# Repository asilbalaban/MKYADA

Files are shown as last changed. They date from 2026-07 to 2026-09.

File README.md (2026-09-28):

<p align="center">
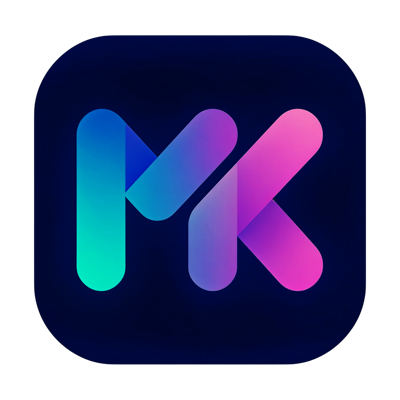
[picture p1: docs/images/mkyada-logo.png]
MKYADA logo
  
</p>

# MKYADA

**M**acro **K**eypad **Y**ou **A**lways **D**ream **A**bout — an open-source, DIY **macro keypad** (6 keys in the reference build, up to 20 supported) built on the Waveshare **RP2040-Zero**, with a cross-platform desktop configurator. It records your mouse and keyboard, then replays them as **real hardware HID input** — so your macros work even in games that ignore software automation.

**Two models, one firmware and one app:** the **Core 6** is the clean screenless keypad (RGB LED + a layer key); the **Vision 6** adds a 128×64 OLED and an EC11 rotary wheel so you can read macro names, switch layers and tune settings right on the device. See [docs/models.md](docs/models.md).

<p align="center">
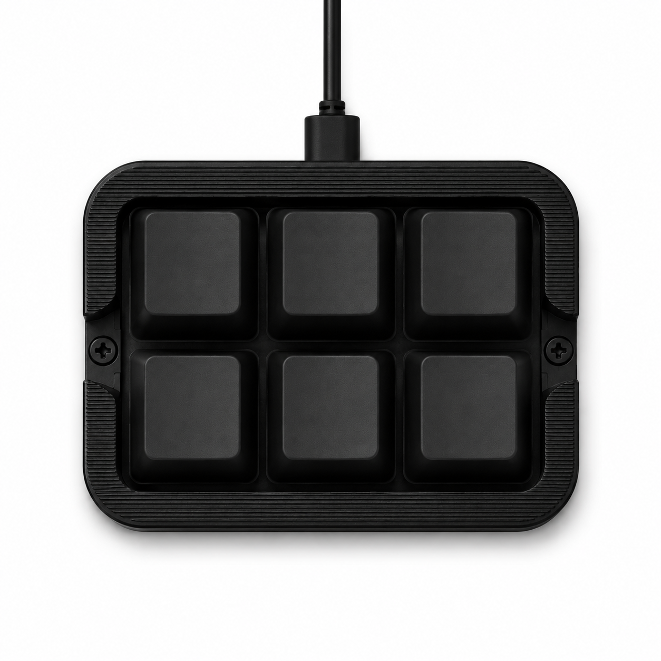
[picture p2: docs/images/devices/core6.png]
MKYADA Core 6
  
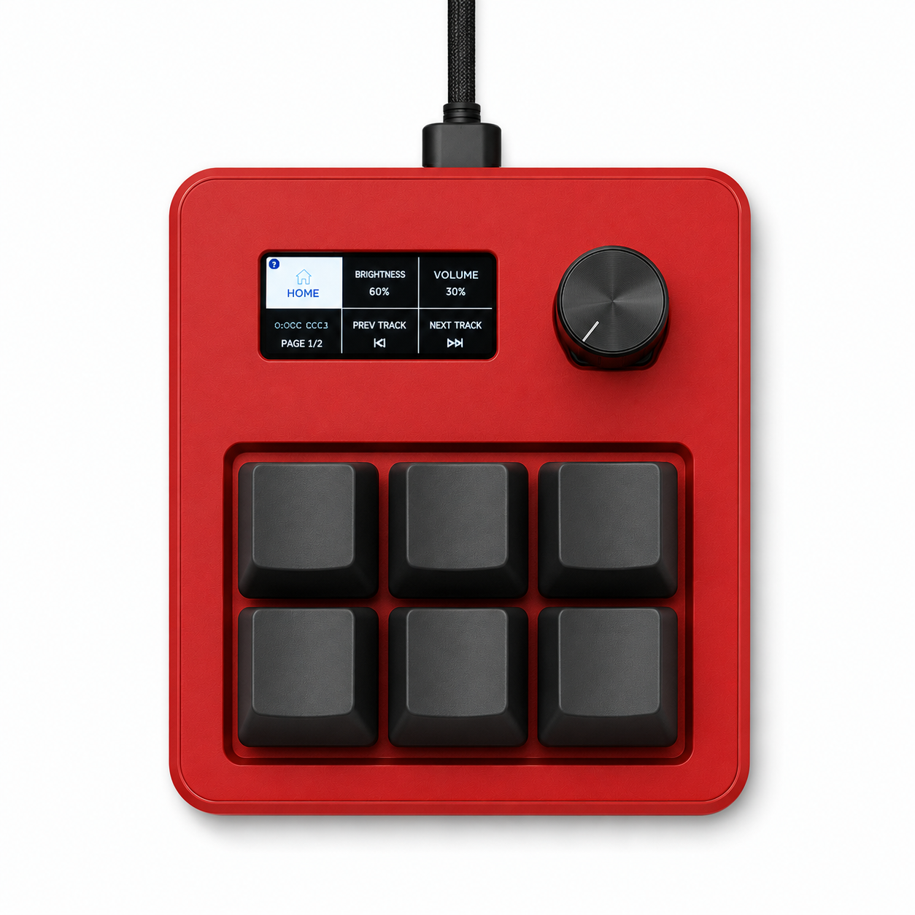
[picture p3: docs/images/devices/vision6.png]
MKYADA Vision 6 with OLED and encoder
  
</p>

```
+----------------+   serial (JSON-lines)    +---------------+    USB HID    +-----------+
|   MKYADA App   | <----------------------> |  RP2040-Zero  | ------------> |  Your PC  |
| (Tauri, W/M/L) | CIRCUITPY drive (JSON)   |   (firmware)  | kbd + mouse   |   / game  |
+----------------+ ---------------------->  +---------------+               +-----------+
```

**One repo for everything.** Build the hardware, flash the firmware, create macros, load them onto your keypad, fine-tune your recordings, and keep both the app and the firmware up to date — it all lives here.

## What do you want to do?

| I want to… | Where |
|---|---|
| **Build the keypad** (solder switches, print the case) | [hardware/wiring.md](hardware/wiring.md) · [hardware/case/](hardware/case/) |
| **Flash the firmware** on a fresh board | [docs/firmware-install.md](docs/firmware-install.md) |
| **Update the firmware** later | one click in the app (*Devices → Update firmware*) — it ships inside the app |
| **Test the keys, fix the wiring, troubleshoot** | app → *Devices*: the *Setup*, *Test keys*, *Fix wiring* and *Troubleshoot* tabs |
| **Run a key from the app, or stop a runaway loop** (also over remote desktop) | app → *Control*: click **Run** on a key, **Stop** in the bar on top, or the global stop hotkey — [remote control](#remote-control) |
| **Put an action on a key** (key, combo, text, media, launch app/file/URL, run a command, play a sound, call a webhook, or a multi-step sequence) | app → *Keys*: click the key, press the shortcut or pick an action, save |
| **Give one key three jobs** (tap / double-press / hold) | app → *Keys*: click the key, then the *Press*, *Double press* and *Long press* tabs |
| **Record a full mouse + keyboard macro** | app → *Recorder*: F8 to record, assign to a key |
| **Fine-tune a recording** | app → *Recorder*: edit every event, multi-select rows, draw the path 1:1 on your screen, pin the app above your game |
| **Different actions per application** | app → *Profiles* (e.g. Save As in Photoshop, inventory macro in your game) |
| **Configure without installing anything** | drop `macros/key1.json` onto the keypad's USB drive — [format](docs/macro-format.md) |
| **Update the app** | *Settings → About → Check for updates* (it also checks on launch) |
| **Share or grab ready-made macros** | [community-macros/](community-macros/) — PRs welcome |

## Why MKYADA?

Unlike most DIY macro pads that just remap keys, MKYADA plays back **full recorded macros — mouse movements, clicks, scrolls and keystrokes — as real hardware HID input** from the device itself. Software macro tools inject input at the OS level and often don't work inside games; MKYADA's input is indistinguishable from a physical keyboard and mouse because, electrically, that's what it is.

## Features

**On the keypad (no app needed):**
- **Standalone playback** — macros live as JSON files on the board's own USB drive. Drop `macros/key1.json` on, press the key. Works on any PC, no software installed.
- **Everything is JSON** — even a plain Ctrl+A binding is a tiny macro file. Copy it to another board and it behaves identically.
- **Tap · double-press · hold** — one key, three independently assignable actions. The firmware resolves the gesture itself, so it still works with no app running. No double-press assigned? Zero added latency on the tap.
- **Layers** — dedicate one key as a layer switch (toggle or hold): 4 keys become 3×3 = 9 macros (`key1.json`, `key1-b.json`, `key1-c.json`). A live layer badge in the app always shows which one is active. An assignable **"Go to layer X"** action jumps straight to a layer (works on the Core 6 too); the Vision 6 switches layers with the wheel, no key spent.
- **Loop mode** — `repeat: 0` plays a macro until you press its key again (grinding, fishing, inventory runs…). Same key also **panic-stops** any running macro.
- **Status LED** — the onboard RGB LED shows the active layer, playback (fast blink; slow blink while looping), host mode and errors — and can mirror app-side state like "mic muted".
- **Absolute mouse positioning** — clicks land on screen coordinates, not relative nudges, via a custom HID descriptor proven in-game.
- **Self-healing connection** — dead/reset serial ports and read-only drives are detected and recovered from automatically; nicknames are stored on the device itself so they follow it between computers.
- **MIDI out** — the keypad is a **USB MIDI device as well as a keyboard**, so a key can send a note, control change or program change straight into a DAW with nothing running on the computer. Notes are *momentary* by default (the note lasts exactly as long as the key is held — what Ableton's Looper and drum-rack pads need). A Mackie Control picker gives Logic and Pro Tools transport with no mapping at all. Nothing else at this price does both jobs: mini MIDI controllers can't send shortcuts, and stream decks can't send MIDI. Off by default — turn it on in *Settings → Keypad*.
- **Finished-product mode** — an optional setting (app → *Settings → Keypad*) hides the keypad's USB drive entirely: no flash drive, no raw JSON in sight. The app keeps full access over the serial connection. Hold key 1 while plugging in to bring the drive back.

**On the Vision 6 (screen model):**
- **On-device menu system** — a 128×64 OLED shows your six live macro names, a layer picker, a per-macro speed editor (0.1×–10.0×) and a settings menu, all driven by the **EC11 rotary wheel** with BACK/CONFIRM. No app required to read or tune your keypad.
- **Encoder + nav buttons as macro slots** — the wheel (→ / ←), its push, and BACK/CONFIRM each carry their own assignable action, per layer and per context. Great for volume, scroll/zoom or scene switching.
- **The Dial** — a key can open a **six-slot encoder toolset** on the screen: the six keys pick a slot, the wheel drives it. Slots send shortcut pairs, scroll, a relative mouse drag (for controls with no shortcut, like DaVinci's color wheels) or **MIDI CC**. Ready-made sets ship for Resolve, Premiere, Final Cut, Photoshop, Ableton, Logic, Reaper, FL Studio, a MIDI mixer and a sheet-music page turner. Fully device-native — it works with the app closed.
- **Browse and reassign on the device** — select a key and press the wheel: media and MIDI keys open a browser. Turn to walk the options (all 128 notes for MIDI), **tap to hear the highlighted one**, hold to reassign the key to it. The keypad writes its own macro, so it sticks with no app involved.
- **On-screen bands** — optional strips name the active **layer** and the desktop app's active **per-app profile**; the auto-return timeout is adjustable on the device or in the app. See [docs/vision6.md](docs/vision6.md).

**In the desktop app (Windows / macOS, Linux planned):**
- **Point-and-click key setup** — click a key, press the shortcut you want (single keys, combos, text snippets, media keys), save. *Run on keypad* tries it right away; the live key test (*Devices → Test keys*) shows every physical press.
- **Beyond keystrokes** — put a key to launching an app, file or URL, running a terminal command, playing a sound (tap to play; hold to stop, fade out, or restart it), scrolling/zooming (wheel + modifiers), controlling your microphone (mute/unmute/toggle/**push-to-talk**), driving **OBS Studio** over obs-websocket (scene, record, stream, mic, virtual cam), or calling a webhook — a fully custom HTTP request (method, headers, body) for smart lights, Discord/Telegram messages, Home Assistant and anything else with an HTTP API. Chain several of these into one multi-step sequence with delays in between. Full list: [docs/actions.md](docs/actions.md).
- **Macro recorder & editor** — record globally with F8, then edit every event: coordinates, delays, durations; straighten or simplify mouse paths; draw the path 1:1 on your real screen to verify click positions; multi-select rows with shift/cmd-click; full undo/redo.
- **Per-app profiles** — with the app running, key 1 can be *Save As* in Photoshop and an inventory macro in your game. No matching profile? The keypad falls back to its own on-board config within 5 seconds.
- **Remote control** — the *Control* page runs any key on the keypad from the app, exactly like pressing it, and a playback bar on every page stops whatever is playing. A global stop hotkey and the tray's *Stop playback* work with the window hidden. Built for driving the keypad's computer over Chrome Remote Desktop, where you can't reach the physical key. See [Remote control](#remote-control).
- **Runs in the background** — closing the window sends MKYADA to the system tray instead of quitting, so key actions and profiles keep working; an optional "start at login" setting launches it automatically.
- **Live system status** — a settings strip shows CPU, RAM and mic-mute state at a glance, with an optional rule to turn the keypad's LED red while the mic is muted.
- **In-app firmware updates**, wrong-solder-order key remapping, device nicknames, multi-device support, and a GitHub release check on launch.

## The app

| Run keys from the app (Control) | Assign keys (Vision 6) |
|---|---|
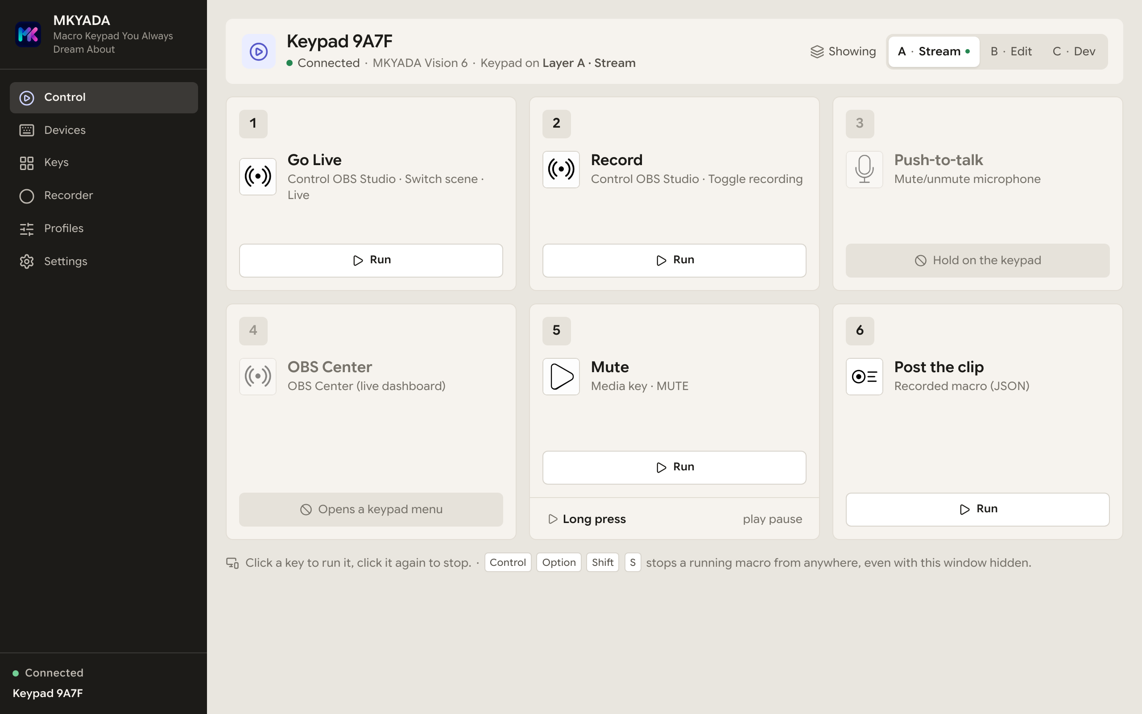
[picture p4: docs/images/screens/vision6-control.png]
Control page — every key as a tile with Run, the page the app opens on
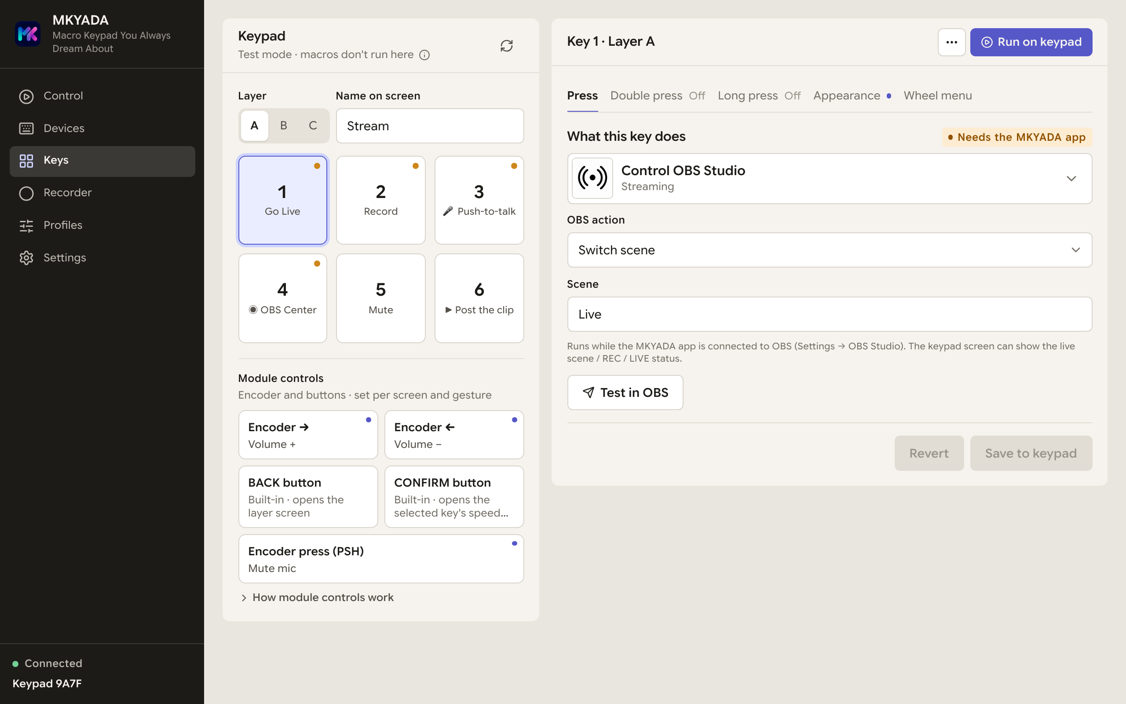
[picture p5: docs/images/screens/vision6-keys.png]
Keys page — click a key, then Press, Double press, Long press and Appearance tabs
|  |  |
| **Stop a loop from anywhere** | **Per-app profiles** |
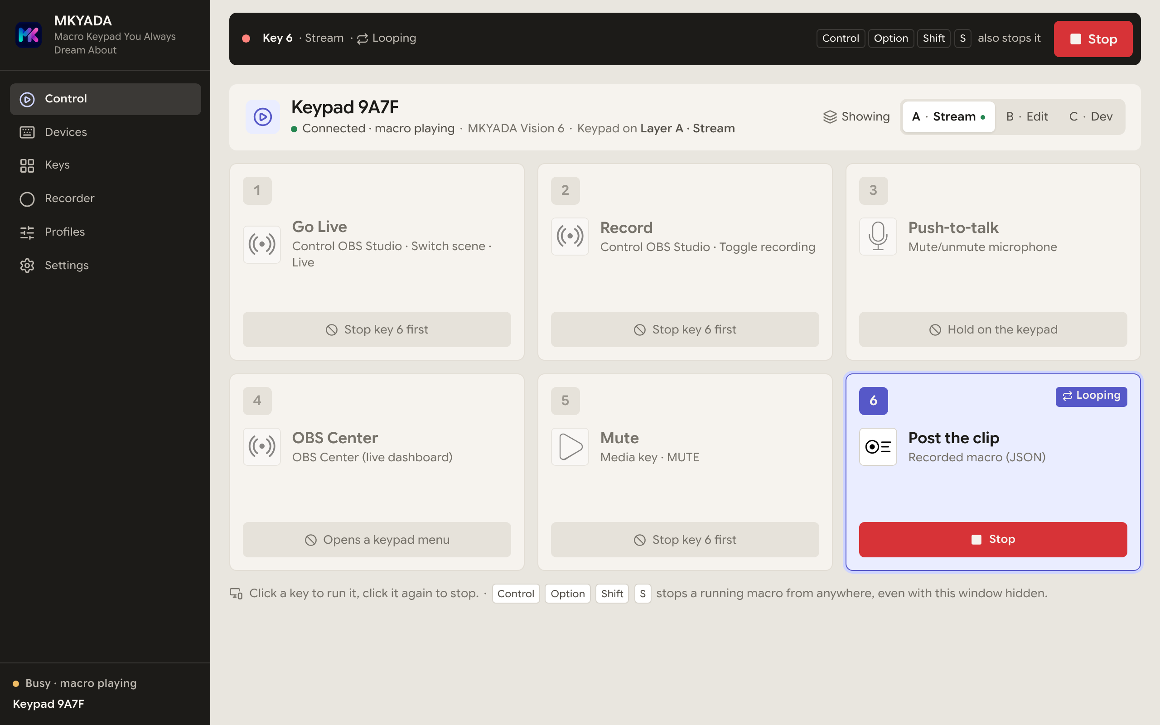
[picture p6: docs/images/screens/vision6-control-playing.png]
Control page while key 6 loops — the playback bar on top with Stop and the stop hotkey
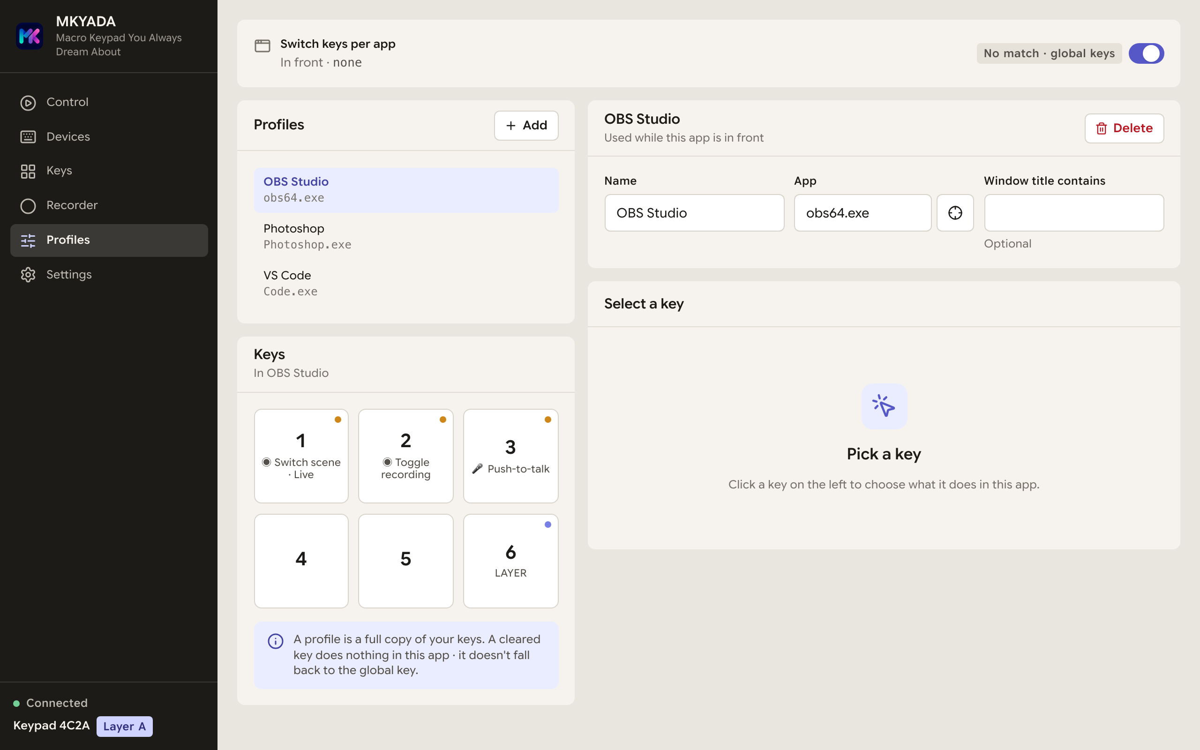
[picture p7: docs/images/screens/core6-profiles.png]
Profiles — the app in front picks the keys; each profile has its own key grid
|  |  |
| **Record & edit macros** | **Devices — setup, key test, wiring, troubleshooting** |
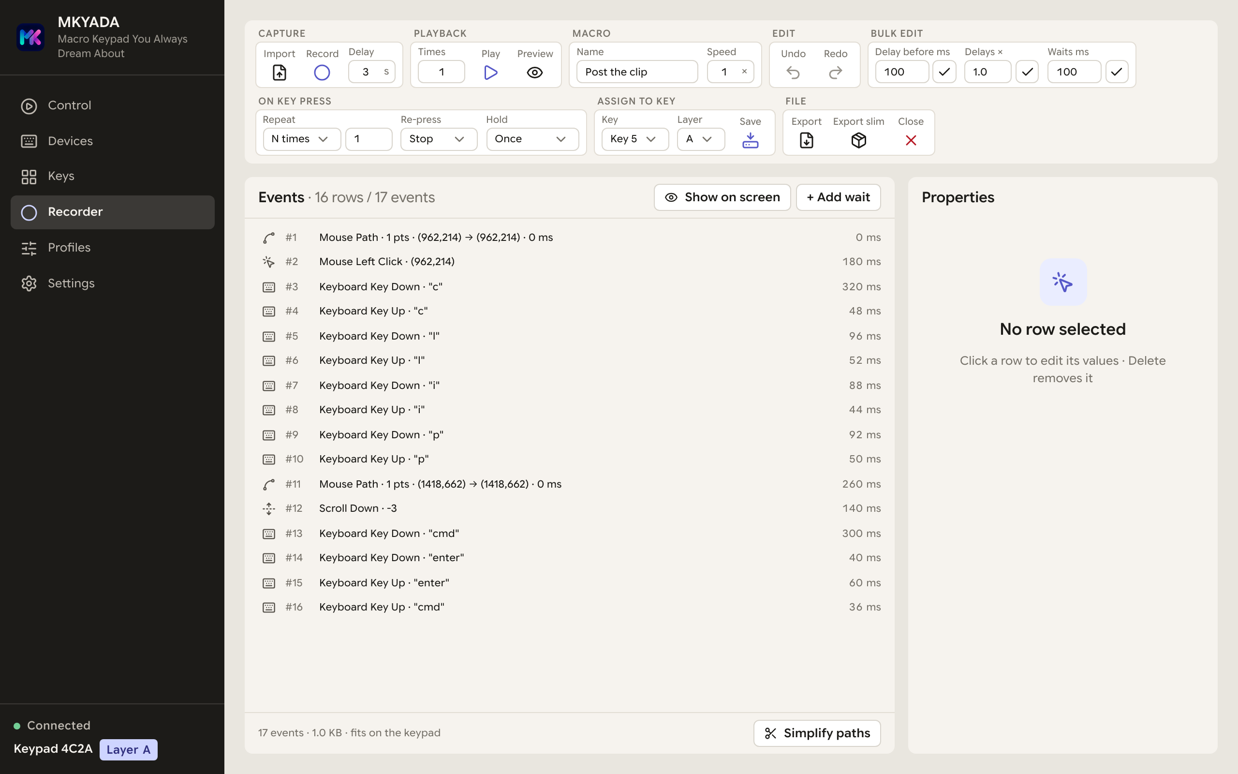
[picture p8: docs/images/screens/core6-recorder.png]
Recorder — every event is an editable row, playback rules per key
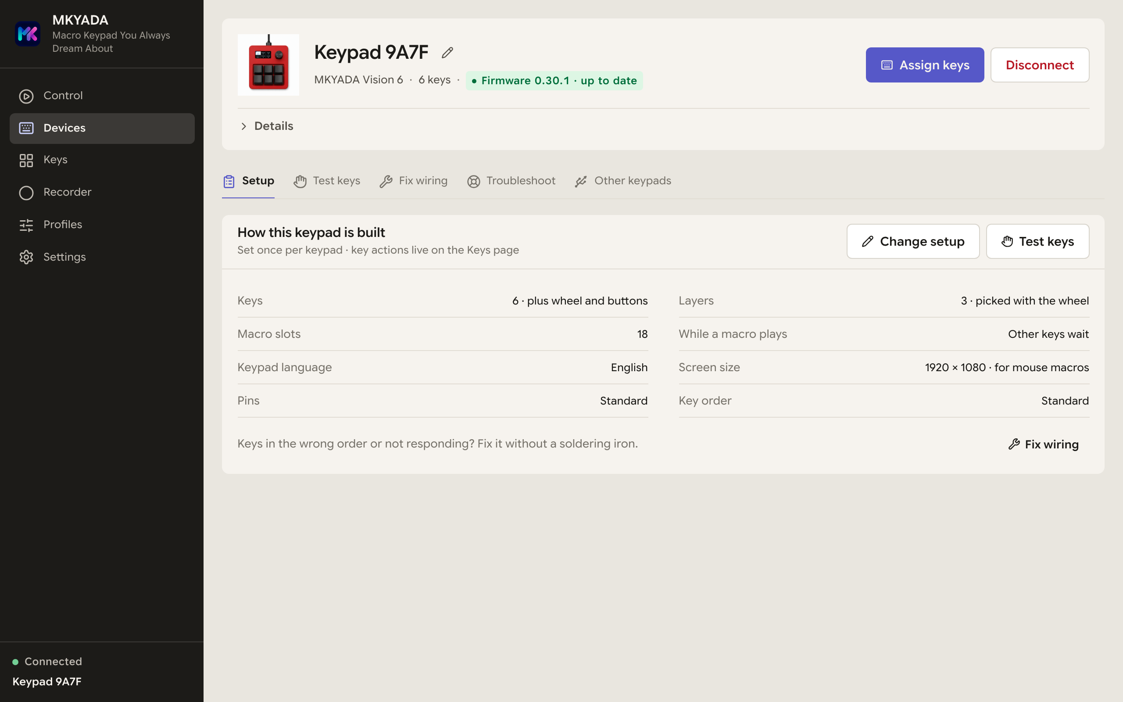
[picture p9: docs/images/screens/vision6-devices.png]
Devices page — keypad hero card with Setup, Test keys, Fix wiring, Troubleshoot and Other keypads tabs
|  |  |
| **Test every key** | **Settings — grouped into tabs** |
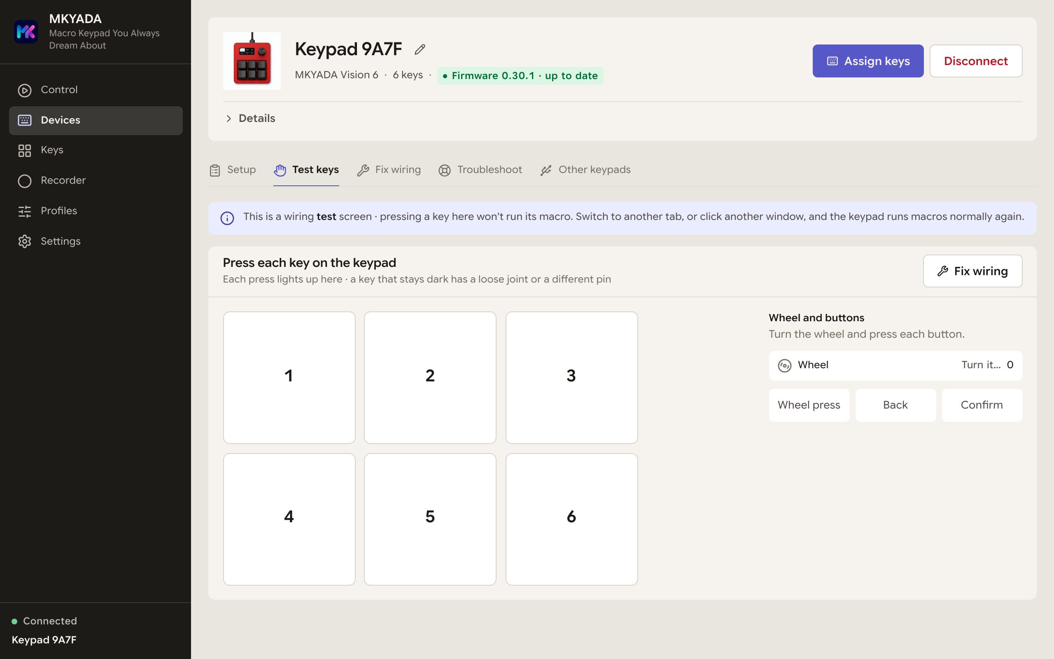
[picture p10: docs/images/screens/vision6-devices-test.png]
Devices → Test keys — each press lights up its tile
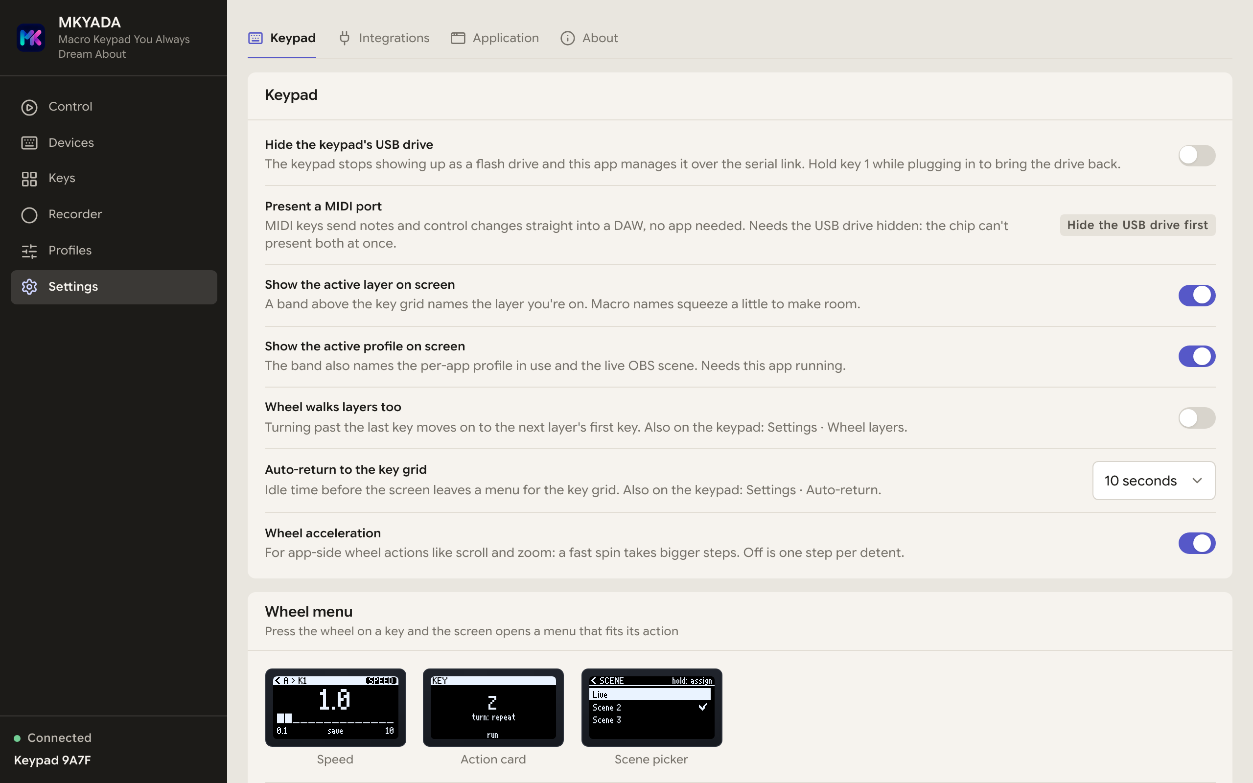
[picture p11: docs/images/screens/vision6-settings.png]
Settings — Keypad, Integrations, Application and About in tabs
|  |  |

## Remote control

A lot of MKYADA keypads sit on a computer their owner reaches over **Chrome
Remote Desktop** (or any remote desktop): a game or render box running a macro
on loop. From there you can't press the physical key, so a loop you started
would run forever. The app covers that:

- **Control page** — the first page, and the one the app opens on. Every key is
  a large tile; **Run** presses that key on the keypad remotely, exactly like a
  physical press (same macro, same loop and hold rules, still real hardware
  HID). The playing tile turns into **Stop**. Keys with a double or long press
  get their own rows, and a layer switcher shows the other layers.
- **Playback bar** — while anything plays, a bar on every page shows the key,
  its layer and whether it loops, with a **Stop** button. After a stop it offers
  **Run again**.
- **Global stop hotkey** — **Ctrl+Alt+Shift+S** by default, working with the
  window hidden or in the tray. Change it in *Settings → Application → Remote
  control*.
- **Tray** — the tray menu has **Stop playback**.
- **Paused during remote desktop** — while someone is connected over Chrome
  Remote Desktop, no macro plays (a running one stops, keys and *Run* are
  held), so the computer stays usable. When the session ends, the macro the
  connection stopped starts again. During the session, **Run** picks the key to play once it ends instead (or **Stop** to play nothing). Turn it off in *Settings → Application →
  Remote control*.

Remote run and stop need a keypad on the current firmware (serial protocol
v17); on older firmware the Control page asks for an update. The
[serial protocol](docs/serial-protocol.md) documents `press`, `stop` and the
`play_start` / `play_done` events.

The Vision 6's own OLED screens. These are not mockups: `scripts/render-oled.py`
runs the firmware's drawing code over the font the device flashes, so every lit
pixel here is a pixel the SH1106 lights. The whole menu also runs in a browser —
open [`docs/simulator.html`](docs/simulator.html) to drive the keys, wheel and
buttons without a board, browse the 270-icon family, and inspect the font. That
page draws with the app's own modules (`app/src/lib/oled-*.ts`, bundled in by
`scripts/build-demo.mjs`), and those are held to the firmware's pixels by
`tests/golden/*.txt` — so the browser, the desktop app and the keypad cannot
show three different menus.

<p align="center">
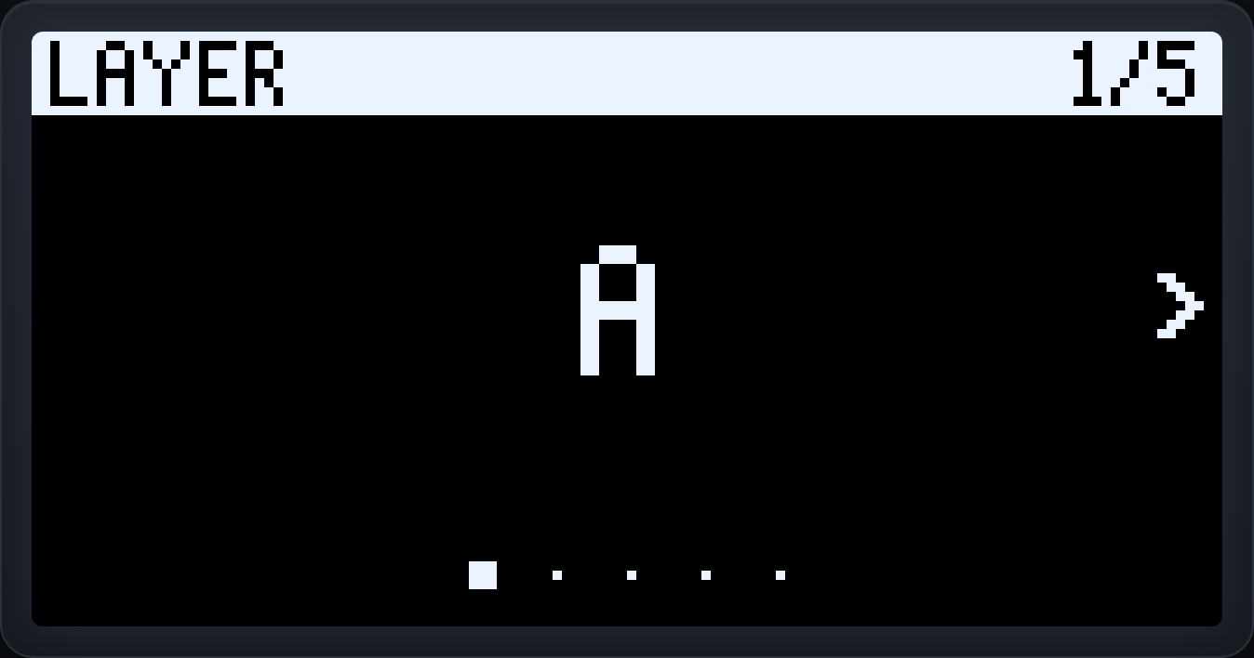
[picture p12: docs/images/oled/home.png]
Vision 6 Home
  
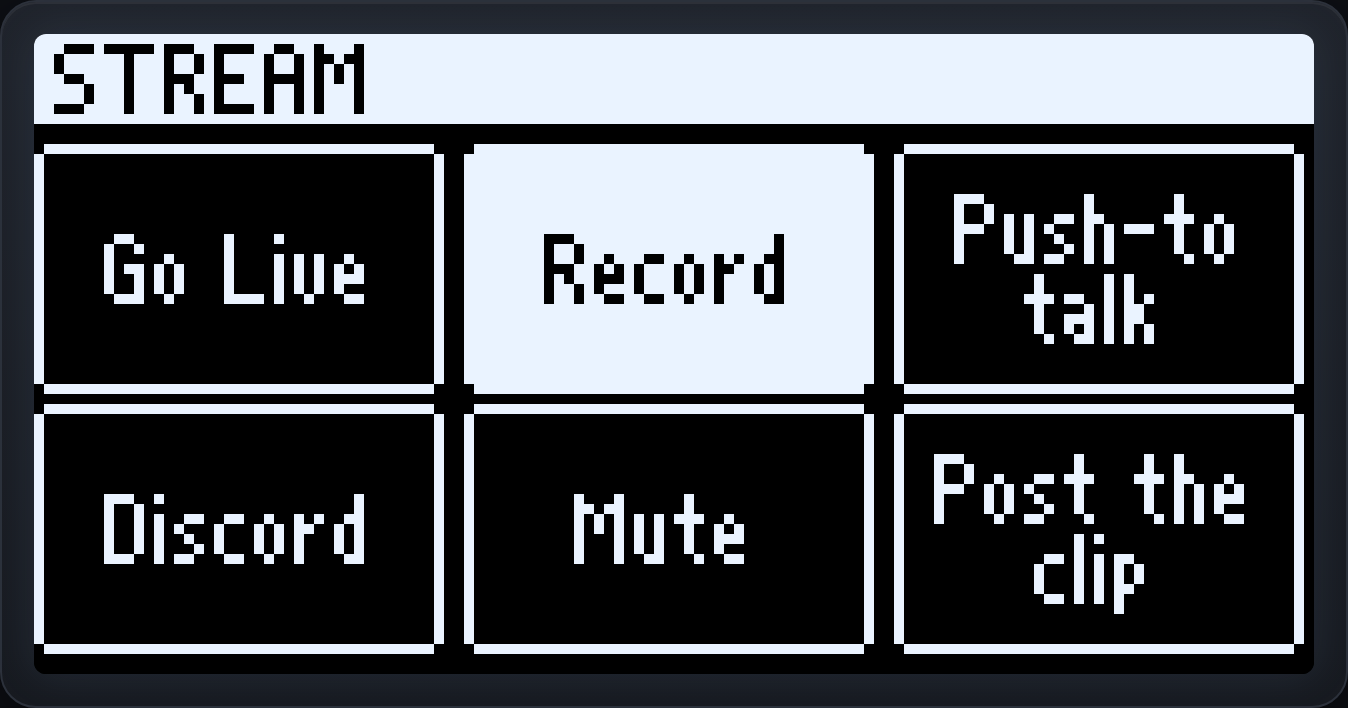
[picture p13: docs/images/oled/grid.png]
Vision 6 Grid
  
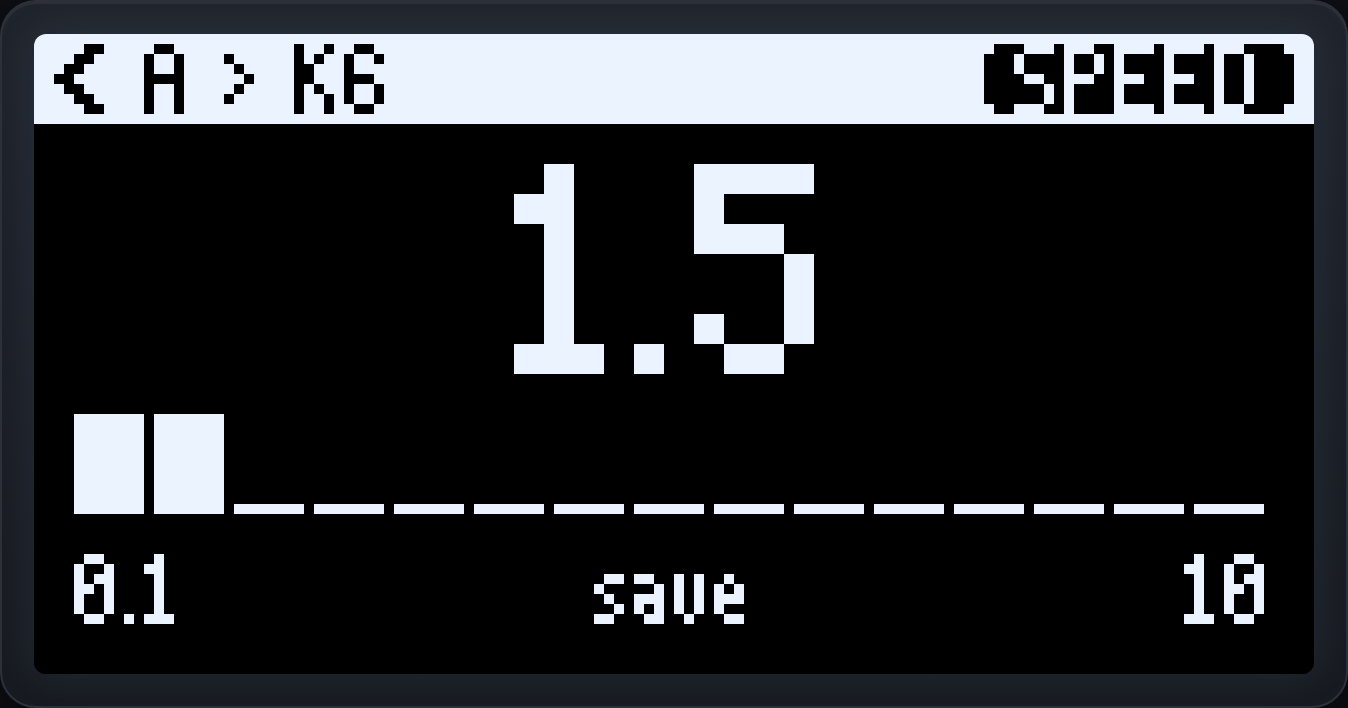
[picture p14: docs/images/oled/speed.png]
Vision 6 Speed editor
  
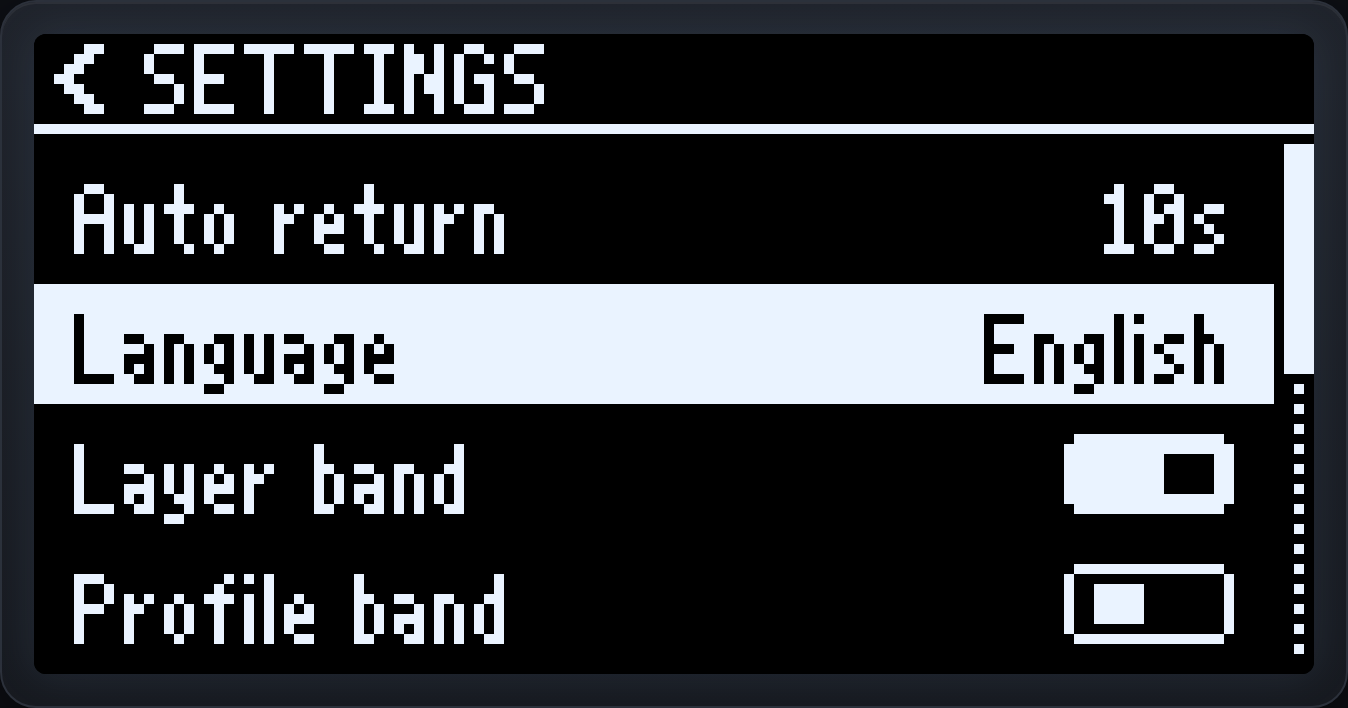
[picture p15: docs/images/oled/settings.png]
Vision 6 Settings
  
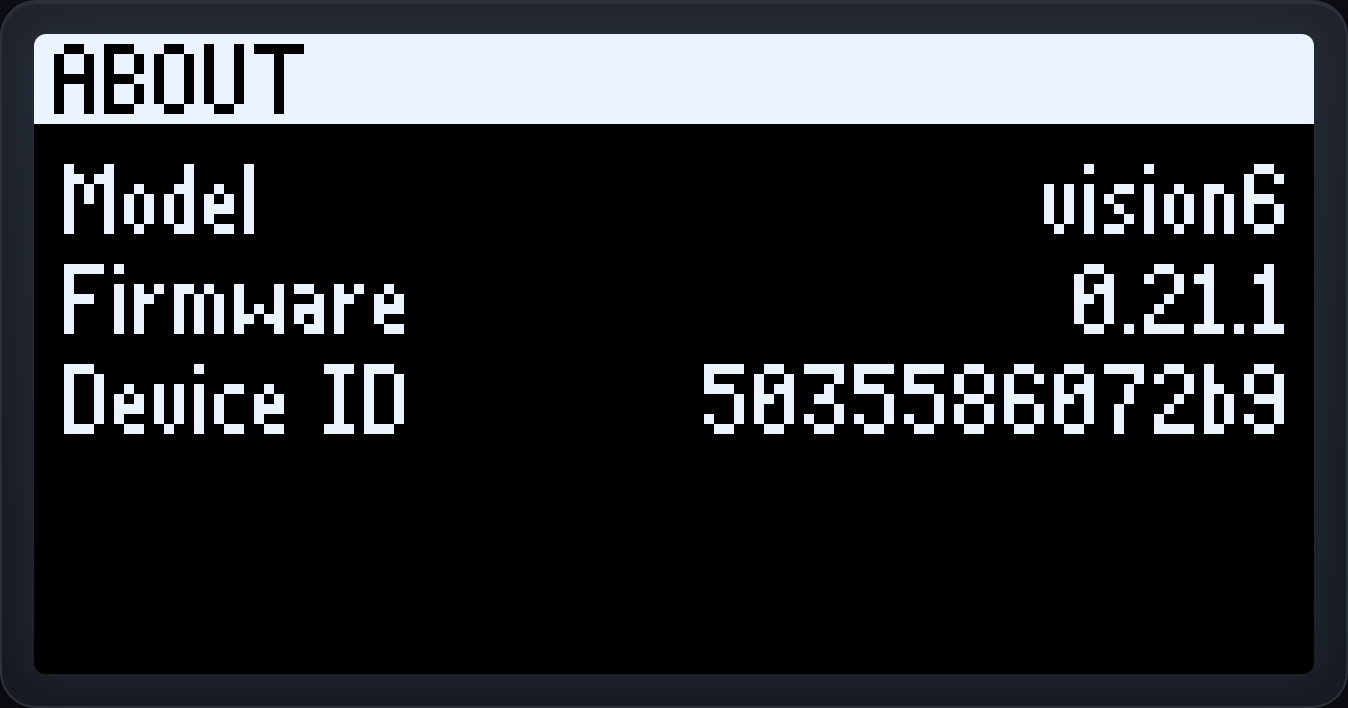
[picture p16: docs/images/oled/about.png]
Vision 6 About
  
</p>
<p align="center">
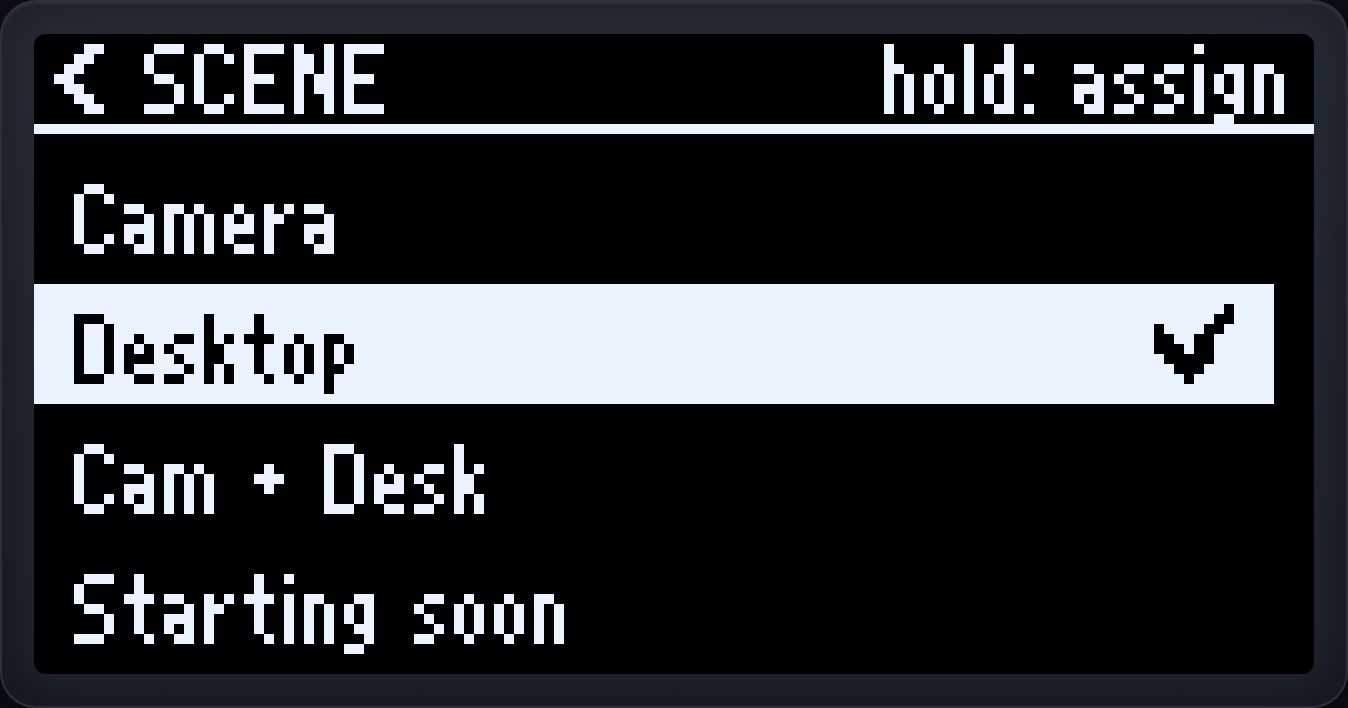
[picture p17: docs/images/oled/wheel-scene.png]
Vision 6 OBS scene picker
  
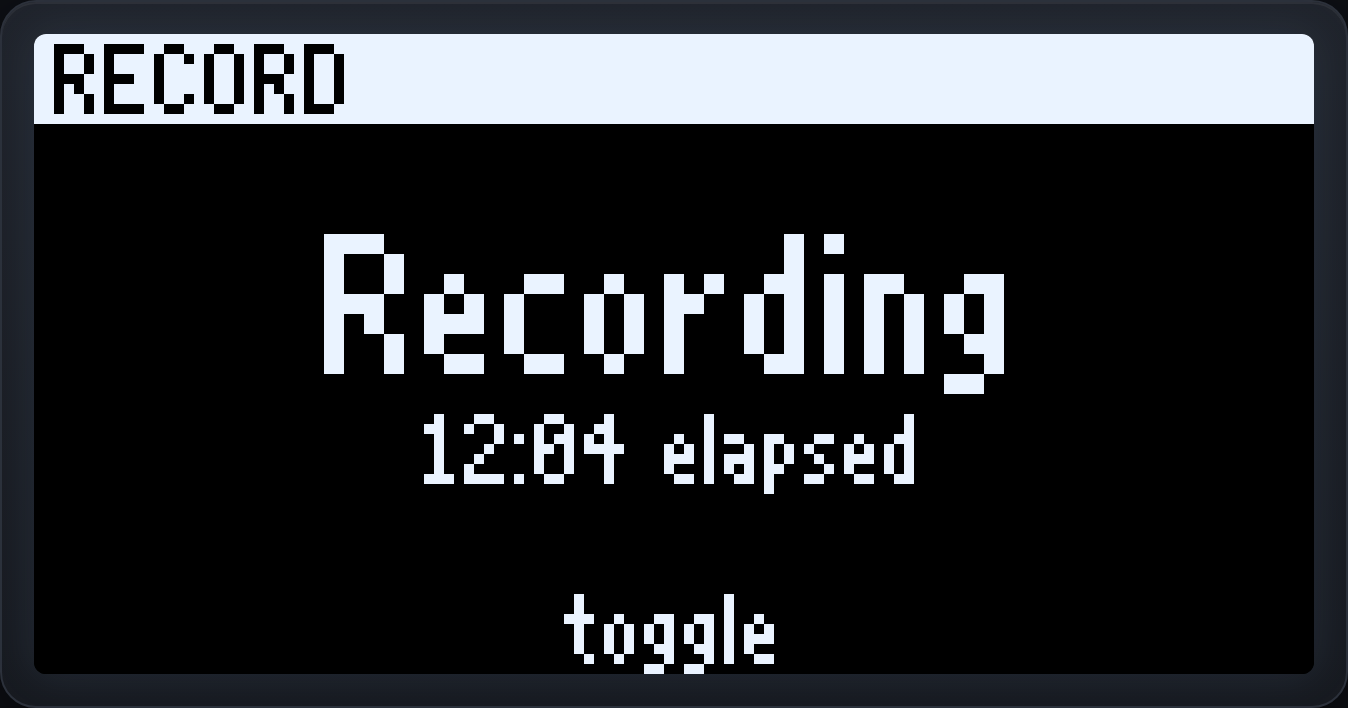
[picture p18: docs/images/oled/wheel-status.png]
Vision 6 record status card
  
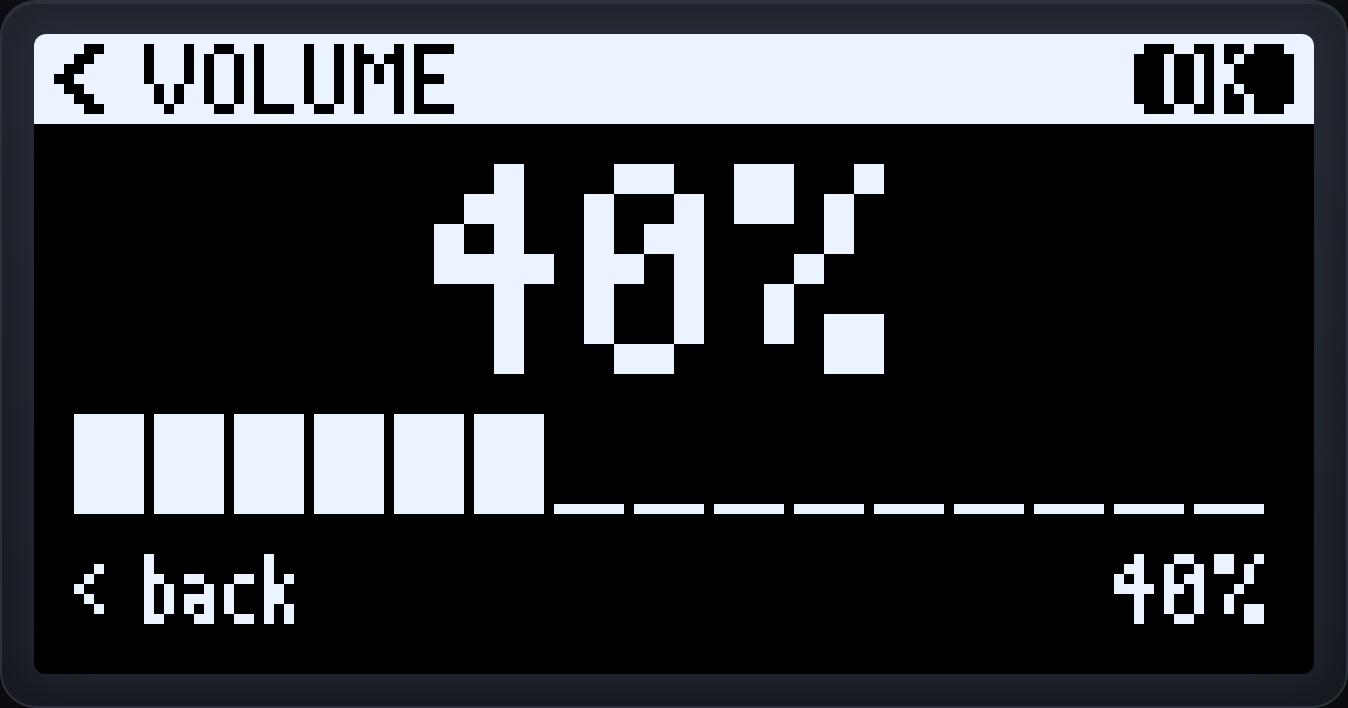
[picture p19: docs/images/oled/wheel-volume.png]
Vision 6 volume slider
  
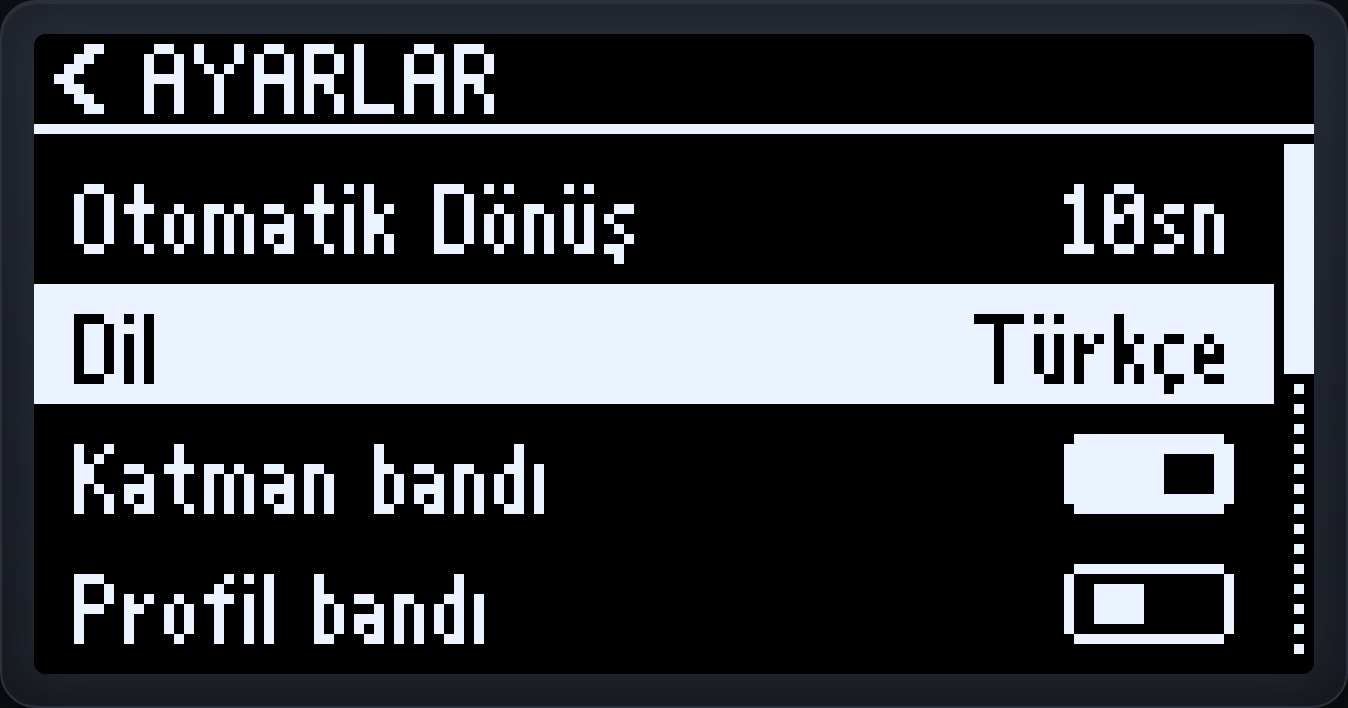
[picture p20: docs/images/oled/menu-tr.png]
Vision 6 menu in Turkish
  
</p>

## Hardware

| Component | Details |
|---|---|
| Microcontroller | [Waveshare RP2040-Zero](https://www.waveshare.com/wiki/RP2040-Zero) — dual-core Cortex-M0+ @ 133 MHz, 264 KB RAM, 2 MB flash, USB-C |
| Firmware | [CircuitPython](https://circuitpython.org/board/waveshare_rp2040_zero/) 10.x + MKYADA firmware ([firmware/](firmware/)) |
| Switches | 1–20 × Cherry MX-compatible (6 = reference build), one leg each to **GP0, GP1, GP2…** in key order, other legs daisy-chained to a common **GND** — no diodes, no resistors |
| Status LED | onboard WS2812 (GP16), nothing to wire |
| Screen (Vision 6) | SH1106 **128×64 OLED** (I²C, 3V3) + **EC11 rotary encoder** with push + BACK/CONFIRM buttons — wiring in [docs/vision6.md](docs/vision6.md) |
| Case | 3D-printed **Stream Cheap** remix — STLs + print notes in [hardware/case/](hardware/case/) |

<p align="center">
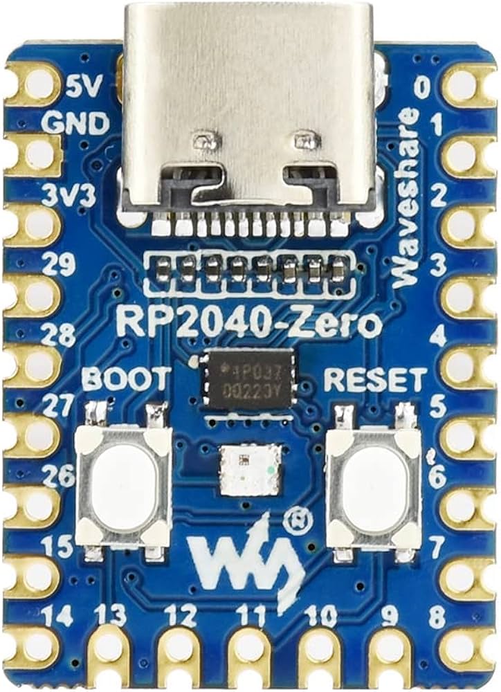
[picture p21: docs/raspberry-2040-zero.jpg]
Waveshare RP2040-Zero — key pins GP0-GP8 down the right edge, GND on the upper left
  
</p>

Full soldering walkthrough with the board pinout: **[hardware/wiring.md](hardware/wiring.md)**. Any key count from 1 to 20 works — the setup wizard adapts. Soldered the keys in the wrong order? The app remaps them in software.

## How it works

- **Standalone mode** (default): the keypad reads `config.json` + `macros/keyN.json` from its own `CIRCUITPY` drive and plays macros through its USB HID interfaces. The desktop app is a *configurator*, not a runtime.
- **Host mode**: while the desktop app is running and a per-app profile matches, key presses stream to the app over serial (JSON-lines) and the app decides what to play — **still through the keypad's hardware HID**. If the app disappears, a 5-second watchdog returns the keypad to standalone.
- **Bulk data never crosses the serial port** — the app writes macro/config files to the USB drive (the same path as configuring by hand), then tells the firmware to reload.

Details: [docs/macro-format.md](docs/macro-format.md) · [docs/serial-protocol.md](docs/serial-protocol.md)

## Quick start

1. **Install the app** from the [latest release](https://github.com/asilbalaban/MKYADA/releases/latest) (Windows `setup.exe`, macOS universal `.dmg`).
2. **Set up the board — one click.** Plug a blank RP2040-Zero in with **BOOT** held and open **Devices → Other keypads → Set up a new board**: the app flashes CircuitPython, installs the MKYADA firmware and writes a starter config for your model (Core 6 or Vision 6) — no manual UF2 copying, no tools. *(Already flashed, or prefer to do it by hand? The [manual steps](docs/firmware-install.md) still work — copy the `mkyada-firmware-*.zip` contents onto the `CIRCUITPY` drive.)*
3. **Assign keys** on the **Keys** page — **or** skip the app entirely and copy macro JSON files onto the drive by hand.
4. **Press a key**, or click **Run** on the **Control** page.

> **macOS:** the app is not notarized, so the first launch is blocked with
> *"Apple could not verify MKYADA…"*. Clear the quarantine flag once and open
> it normally:
>
> ```sh
> xattr -cr /Applications/MKYADA.app
> ```
>
> (Alternative: System Settings → Privacy & Security → **Open Anyway**.
> Details in [docs/macos-install.md](docs/macos-install.md).)
>
> Granted **Input Monitoring**/**Accessibility** but the app still shows
> **DENIED**? Each unsigned build gets a new code signature, so macOS ties
> the permission to the old one. Reset it and grant again:
> [docs/macos-install.md#permission-shows-on-but-the-app-still-says-denied](docs/macos-install.md#permission-shows-on-but-the-app-still-says-denied)

## Repository layout

| Path | What it is |
|---|---|
| [app/](app/) | Desktop configurator — Tauri v2, React + TypeScript frontend, Rust backend |
| [firmware/](firmware/) | CircuitPython firmware for the RP2040-Zero |
| [hardware/](hardware/) | [Soldering guide](hardware/wiring.md) + [3D-printable case](hardware/case/) |
| [docs/](docs/) | [Models](docs/models.md) · [Key actions](docs/actions.md) · [Use cases](docs/use-cases.md) · [Vision 6](docs/vision6.md) · [Macro format](docs/macro-format.md) · [Serial protocol](docs/serial-protocol.md) · [Firmware install](docs/firmware-install.md) · [macOS install](docs/macos-install.md) |
| [community-macros/](community-macros/) | Macro gallery — contributions welcome via PR |
| [tests/](tests/) | Firmware simulation tests + editor model tests (run in CI) |

## Building from source

```sh
# App (needs Node 20+ and Rust)
cd app && npm install && npm run tauri dev

# Tests
python3 tests/firmware_sim_test.py
npx tsx tests/model_test.ts
```

## Status

**v0.21.x** — two hardware models (**Core 6** screenless, **Vision 6** OLED + encoder) on one firmware and one app, verified on real hardware. A themed app with onboarding, press-to-capture key assignment, a full macro recorder/editor with on-screen path overlay and undo/redo, per-app profiles that run **natively on the device** (a full config copy), and a broad key-action set: keystroke/combo/text/media, mouse scroll & zoom, launch/command/sound, microphone (incl. push-to-talk), **OBS Studio** control, webhooks, multi-step sequences, and "go to layer X". Tap/double-press/hold key logic with playback policies (stop/restart, hold-to-repeat, loop). Vision 6 adds an on-device menu (layer picker, per-macro speed editor, settings), on-screen layer/profile bands, and encoder/nav-button macro slots. A provisioning wizard flashes blank RP2040-Zero boards; firmware updates are one-click and unbrickable (rescue console, locked update mode). System tray + autostart, full keyboard-layout awareness (Turkish and any other layout), in-app firmware updates and release checks. CI publishes a Windows installer + macOS universal DMG per release; Linux packages are next.

> **Note:** automating input in online games may violate their Terms of Service. You are responsible for how you use this device.

---

## Credits

The 3D-printed case is a **Stream Cheap** remix — huge thanks to the makers:

- [Stream Cheap (Mini Macro Keyboard)](https://www.printables.com/model/157035-stream-cheap-mini-macro-keyboard) by **dmadison** — the original design.
- [Stream Cheap 3x2 RP2040 Zero](https://www.printables.com/model/989881-stream-cheap-3x2-rp2040-zero) by **schichtbude** — the RP2040-Zero fork whose body we print.
- [Stream Cheap (3x2, 4x2, 5x2) Remixed with reset button](https://www.thingiverse.com/thing:4497991) by **hartk1213** (CC BY 4.0) — source of the 3×2 face plate. Tip: scale the plate's thickness up ~20% in your slicer; it's a little thin as published.

STLs and print notes live in [hardware/case/](hardware/case/).

## Türkçe

**MKYADA** (Macro Keypad You Always Dream About), Waveshare RP2040-Zero üzerine kurulu, açık kaynak, kendin-yap bir makro klavyedir (referans tasarım 6 tuş, 20 tuşa kadar desteklenir) ve çok platformlu bir masaüstü yapılandırma uygulamasıyla gelir.

**İki model, tek bellenim ve tek uygulama:** **Core 6** sade, ekransız klavye (RGB LED + katman tuşu); **Vision 6** ise 128×64 OLED ve EC11 döner tekerlek ekler; böylece makro adlarını okuyup katman değiştirir ve ayarları doğrudan cihaz üzerinde yaparsınız. Ayrıntı: [docs/models.md](docs/models.md).

**Macro oluşturmak, keypad'inize yüklemek, kaydettiğiniz makroyu düzenlemek, sürüm güncellemek — her şey için ihtiyacınız olan tek repo burası:** donanımı kur ([hardware/](hardware/)), firmware'i yükle/güncelle (uygulamadan tek tık), tuşlara aksiyon ata (*Keys*), makro kaydet ve ince ayar yap (*Recorder*), uygulamaya özel profiller kur (*Profiles*), hazır makroları paylaş ([community-macros/](community-macros/)).

Çoğu DIY makro pad sadece tuş atar; MKYADA ise kaydedilmiş **mouse hareketleri + tıklamalar + tuş vuruşlarını gerçek donanım HID girdisi olarak** kartın kendisinden oynatır. Yazılımsal makro araçları girdiyi işletim sistemi seviyesinde enjekte ettiği için oyunlarda çoğu zaman çalışmaz; MKYADA'nın girdisi elektriksel olarak gerçek bir klavye/mouse olduğundan ayırt edilemez.

**Donanım:** Waveshare RP2040-Zero (USB-C) + 1–20 mekanik switch (referans tasarım 6 tuş). Her switch'in bir bacağı sırasıyla **GP0…GP5**'e, diğer bacağı **ortak GND** zincirine lehimlenir — diyot/direnç yok. Kart üzerindeki RGB LED durum ışığıdır. Lehim rehberi (fotoğraflı, Türkçe özetli): [hardware/wiring.md](hardware/wiring.md) · 3D baskı kutu: [hardware/case/](hardware/case/).

- **Uygulamasız çalışır** — `key1.json` dosyasını kartın USB sürücüsüne at, tuşa bas.
- **Her şey JSON** — basit bir Ctrl+A ataması bile küçük bir makro dosyasıdır; başka karta kopyalayınca aynı davranır.
- **Tek dokunuş · çift · basılı tut** — aynı tuşa üç ayrı, bağımsız atanabilir aksiyon; bellenim jesti kendisi çözer, uygulama açık olmasa bile çalışır.
- **Layer desteği** — bir tuşu layer anahtarı yap: 4 tuş → 3×3 = 9 makro. Uygulamadaki canlı rozet o an hangi layer'da olduğunuzu gösterir.
- **Döngü modu** — `repeat: 0` ile makro, tuşa tekrar basılana kadar çalar; aynı tuş çalan makroyu anında durdurur (panik durdurma).
- **Uygulamaya özel profiller** — masaüstü uygulaması açıkken tuş 1 Photoshop'ta *Save As*, oyunda envanter makrosu olabilir.
- **Tuş vuruşunun ötesinde** — bir tuşu uygulama/dosya/URL açmaya, terminal komutu çalıştırmaya, ses çalmaya (basılı tutunca durdur/kıs/baştan başlat), kaydırma & yakınlaştırmaya, mikrofon kontrolüne (sustur/aç/değiştir/**bas-konuş**), **OBS Studio** kontrolüne (sahne, kayıt, yayın, mikrofon) ya da webhook'a atayın; birkaçını aralarında bekleme ile zincirleyerek tek bir çok adımlı aksiyon yapın. Tüm liste: [docs/actions.md](docs/actions.md).
- **Vision 6 ekranı** — 128×64 OLED'de canlı makro adları, katman seçici, makro başına hız ayarı ve ayarlar menüsü; hepsi döner tekerlekle. Encoder ve BACK/CONFIRM tuşları da kendi makrolarını taşır. Ayrıntı: [docs/vision6.md](docs/vision6.md).
- **Kaydet & düzenle** — klavye + mouse kaydı, event bazında düzenleme, çoklu satır seçimi, geri al/ileri al, mouse yolunu gerçek ekranda 1:1 çizme, hız / tekrar ayarı.
- **Uzaktan kontrol** — *Control* sayfası herhangi bir tuşu uygulamadan, fiziksel basışla birebir aynı şekilde çalıştırır; her sayfadaki oynatma çubuğu, genel durdurma kısayolu (varsayılan **Ctrl+Alt+Shift+S**) ve tepsideki *Stop playback* çalan makroyu durdurur. Chrome Remote Desktop bağlantısı açık olduğu sürece makro oynatılmaz; bağlantı kesilince durdurulan makro yeniden başlar. Chrome Remote Desktop ile bağlanıp fiziksel tuşa uzanamayanlar için.
- **Arka planda çalışır** — pencereyi kapatmak uygulamayı kapatmaz, sistem tepsisine gönderir; tuş aksiyonları ve profiller çalışmaya devam eder. İsteğe bağlı "açılışta başlat" seçeneği de var.
- **Kendin yap** — 6 switch'i RP2040-Zero'ya lehimle, kutuyu 3D yazıcıda bas, firmware'i yükle.

Kurulum: RP2040-Zero'ya CircuitPython yükleyin, firmware release zip içeriğini `CIRCUITPY` sürücüsüne kopyalayın ([docs/firmware-install.md](docs/firmware-install.md)), uygulamayı [son sürümden](https://github.com/asilbalaban/MKYADA/releases/latest) kurun veya JSON dosyalarını elle sürücüye atın.

> **Not:** Çevrimiçi oyunlarda girdi otomasyonu oyunun kullanım koşullarını ihlal edebilir. Cihazı nasıl kullandığınızın sorumluluğu size aittir.

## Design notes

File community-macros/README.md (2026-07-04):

# Community macros

Share your MKYADA macros! Open a pull request adding a `.json` file
(format: [docs/macro-format.md](../docs/macro-format.md)) with a short
description in this table.

Import a macro via the app (**Recorder → Import JSON…** or assign it directly
on the **Keys** page), or copy it straight to the board's `macros/` folder as
`key<N>.json`.

| File | What it does | Author |
|---|---|---|
| [inventory-plus-template.json](inventory-plus-template.json) | Template: click an inventory slot, press +, repeat until stopped | @asilbalaban |

> Coordinates in recorded macros are resolution-dependent — check the macro's
> `screen` field matches your display, or re-record with your own layout.

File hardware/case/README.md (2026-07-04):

# 3D-printed case

The MKYADA case is a remix of the wonderful **Stream Cheap** design — we did
not draw these models, we stand on the shoulders of the makers credited below.

## Files in this folder

| File | What it is | Source |
|---|---|---|
| `Stream Cheap RP2040.stl` | Case body (3×2), USB-C cutout for the RP2040-Zero | [Stream Cheap 3x2 RP2040 Zero](https://www.printables.com/model/989881-stream-cheap-3x2-rp2040-zero) by **schichtbude** |
| `FacePlate_3x2.stl` | 3×2 face plate (cover) | [Stream Cheap (3x2, 4x2, 5x2) Remixed](https://www.thingiverse.com/thing:4497991) by **hartk1213** (CC BY 4.0) |

## Credits

1. **[Stream Cheap (Mini Macro Keyboard)](https://www.printables.com/model/157035-stream-cheap-mini-macro-keyboard)** by **dmadison** —
   the original design this whole family of cases comes from.
2. **[Stream Cheap 3x2 RP2040 Zero](https://www.printables.com/model/989881-stream-cheap-3x2-rp2040-zero)** by **schichtbude** —
   the fork we actually print: the body is adapted to the RP2040-Zero board
   MKYADA uses.
3. **[Stream Cheap (3x2, 4x2, 5x2) Remixed with reset button](https://www.thingiverse.com/thing:4497991)** by **hartk1213** (CC BY 4.0) —
   we use the **3×2 face plate** from this remix.

License terms for the Printables models are on their linked pages; the STLs
are redistributed here with attribution to make building a MKYADA one-stop.

## Print notes (from our build)

- **The face plate is a bit thin as published — scale its Z (thickness) up by
  20% in your slicer** before generating G-code. We printed it as-is first and
  recommend the thicker version.
- Body prints fine with stock settings (0.2 mm layers, no supports needed for
  the 3×2 body when printed open-side up).
- Switches: Cherry MX-compatible, friction-fit into the face plate.
- Wiring goes through the body to the RP2040-Zero — see
  [../wiring.md](../wiring.md).

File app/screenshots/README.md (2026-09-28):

# Screenshot harness

Automated, hardware-free screenshots of every app screen for the docs pages and
the landing site — for **both** models (Core 6 and Vision 6), plus the Vision 6's
on-device OLED screens rendered by the firmware itself.

## Run

```bash
cd app
npx playwright install chromium   # one-time
npm run screenshots
```

Output:

- `docs/images/screens/<model>-<page>.png` for `core6` and `vision6`:
  - `-control` (the page the app opens on) and `-control-playing` (booted with
    `?playing=6`, so key 6 loops and the PlaybackBar is up);
  - `-devices` plus one shot per Devices tab: `-devices-test`,
    `-devices-wiring`, `-devices-troubleshoot`, `-devices-others`;
  - `-keys` (key 1 open in the tabbed editor), `-recorder` (a recorded macro
    in the editor), `-profiles` (a profile selected, so its key grid shows);
  - `-settings` plus `-settings-integrations`, `-settings-app`,
    `-settings-about`;
  - `-wizard` (the provisioning wizard on Devices → Other keypads).

  A tabbed page's first tab keeps the plain `<model>-<page>` name the docs link
  to; the rest are `<model>-<page>-<tab id>`.
- `docs/images/oled/<screen>.png` — the device screens.

The harness starts its own Vite on port 1420, the app's dev port. If a dev
server is already running there, pick another port:

```bash
SCREENSHOT_PORT=1430 npm run screenshots
```

## How it works

The app is a Tauri desktop app: the frontend calls a Rust backend over
`invoke()` and can't render without it. Instead of driving a real device, the
harness boots the **Vite dev server** against a mock:

- [`mock-tauri.ts`](mock-tauri.ts) installs `window.__TAURI_INTERNALS__` via the
  official `@tauri-apps/api/mocks` and answers every `invoke()` with fixture
  data — a single keypad that auto-connects on launch.
- [`fixtures.ts`](fixtures.ts) builds a fully-populated Core 6 / Vision 6 config
  and compiles its key macros through the **same** compiler the app uses
  (`compileAssignment` / `serializeForDevice`), so the mocked drive serves
  exactly what a real device would.
- [`entry.html`](entry.html) loads the mock **before** `/src/main.tsx`, so the
  app's top-level `getCurrentWindow()` finds the internals it needs.
- [`capture.mjs`](capture.mjs) starts Vite, drives each screen with Playwright,
  and writes the PNGs. The Recorder shot arrives through the Keys page's "Edit
  in Recorder" button, so the editor is photographed with a macro in it rather
  than showing its empty state.

The OLED pictures do not go through the app at all.
[`scripts/render-oled.py`](../../scripts/render-oled.py) runs
`firmware/mkyada/oled.py` against the shipped `mkyada.fnt` through the software
displayio in `tests/`, writes the bitmaps to `oled-frames.js`, and
[`oled.html`](oled.html) only enlarges them behind a bezel. They were a
hand-drawn Courier mockup until v0.27.0, which stopped being honest the day the
firmware got its own font. CI re-runs the renderer and fails on a diff.

## Never shipped

This folder is dev-only scaffolding. `tsconfig` only includes `src`, and the
production build's HTML entry is `app/index.html`, so `mock-tauri` never reaches
`dist`. A CI guard (`.github/workflows/ci.yml`) fails the build if it ever does.

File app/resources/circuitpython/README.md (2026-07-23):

# Bundled CircuitPython UF2

Official CircuitPython build for the Waveshare RP2040-Zero, flashed onto
blank boards by the app's provisioning flow (`provision_flash_uf2`).

- Version: 10.2.1
- Source: https://downloads.circuitpython.org/bin/waveshare_rp2040_zero/en_US/adafruit-circuitpython-waveshare_rp2040_zero-en_US-10.2.1.uf2

The app picks up whatever single `*.uf2` file is in this directory — to
upgrade, replace the file (keep the versioned filename) and update this note.

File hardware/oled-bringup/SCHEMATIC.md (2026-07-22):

# MKYADA ekranlı model — bağlantı şeması

SH1106 OLED + EC11 encoder + 6 makro tuş, Waveshare RP2040-Zero üzerinde.
Tüm eşleşmeler [device/demo_h.py](device/demo_h.py) ile birebirdir.

> ⚠️ OLED modülü **SADECE 3.3V**. `3V3` pinini kullan, `5V`'a bağlama.
> Butonların/tuşların diğer bacağı **ortak GND**'ye gider — dahili pull-up var,
> harici direnç/diyot yok.

## Kartı tanı (USB-C üstte, komponent yüzü sana dönük)

```
              ┌───[ USB-C ]───┐
        5V ──│●              ●│── GP0   ← OLED SDA
       GND ──│●              ●│── GP1   ← OLED SCL      ★ ortak toprak
       3V3 ──│●              ●│── GP2   ← Encoder A (TRA)
      GP29 ──│●              ●│── GP3   ← Encoder B (TRB)
   Makro 1  │●   RP2040-    ●│── GP4   ← Encoder PSH
      GP28 ──│●     Zero     ●│── GP5   ← BACK
   Makro 2  │●              ●│── GP6   ← CONFIRM
      GP27 ──│●              ●│── GP7
   Makro 3  │●● ● ● ● ● ● ●●│
              GP14 … GP9   GP8
      (GP16 = onboard RGB LED)
```

## Bağlantı diyagramı

```
  SH1106 OLED (I2C 0x3C @ 400kHz)          RP2040-Zero
  ┌─────────────┐
  │ VCC ────────┼──────────────────────────► 3V3   (⚠ 3.3V)
  │ GND ────────┼──────────────────────────► GND ──┐
  │ SDA ────────┼──────────────────────────► GP0   │
  │ SCL ────────┼──────────────────────────► GP1   │
  └─────────────┘                                   │
                                                    │
  EC11 encoder                                      │  ortak GND
  ┌─────────────┐                                   │
  │ TRA ────────┼──────────────────────────► GP2    │
  │ TRB ────────┼──────────────────────────► GP3    │
  │ PSH ───[sw]─┼───────────────────────────┼───────┤
  │             └───────────────────────────► GP4    │
  │ BACK ──[sw]─┼───────────────────────────┼───────┤
  │             └───────────────────────────► GP5    │
  │ CONF ──[sw]─┼───────────────────────────┼───────┤
  │             └───────────────────────────► GP6    │
  └─────────────┘                                   │
                                                    │
  Makro tuşları (grid gözesi = pin sırası)          │
  ┌─────────────┐                                   │
  │ Tuş 1 ─[sw]─┼───────────────────────────┼───────┤
  │             └───────────────────────────► GP29   │
  │ Tuş 2 ─[sw]─┼───────────────────────────┼───────┤
  │             └───────────────────────────► GP28   │
  │ Tuş 3 ─[sw]─┼───────────────────────────┼───────┤
  │             └───────────────────────────► GP27   │
  │ Tuş 4 ─[sw]─┼───────────────────────────┼───────┤
  │             └───────────────────────────► GP26   │
  │ Tuş 5 ─[sw]─┼───────────────────────────┼───────┤
  │             └───────────────────────────► GP15   │
  │ Tuş 6 ─[sw]─┼───────────────────────────┼───────┤
  │             └───────────────────────────► GP14   │
  └─────────────┘                                   │
                                                    │
  RGB LED: onboard WS2812 (board.NEOPIXEL / GP16) ──┘  kablo gerekmez
```

## Özet tablo

| RP2040-Zero | İşlev | Bağlanan | Kod |
|---|---|---|-----|
| GP0  | I2C SDA | OLED SDA | `sda=board.GP0` |
| GP1  | I2C SCL | OLED SCL | `scl=board.GP1` |
| GP2  | Encoder A | EC11 TRA | `IncrementalEncoder(GP2, GP3)` |
| GP3  | Encoder B | EC11 TRB | `IncrementalEncoder(GP2, GP3)` |
| GP4  | Encoder push | EC11 PSH → GND | `K_PSH = 0` |
| GP5  | BACK | Buton → GND | `K_BACK = 1` |
| GP6  | CONFIRM | Buton → GND | `K_CONFIRM = 2` |
| GP29 | Makro tuş 1 | Buton → GND | `MACRO_PINS[0]` |
| GP28 | Makro tuş 2 | Buton → GND | `MACRO_PINS[1]` |
| GP27 | Makro tuş 3 | Buton → GND | `MACRO_PINS[2]` |
| GP26 | Makro tuş 4 | Buton → GND | `MACRO_PINS[3]` |
| GP15 | Makro tuş 5 | Buton → GND | `MACRO_PINS[4]` |
| GP14 | Makro tuş 6 | Buton → GND | `MACRO_PINS[5]` |
| GP16 | RGB LED | Onboard WS2812 | `board.NEOPIXEL` |

`[sw]` = anahtar teması; basılınca GP pinini GND'ye kısa devre yapar.

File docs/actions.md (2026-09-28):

# Key actions

Every key — and on the Vision 6, every encoder/button slot — can carry one of
these actions. Assign them in the app under **Keys** (or per-app under
**Profiles**). Each key also has **tap / double-press / long-press** variants,
on the key editor's **Press**, **Double press** and **Long press** tabs, and
timing options (see [Key logic](#key-logic) below). **Run on keypad** in the
editor, or **Run** on the **Control** page, presses the key on the keypad from
the app to try it.

Two families:

- **Hardware (HID)** actions are played by the keypad itself as genuine USB
  keyboard/mouse input — they work **standalone**, with no app running, and are
  indistinguishable from your own typing (games and secure apps included).
- **Host** actions are performed by the desktop app while it's connected. The
  key still travels to the device as a carrier, but the effect (open an app,
  hit an HTTP API, switch an OBS scene) happens on your computer.

## Hardware (HID) actions — work standalone

| Action | What it does |
|---|---|
| **Keystroke** | A single key (with typematic repeat while held, like a real keyboard). |
| **Shortcut (combo)** | A chord such as `Ctrl+Shift+S` or `Cmd+Space`. |
| **Text snippet** | Types a block of text — signatures, boilerplate, prompts. |
| **Media key** | Consumer-control usages: Play/Pause, Mute, Volume, Brightness, etc. |
| **Volume level** | Pressing the key mutes/unmutes (standalone). On a Vision 6, the wheel opens an absolute volume slider — the exact percentage needs the app running (see [Wheel menu](#wheel-menu-vision-6)). |
| **Mouse scroll** | Wheel up/down or horizontal pan, optionally with modifiers held (e.g. `Ctrl+wheel` to zoom, `Alt+wheel` in Illustrator). |
| **MIDI message** | A note, control change or program change straight into a DAW — the keypad is a USB MIDI device as well as a keyboard. Notes hold while the key is held (what Ableton's Looper and drum pads need); a Mackie Control picker gives Logic and Pro Tools transport with no mapping. Needs **MIDI** switched on in Settings (off by default, restart required, and unavailable while the USB drive is visible). |
| **Recorded macro** | A recording from the [Recorder](macro-format.md): mouse paths, clicks and keystrokes replayed 1:1 as real HID. |
| **Dial** *(Vision 6)* | Opens a six-slot encoder toolset on the screen: the six keys pick a slot, the wheel drives it. Slots send shortcut pairs, scroll, a relative mouse drag (for controls with no shortcut, like DaVinci's colour wheels) or MIDI CC. Ready-made sets for Resolve, Premiere, Final Cut, Photoshop, Ableton, Logic, Reaper, FL Studio, a MIDI mixer and a sheet-music page turner. See [vision6.md](vision6.md). |
| **Device menu** *(Vision 6)* | Drive the OLED's own menu from a key — scroll ←/→, CONFIRM, BACK, open Home/Grid/Settings. |

## Host actions — need the app connected

| Action | What it does |
|---|---|
| **Launch** | Open an app, a file, or a URL. Up to 5 targets per key — the Vision 6 wheel lists them. |
| **Run command** | Run a shell command line. Up to 5 commands per key (each with a wheel label). |
| **Play sound** | Play an audio file; holding the key can stop, fade or restart it. Up to 5 sounds per key — a soundboard on one key. |
| **Microphone** | Toggle / mute / unmute the system mic, or **push-to-talk** (unmute while held). |
| **Microphone level** | Pressing the key opens a mic input-gain slider on the Vision 6 (needs the app; no standalone mic-gain control). |
| **Webhook** | Any HTTP request, curl-style — smart lights, Home Assistant, Discord/Telegram, your own API. Alternative requests ride on the same key via the wheel. |
| **OBS Studio** | Control OBS over obs-websocket: switch scene, start/stop record & stream, toggle mic / virtual cam / replay buffer, trigger a hotkey. |
| **OBS Center** | Vision 6 only: pressing the key opens a **live OBS dashboard** on the keypad screen — REC/LIVE chip, record/stream timer, active scene, mic level meter (with mute state) and a CPU / dropped-frames / FPS health row, every widget toggleable per key. The wheel drives the **framed control row**: on MIC it's a fader (press = mute toggle), on SCENE it browses (press = switch); **holding CONFIRM jumps between the rows**. No mic configured = OBS's default mic. The **six keys become OBS quick actions** with their labels along the bottom of the screen; BACK closes it. On a Core 6 (no screen) the key does nothing. |
| **Sequence** | Stream Deck-style multi-action: run several of the above in order, with delays between steps. |

## Layer & off actions — both models

| Action | What it does |
|---|---|
| **Go to layer X** | Jump straight to a specific layer (A–H). Works on the Core 6 too. |
| **Next / previous layer** | Step through layers. |
| **Do nothing** | Turn the input off — even overrides a Vision 6 control's built-in menu action. |

## Wheel menu (Vision 6)

On the Vision 6, turning the wheel selects a key and **pressing it opens a menu
that fits the key's action** — not always the speed editor. The menu uses one
consistent gesture grammar:

- **Turn** — browse the options (or, on a slider, adjust the value live).
- **Short press** — use the highlighted option now (fire the key / switch the
  scene / do the mic action) — once.
- **Long press (hold)** — reassign the key to the highlighted option. For local
  kinds (media…) the device rewrites the key itself, so it works standalone.
  Menus that support this show a **`hold: assign`** hint on the bottom bar, so
  the gesture is discoverable rather than hidden.
- **Back** — leave the menu.

Pressing a key *physically* still just runs its action — except **slider kinds**
(volume, mic level), where a press opens the slider directly (a bare "mute" is a
poor default for a volume key).

| Action | Turn | Short press | Long press |
|---|---|---|---|
| Recorded macro / Text / Sequence | Adjust playback/typing speed (step delays scale too) | Save the speed | — |
| Keystroke / Shortcut | Fire the key repeatedly | Fire once | — |
| Media key | Browse every media key | Use the highlighted one | Reassign the key to it |
| **Volume level** | Set the % (slider) | Confirm & close | — *(press the key = open this)* |
| **Microphone level** | Set the input gain (slider) | Confirm & close | — *(press the key = open this)* |
| Mouse scroll | Scroll in the assigned direction | One step | — |
| OBS · switch scene | Browse scenes (live one marked) | **Switch OBS live** | **Reassign** the key to that scene |
| OBS · record/stream/cam/replay | — | Toggle it live (status shown) | — |
| **OBS Center** | Adjust the framed row: mic volume or scene browse | Framed row's action: mute toggle / switch to the browsed scene | **Move the frame** to the next control row (mic ↔ scene) |
| Microphone (mute) | Browse toggle / mute / unmute | Do it now | Reassign the key to that mode |
| Webhook / Command / Launch / Sound · one entry | — | Run it (result shown; a line points at the app for adding more) | — |
| Webhook / Command / Launch / Sound · several entries | Browse the key's entries (default marked) | Use the highlighted one now | Make it the key's **default** |
| **MIDI** | Browse all 128 notes (or controller / program numbers), assigned one marked | **Hear** the highlighted note — a real on/off pair, nothing hangs | **Reassign** the key to it, keeping its channel, velocity and note mode |
| Device menu (layer / nav) | Browse next/prev layer, jump to a layer, Home/Grid/Settings | Run the highlighted one | Reassign the key to it |

A standalone volume key (app closed) still adjusts relatively over HID, but the
card says the exact **%** needs the app — the keypad cannot read the system
volume on its own.

Host actions (OBS, mic, webhook…) show an **"app required"** reminder when the
MKYADA app isn't connected. The app also shows a live mini-OLED preview of this
menu on the key editor's **Wheel menu** tab and a full reference under **Settings → Keypad → Wheel menu**, and
pushes the live system volume so a volume key shows its **%** right on the grid.

## Key logic

Each key resolves three gestures, all on the firmware (works standalone):

- **Tap** — the main action.
- **Double-press** — an alternative action within ~250 ms.
- **Long-press (hold)** — an alternative action after ~400 ms.

Plus per-action options: **repeat** (loop while held or a fixed number of
times), **on re-press** (a second press stops or restarts a running macro), and
**hold-to-repeat** for single keys. See [macro-format.md](macro-format.md) for
the exact JSON these compile to.

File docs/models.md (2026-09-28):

# Two models: Core 6 and Vision 6

MKYADA ships in two hardware variants that run the **same firmware** and the
**same desktop app**. `config.json "model"` selects the variant; a blank board
auto-detects at first boot (a Vision 6 finds its OLED, everything else is a
Core 6).

| | Core 6 **Core 6** | Vision 6 **Vision 6** |
|---|---|---|
| Display | On-board RGB LED (status) | **SH1106 128×64 OLED** + RGB LED |
| Input | 6 macro keys | 6 macro keys + **EC11 rotary encoder** (push) + **BACK/CONFIRM** buttons |
| Layer switching | A dedicated **layer key** cycles layers | Turn the wheel on the **Home** screen — no key spent |
| On-device feedback | LED colour / blink | Live macro names, layer & profile bands, speed editor, settings menu |
| Board | Waveshare RP2040-Zero | Waveshare RP2040-Zero |
| Standalone | Yes — macros play over USB HID with no app | Yes — plus you can *see* and tune everything on the screen |

Everything else is identical: recorded macros, per-app profiles, the full set of
[key actions](actions.md), finished-product mode, one-click firmware updates.

## What differs in the app

The desktop app adapts to whichever model is connected:

- **Keys** — the Vision 6 adds a **Module controls** grid (encoder →/←, BACK,
  CONFIRM, wheel-push) that you assign just like keys, plus a per-layer
  on-screen name and a **Wheel menu** tab in the key editor. The Core 6 shows
  the six keys and its layer key.
- **Profiles** — the same Module controls grid appears under a profile on the
  Vision 6; the Core 6 has no wheel or nav buttons, so it never shows it.
- **Devices** — on the Vision 6, *Test keys* also checks the wheel and nav
  buttons and *Fix wiring* covers them; on the Core 6 the *Setup* tab picks a
  layer key.
- **Control** — both models get the same page for running keys from the app;
  the Vision 6 lists its layers by name.
- **Settings → Keypad** — the Vision 6 exposes screen options (layer band,
  profile band, auto-return timeout, wheel acceleration); the Core 6
  shows only the drive-hide (finished-product) toggle.

| Core 6 · Keys | Vision 6 · Keys |
|---|---|
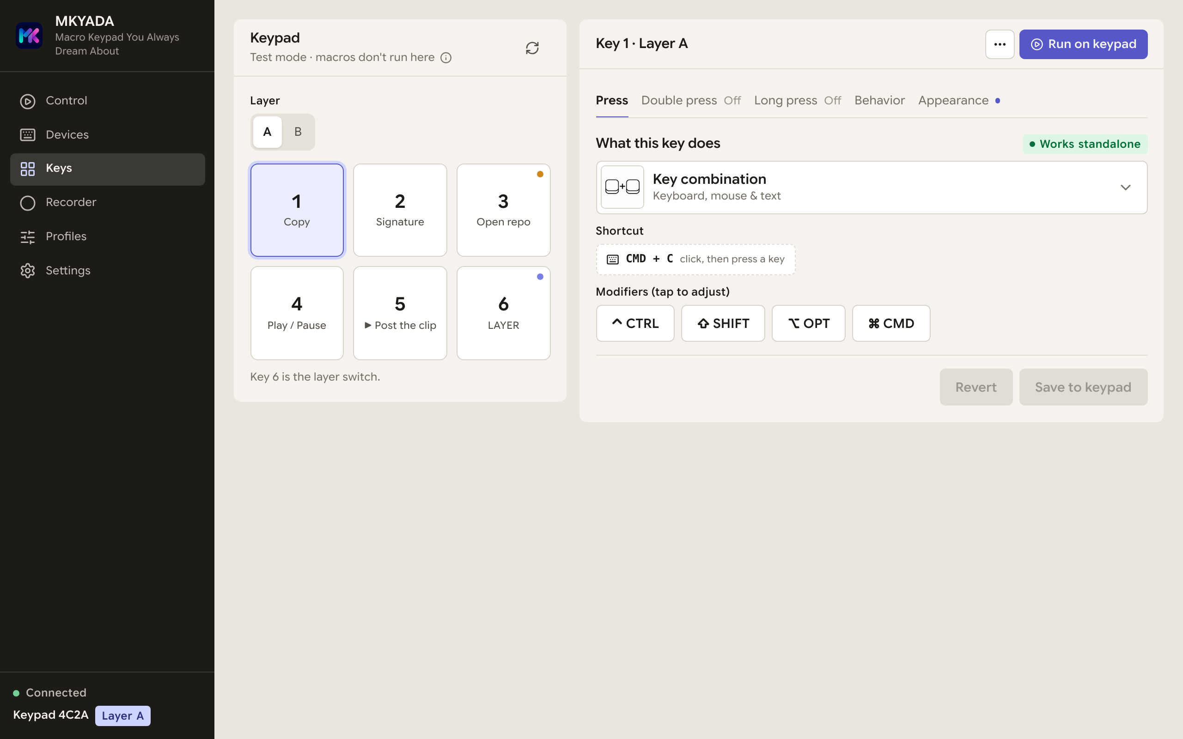
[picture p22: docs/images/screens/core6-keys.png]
Core 6 Keys
|  | Vision 6 Keys |

The assignable **"Go to layer X"** action and layer next/prev work on **both**
models — a Core 6 key can jump straight to a layer too.

See [vision6.md](vision6.md) for the Vision 6 wiring, on-device screens and
recovery details.

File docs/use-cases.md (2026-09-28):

# Use cases

Real setups that show what MKYADA does — mix and match the [key
actions](actions.md), [layers](models.md), and [per-app profiles](../README.md).
Both models can do all of these; the notes call out where the **Vision 6**
screen and encoder make it nicer.

## 1. Streaming

Go live without alt-tabbing. Keys switch OBS scenes, toggle recording, and fire
a "we're live" webhook to your Discord; a **push-to-talk** key unmutes only
while held. On the Vision 6, the **encoder** rides volume and the OLED shows the
current scene / REC / LIVE at a glance.

Vision 6 · streaming layer

> Actions: OBS Studio · Microphone (push-to-talk) · Webhook · Media
> · Vision 6 encoder for volume.

## 2. Photo & video editing

Bind the shortcuts your hands never remember — undo/redo, save, export, brush
sizes — and record a repetitive retouch as a macro that plays back 1:1. The
Vision 6 **wheel** scrubs the timeline or zooms (mouse-scroll with a modifier),
with **wheel acceleration** so a fast flick jumps further.

> Actions: Shortcut · Recorded macro · Mouse scroll (+modifier) · Sequence.

## 3. Development

One key runs your build, another runs the tests, a third opens the PR. Text
snippets drop in boilerplate; **launch** opens the repo or localhost. With
**per-app profiles**, the same six keys mean different things in VS Code, the
terminal, and the browser — automatically, following the foreground app.

Per-app profiles

> Actions: Run command · Launch · Text snippet · Per-app profiles.

## 4. Gaming

Software macro tools inject fake events that anti-cheat and secure apps ignore.
MKYADA **is** a keyboard and mouse — every keystroke, click and mouse path is
genuine USB hardware input. Put a combo or a recorded rotation on a key and it
plays exactly like your own hands. Use [layers](models.md) to fit a whole
loadout onto six keys.

Running a looped macro on a box you reach over Chrome Remote Desktop? The app's
**Control** page starts any key remotely, and the playback bar, the global stop
hotkey (**Ctrl+Alt+Shift+S** by default) or the tray's **Stop playback** ends
the loop without touching the keypad. See
[Remote control](../README.md#remote-control).

Control page while a key loops

> Actions: Shortcut · Recorded macro · Layers · Go-to-layer.

## 5. Meetings & working from home

A mute/unmute key you can find without looking, a "join" launch for your meeting
link, a webhook that flips a **do-not-disturb** light on the wall, and a key
that opens the camera app. The Vision 6 shows which layer/profile is live so you
never guess.

> Actions: Microphone · Launch · Webhook · Layers.

## 6. Everyday productivity layers

Six keys become dozens. Layer A is your desktop essentials, layer B is
smart-home and shell, layer C is app launchers. On the **Core 6** a dedicated
layer key cycles them; the assignable **"Go to layer X"** action jumps straight
to one. On the **Vision 6** you turn the wheel and read the layer name on screen.

Core 6 · Keys

> Actions: Layers · Go-to-layer · Launch · Shortcut · Play sound.

## 7. Music production

The keypad is a **USB MIDI device as well as a keyboard**, so one box does both
jobs — the cheap MIDI controllers can't send shortcuts, and the stream decks
can't send MIDI. Put transport on keys and mixer knobs on the wheel: notes for
clip and scene launch in Ableton, a **program change** to jump between amp-sim
presets, control changes on the **Dial** for cutoff, send level or pan.

Two details that make it feel like real gear. Notes are **momentary** by
default — the note lasts exactly as long as your finger, which is what
Ableton's Looper and drum-rack pads want. And the Dial's CC slots send
**relative** values by default, so a knob never jumps when the DAW's value and
the encoder's disagree.

Ableton, Reaper and FL Studio MIDI-learn anything: wiggle the control, click the
parameter. Logic and Pro Tools have no such thing, so the MIDI editor has a
**Mackie Control** picker — choose "Mackie Control" as a control surface in the
DAW and transport works with no mapping at all.

Switch **MIDI** on in Settings first; it's off by default, needs a restart, and
is unavailable while the USB drive is visible.

> Actions: MIDI message · Dial (MIDI CC slots) · Shortcut · Layers.

## 8. Reading music on stage

A page turner that costs nothing extra. **forScore** and **MobileSheets** both
ship with the arrow keys bound to next/previous page, so the *Sheet music page
turner* Dial preset works the moment you plug in — USB-C straight into an iPad,
no pairing, no batteries, and no app on the tablet. The wheel turns pages, the
wheel press is next page, and a second slot scrolls within an oversized score.

Nothing about this needs MIDI or the desktop app: it is plain USB keyboard
input, so it works on any tablet or laptop that accepts a keyboard.

> Actions: Dial (page-turner preset) · Shortcut.

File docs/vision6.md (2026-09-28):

# MKYADA Vision 6 (OLED + encoder model)

The Vision 6 is the screen model: an SH1106 128×64 OLED, an EC11 rotary
encoder with push, BACK/CONFIRM buttons, six macro keys and the on-board
RGB LED, all on a Waveshare RP2040-Zero. It runs the same firmware as the
Core 6 — `config.json "model": "vision6"` selects the variant (a blank,
config-less board auto-detects the display once at boot).

## Wiring

Bring-up-verified pinout (mirrors `hardware/oled-bringup/SCHEMATIC.md`):

| Function | Pin | Notes |
|---|---|---|
| OLED SDA | GP0 | I2C 0x3C @ 400 kHz — **3V3 only**, never 5 V |
| OLED SCL | GP1 | |
| Encoder A (TRA) | GP2 | EC11, common to GND |
| Encoder B (TRB) | GP3 | |
| Encoder push (PSH) | GP4 | active low, internal pull-up |
| BACK button | GP5 | active low |
| CONFIRM button | GP6 | active low |
| Macro key 1 | GP29 | also the **recovery key** (hold while plugging in to un-hide the USB drive) |
| Macro key 2 | GP28 | |
| Macro key 3 | GP27 | |
| Macro key 4 | GP26 | |
| Macro key 5 | GP15 | |
| Macro key 6 | GP14 | |
| RGB LED | GP16 | on-board WS2812 |

A key soldered to a different GPIO is fine — assign it in the app under
**Devices → Fix wiring → Choose pins** (writes `config.json "pins"`).

Runtime: CircuitPython **10.2.x** (the tier the display stack is validated
on). The firmware zip / app installer ships every needed library (`lib/`)
and the screen font (`fonts/mkyada.fnt`, 716 bytes).

Since firmware **0.20.0** the display draws into one resident framebuffer
using MKYADA's own bitmap font, instead of building `displayio` Labels over
BDF fonts per screen. Measured on the board, ten full repaints now allocate
48 bytes in total; the font and text libraries the bundle used to carry went
from 248 KB to 716 bytes, and Turkish letters are drawn rather than folded to
ASCII. Free heap on a running board went from a median 14 KB to 56 KB. See the FONT tab of [the demo page](simulator.html).

**0.21.0** made the repaints incremental: a menu detent or a turn of the speed
editor redraws only the rows that changed, so displayio's push shrinks with
them — 104 ms to 51 ms end to end for a detent, measured on the board. The
`font` field left `config.json` and `hello` in the same release (protocol v10),
and updating from 0.19.0 or earlier now deletes the BDF fonts and the two
Adafruit text libraries from the board, reclaiming about 248 KB of its 1 MB
flash.

## Screens & controls

**Try the menu in a browser: [simulator.html](simulator.html).** It is not a
mockup, and not a port either: the page runs the desktop app's own drawing
modules, bundled in by `scripts/build-demo.mjs`, so the browser, the app's
editor preview and the keypad cannot show three different menus. The whole menu
(wheel menus, host menus, key test, bands, update/error screens) runs and can be
changed without flashing a board. Two more tabs: **İKONLAR**, the 270-icon
family a macro can pick from, clickable straight onto a grid key so you see it
at 1:1; and **FONT**, which draws any text you type at device scale and shows
every glyph's pixel cost.

Real renders of the 128×64 OLED (layer A, nicknamed "Stream" — the nickname
shows in the grid's band; the layer picker always shows the plain letter) —
produced by
`scripts/render-oled.py`, which drives `firmware/mkyada/oled.py` and the shipped
`mkyada.fnt` through the software displayio in `tests/`, so these are the
device's pixels rather than a drawing of them.

| Home | Grid | Speed | Settings | About |
|---|---|---|---|---|
| Home | Grid | Speed | Settings | About |

| Scene picker | Record status | Volume | Turkish | Data transfer |
|---|---|---|---|---|
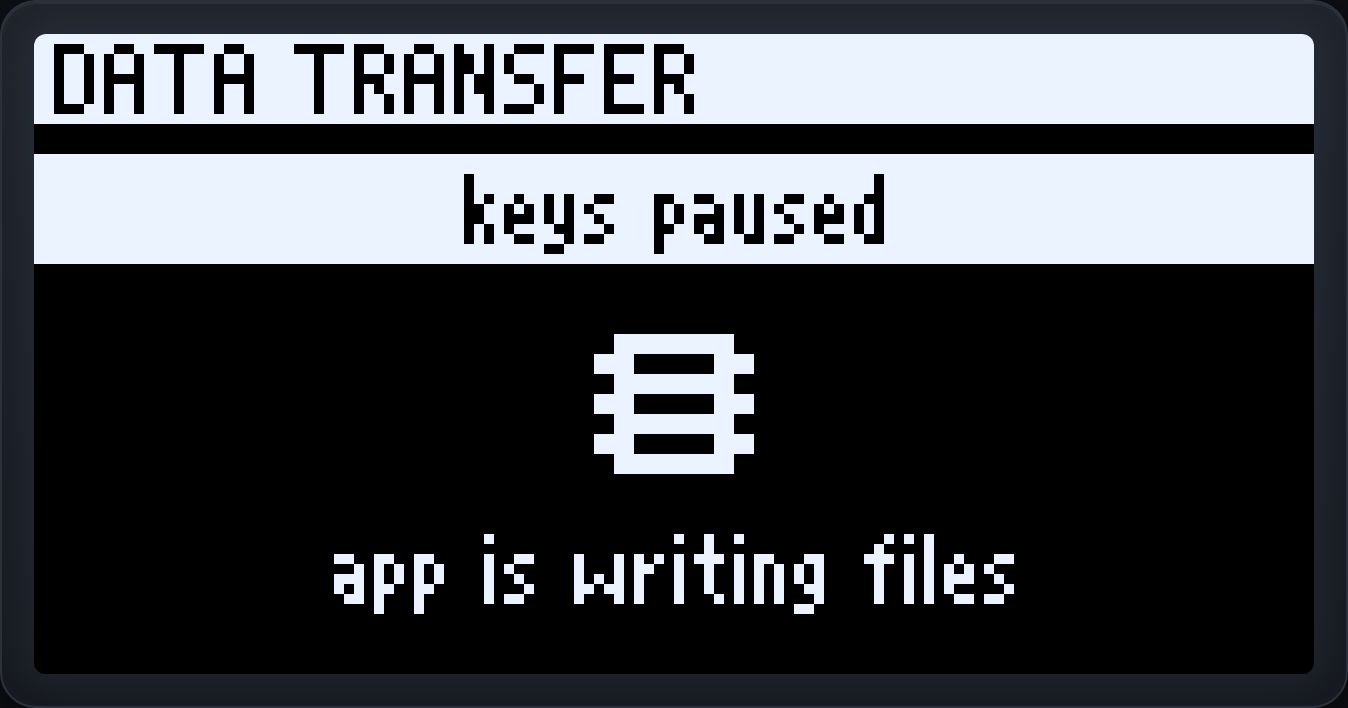
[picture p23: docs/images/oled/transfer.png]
Data transfer
| Scene picker | Record status | Volume | Turkish menu |  |

- **Boot** — branded "MKYADA loading" screen from the first frame; no
  CircuitPython console text.
- **Home** — turn the wheel to scroll layer letters (A…H, as many as
  `layer_count`; a single-layer setup shows just A) plus **SETTINGS**;
  press the wheel or CONFIRM to enter.
- **Grid** (the resting screen) — the active layer's six macro names, read
  from the macro files the app uploads. Turn to select a cell, CONFIRM/push
  to open that key's **speed editor**, BACK for home. Pressing a macro key
  plays it over USB HID and inverts its cell until playback ends.
  With **Layer band** / **Profile band** on (SETTINGS, or the app's
  Settings → Keypad), an inverted strip across the top names the active
  layer and/or the desktop app's active per-app profile — the macro names
  squeeze a little to make room. The profile half needs the app running;
  its label disappears the moment the app disconnects.
- **Speed editor** — 0.1×–10.0× with encoder acceleration; CONFIRM writes
  the value into the macro file itself (`settings.speed`), so the app and
  the device always agree. 2× plays in half the time, 10× in a tenth.
  If the USB drive is visible (recovery boot) the filesystem is host-owned
  and the editor explains instead of saving.
- **SETTINGS** — auto-return timeout (3–60 s), language, the Layer/Profile
  band toggles, wheel paging, key test, pixel test, restart.
  **Key test** shows all six keys at once with a press counter each, plus the
  wheel and the module buttons, so a silent key stands out instead of having to
  be found one press at a time; hold PSH to leave. **Pixel test** lights the
  whole panel so a dead column or a stuck row shows against a solid field —
  nothing on it is readable, so PSH, BACK and CONFIRM all leave.
  Timeout is stored on the board (NVM); language,
  the band toggles and wheel paging live in `config.json` (rewritten
  on-device, like the app does) so the app always shows the same values —
  all three switches are also in the app's Settings → Keypad. All survive power cycles
  and firmware updates.
  The font-size entry is gone as of 0.20.0: one font ships now, and its
  proportional spacing fits more into a grid cell than the old fixed 4×6
  did. The `font` field left `config.json` and `hello` in 0.21.0 (protocol
  v10); a `font` key in an old config file is ignored.
- **Data transfer** (fw 0.25.0) — while the app is reading or writing files
  (a save, a backup, reading the keys back), the keypad shows a locked screen
  and stops responding to its own keys, wheel and buttons. It is not a
  politeness: every repaint costs 100–300 ms in which the USB receive FIFO
  goes undrained, and the chunk that arrives then loses bytes out of its
  middle — a failed save. So the screen is painted exactly twice, once going
  in and once coming out, no matter how many files the operation touches.
  Presses during it are dropped rather than queued. It ends three seconds
  after the last file operation, which is also what recovers the keypad if
  the app dies mid-save.
- **Host mode** (a per-app profile is active) — key, encoder and button
  events stream to the app. Since fw 0.10.0 the screen shows the active
  profile's six key names as a grid (the app pushes them over serial), with
  the band on top if enabled — so you can see what the keys do, not just
  that an app owns them. Falls back to a plain "Connected to app" note on
  older apps.

## Browsing and reassigning on the device

Select a key in the grid and press the wheel (PSH or CONFIRM). What opens
depends on the key's action, and the grammar is the same everywhere:

> **turn** = walk the options · **tap** = do the highlighted one once ·
> **hold** = reassign this key to it · **BACK** = leave

Two kinds open a full browser. **Media keys** list the nine consumer usages.
**MIDI keys** list all 128 notes by the names DAWs print (60 = C3) — or
controller numbers for a CC key, program numbers for a program-change key.
A tap **auditions** the highlighted note, sending a real note-on/note-off pair
so nothing hangs, and a hold rewrites the key. The parts you are not editing —
channel, velocity, and whether the note is momentary — are read from the file
and put back unchanged.

The keypad writes the macro itself, so a reassign sticks with no app running.
It needs a writable filesystem, which means the USB drive has to be hidden
(the default); with the drive visible the browser says so instead of failing
silently.

A press on the physical key still just plays it. The browser is the wheel
gesture, not the key.

> The note list is 128 entries long, so it is labelled lazily — only the rows
> actually on screen are turned into strings. Building all 128 on every detent
> would allocate a kilobyte of garbage per turn on a heap where fragmentation,
> not free space, is the binding constraint.

## The Dial — a six-slot encoder toolset

A key whose action is **Dial** opens a module that takes over the screen: the
six keys become slot selectors and the wheel drives whichever slot is
selected, with the six labels drawn as tiles so you can see the whole set at
once. Everything it does is plain HID or MIDI performed by the keypad, so it
works with the app closed.

Each slot is one of:

| Slot | A detent sends |
|---|---|
| **Shortcut pair** | a full modifier combo one way, another the other (jog with arrows, zoom with ⌘+/⌘−) |
| **Scroll** | wheel ticks, vertical or horizontal, with optional modifiers held around them (⌥+wheel to zoom) |
| **Mouse drag** | a relative cursor nudge with the left button held — for controls that have no shortcut at all, like DaVinci's color wheels. Modifiers can ride the whole gesture, which is how Photoshop's brush-size scrub works |
| **Volume / media** | a consumer usage |
| **MIDI CC** | a control change — relative by default, so the knob never jumps when the DAW's value and the encoder's disagree |

Pressing the wheel runs the selected slot's own button action (space on a jog
slot, a click on a drag slot). Sensitivity is 1–10 per slot on top of the
wheel's own velocity acceleration, and direction can be inverted. BACK closes;
unlike the chooser menus the Dial has no idle timeout, because a colour
session parks on it for minutes at a time.

Ready-made sets fill the six slots for DaVinci Resolve, Premiere, Final Cut,
Photoshop, a generic timeline, Ableton, Logic, Reaper, FL Studio, a MIDI mixer
and a sheet-music page turner. They are starting points — every slot stays
editable in the app.

## Working on the menu

### One drawing, two places it has to look right

The Vision 6's screens exist twice on purpose and nowhere else:

| Where | What it is |
|---|---|
| `firmware/mkyada/oled.py` | the Python that runs on the board |
| `app/src/lib/oled-screens.ts` | the JavaScript the desktop app and the demo page both use |

That second one used to be three separate implementations — one in the app, one
inside `simulator.html`, one inside the font viewer. They drifted, which is the
failure that matters: a demo page that quietly stops matching the keypad is
worse than no demo page, because people trust it. They are now one module, and
the demo page carries a generated bundle of it rather than a copy.

The two survivors are held to each other rather than trusted:

- `tests/oled_render_test.py` renders every screen from the **firmware** into a
  real 128×64 buffer, checks the structural invariants, and writes
  `tests/golden/*.txt`.
- `app/src/lib/oled-draw.test.ts` renders the same inputs through the
  **JavaScript** and demands the same pixels — all 28 screens, both languages.

So a layout change that reaches one side and not the other fails CI. Regenerate
the goldens deliberately with `python3 tests/oled_render_test.py --bless`.

Everything else the screens need is generated from a single source too, each
with a `--check` mode CI runs:

| Source | Generator | Goes to |
|---|---|---|
| `fonts/src/mkyada.txt` | `build-font.mjs` | `firmware/fonts/mkyada.fnt`, `app/src/lib/oled-font.ts` |
| `icons/src/icons.txt` | `build-icons.mjs` | `firmware/mkyada/icons.py`, `app/src/lib/oled-icons.ts` |
| `firmware/mkyada/i18n.py` | `build-oled-i18n.mjs` | `app/src/lib/oled-i18n.ts` |
| `app/src/lib/oled-bundle.ts` | `build-demo.mjs` | the bundle inside `docs/simulator.html` |

The icon source is 270 icons in 21 categories, drawn as ASCII, one 8×8 block
each, packed one byte per row (bit 7 = leftmost pixel) — 2160 bytes, and that
packing *is* the flash layout, so the firmware reads the same bytes without
conversion. A macro picks one by **name** (`"icon": "rocket"` in its JSON),
never by index: names are permanent, so reordering or extending the set can
never repoint a user's macro at a different picture. An unknown name falls back
to the action family's default. One name is reserved: `"icon": "none"` means
**draw nothing**, which is a different thing from having no `icon` field at all
(that one means "the action family chooses") — without it there was no way to
ask for a bare, full-width name on a key whose kind has a default picture.

Since firmware 0.25.0 the field can also be the picture instead of a name:
`"icon": "px:183c7effc3c30000"` is those same eight rows written out in hex,
drawn by hand on the app's 8×8 grid (Keys → the key → **Appearance** → **Draw your own**).
`icons.get()` decodes it rather than looking it up, so a drawing needs no
second file and no index — it rides inside the macro it belongs to, travels
with a backup, and goes away with a delete. A malformed one reads as "no icon"
rather than blanking the tile. Icons live under `icons/`, not `fonts/` — they
are their own asset, not glyphs, and `build-font.mjs` compiles every `.txt` it
finds beside the font source.

### Working on the menu, in practice

`docs/simulator.html` is still where a menu change gets tried first — open the
file, no server, no build, and the whole UI runs: six macro keys, the wheel with
push, BACK and CONFIRM, plus a panel that simulates the desktop app (connect,
host mode, OBS record/stream, the read-only USB drive, a firmware update) so the
host-fed wheel menus and the band markers are reachable too.

What is hand-maintained in that file is now only the **state machine** — which
control leads to which screen, the port of `firmware/mkyada/ui.py` — and the
fake desktop app. The drawing underneath it is generated. After changing a
screen: edit `app/src/lib/oled-screens.ts` and `firmware/mkyada/oled.py`
together, run `node scripts/build-demo.mjs`, then
`python3 tests/oled_render_test.py --bless` and the app's `npx vitest run`.

## Custom wheel / button assignments

By default the wheel navigates the menu. In the app (Keys → Module
controls) any layer can instead assign macros to five virtual slots:

| Slot | File | Fires when |
|---|---|---|
| Encoder → | `macros/enc-cw[-<layer>].json` | one play per clockwise detent |
| Encoder ← | `macros/enc-ccw[-<layer>].json` | one play per counter-clockwise detent |
| BACK | `macros/btn-back[-<layer>].json` | BACK pressed on the resting grid |
| CONFIRM | `macros/btn-confirm[-<layer>].json` | CONFIRM pressed on the resting grid |
| Encoder press | `macros/btn-psh[-<layer>].json` | the wheel pushed on the resting grid (fw ≥ 0.9.0) |

Typical uses: volume up/down on the wheel, mouse scroll, zoom (Ctrl +/−),
OBS hotkeys, a soundboard clip on CONFIRM. Anything the app can assign to a
key can go on a slot; HID-compilable kinds (keystrokes, media, mouse) work
standalone, host-performed kinds (sound, launch, command, webhook) run while
the app is connected. A layer without its own slot file inherits the layer-A
one; deleting the files restores the default menu navigation.

### Per-context overrides (fw ≥ 0.9.0, issue #19)

The files above apply on the **resting grid**. Each menu context can be
overridden separately with a global (unlayered) file:

| Context | File | Where it applies |
|---|---|---|
| Layer screen | `macros/<slot>@home.json` | the layer picker |
| Settings menu | `macros/<slot>@menu.json` | settings and its sub-menus |

So "wheel scrolls the page even while the layer picker is open" is
`enc-cw@home.json` + `enc-ccw@home.json`; navigation then happens via
select mode or keys mapped to menu actions. An absent file keeps that
context's built-in behavior.

### Key logic on slots (fw ≥ 0.9.0)

The button slots (BACK / CONFIRM / encoder press) may carry the same
`variants` as keys: tap, **double press** and **long press** each doing
something different. Two extras specific to slots:

- The tap can stay **built-in** (`kind:"menu"`, `menu:"default"`) while
  only the gestures are customized — e.g. *wheel long-press = Back* with
  the push otherwise behaving stock.
- A `menu`-kind action assigned to a slot drives the **built-in**
  navigation, never other custom slots — so "hold = Back" always
  navigates, whatever else is remapped. (A menu action on a normal
  *key* emulates the control fully, custom assignments included — the
  broken-wheel scenario.)

### Escape hatch

On a customized grid the wheel push toggles a temporary **select mode**
with the default navigation everywhere (it survives into the layer picker
and settings until you land back on the grid or the idle timeout fires).
If the push itself is assigned, **holding it ~1.2 s** toggles select mode
instead — unless you deliberately gave the push its own hold action, in
which case the menus stay reachable via keys mapped to menu actions or
the app.

## Recovery

The CIRCUITPY drive is hidden by default (finished-product mode) — a fresh
firmware install, or any config without an explicit `"usb_drive": true`,
comes up with the drive hidden and the app managing all files over serial.
To force the drive back for one session (app unavailable, broken config…):
unplug, hold **macro key 1 (GP29)**, plug in.

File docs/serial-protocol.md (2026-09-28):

# MKYADA serial protocol (v17)

v17 is the **remote control** release: people who reach the keypad's computer
over a remote desktop (Chrome Remote Desktop) can't touch the keys, so a
looping macro would lock them out. All changes are additive.

- **`{"t":"press","key":N,"layer"?:…,"gesture"?:…}`** runs a numbered key the
  way a physical press does. `layer` is an index or a letter (default: the
  current layer; a profile redirects paths as usual), `gesture` is
  `tap` (default) | `double` | `hold` and picks the key-logic variant
  directly. Queued and executed from the main loop, never inside the message
  handler. Replies:
  - `{"t":"ok","re":"press","action":"play"}` then the usual
    `play_start`/`play_done` (plus `key_action` when the key has variants);
  - `action:"layer"` for the layer key (cycles to the next layer);
  - `action:"stop"` when it re-pressed the playing key (see below);
  - `err` codes: `bad_key`, `bad_layer`, `bad_gesture`, `not_assigned` (no
    macro file), `unsupported` (Vision 6 keys whose press opens an on-device
    menu — volume / mic level / OBS Center / Dial — nobody is at the keypad
    to use it), `busy` (file transfer, wiring wizard, or another macro is
    playing and `busy_other` is `ignore`), `updating`.
  - Test mode (Keys page, Devices → Test keys), host mode and a device-owned screen (OBS
    Center / Dial open) do **not** block a remote press — they suppress the
    keypad's own keys, but a remote press is an explicit request from the app.
  - **While-held semantics:** there is no physical key to hold, so a remote
    press is a tap: hold-to-repeat keys and held single keys / momentary MIDI
    notes play **once**. Loops (`repeat: 0`) run until `stop` or a re-press.
  - No `btn` edge is streamed for a remote press, so computer-side kinds
    (launch/command/sound/webhook) only run through `key_action` (variants).
- **A press during playback** is not dropped. Same macro file as the running
  one → a physical re-press (`on_repress`: stop, or restart = the press is
  queued again); another key → `busy_other` (`ignore` → `err busy`,
  `switch` → the playback stops and the press is queued). A physical press of
  the key a remote press started also counts as its re-press.
- **`stop` answers** `{"t":"ok","re":"stop","was_playing":true|false}`. It
  also cancels a playback whose tap/double/hold gesture was still resolving
  (the stop used to sit in the inbox until the macro had played). Idle, it
  drops a queued `press`/restart.
- **`play_start`** gains `key` (logical key or null), `layer` (letter),
  `loop` (bool) and `src`: `key` (physical press), `remote` (`press`),
  `host` (`play` command) or `slot` (Vision 6 wheel / nav / menu).
- **`play_done`** gains `reason`: `done` | `repress` (same key again) |
  `stop` (serial stop) | `other` (another key took over, or any key ended a
  keyless play) | `error`.
- **`hello.playing`** is `{"file","key","layer","loop"}` while a macro plays
  (`identify` is answered mid-playback), else `null`.

v16 (firmware 0.29.0) is the **USB MIDI** release. No new message types; one
config key, one `hello` field, one macro event type and one Dial slot type:

- **`midi` config key** — when true the board presents a USB MIDI port named
  after the product ("MKYADA Vision 6" / "MKYADA Keypad"). It is **boot-time,
  like `usb_drive`**: `set_cfg` refuses it, so the app writes config.json and
  sends `{"t":"reset"}` (a `reload` does not re-run boot.py). Default false —
  an idle port clutters every DAW's device list and costs a USB endpoint.
- **It yields to a visible CIRCUITPY drive.** The RP2040 has 7 endpoint pairs
  and the firmware already spends 5 (HID 1 + CDC console 2 + CDC data 2), 6
  with the drive. Rather than sit on the ceiling, boot.py skips MIDI whenever
  the drive is visible, and the whole enable is wrapped: if it fails anyway
  the board still comes up with its keyboard and its serial link, which is
  what the app needs to talk it back out of a bad config.
- **`hello.midi`** mirrors the switch, so the app can gate both the Settings
  toggle and the `midi` action kind on a board that actually has the port.
- **New macro event `{"type":"midi", "m":…, "ch":…, "d1":…, "d2":…}`** and the
  Dial slot type `"midi_cc"` — both in
  [macro-format.md](macro-format.md). All additive: old apps never send
  either, old firmware skips unknown event types and treats an unknown slot
  type as a dead slot.

v15 (firmware 0.28.0) is the **Dial** release (kind `enc_module`) — a
device-native encoder toolset. No new message types; two existing ones gain a
meaning, and the HID mouse grows a report:

- **`ctx` can announce a device-local view.** Opening a Dial sends the usual
  `{"t":"ctx","key":…,"layer":…,"kind":"enc_module","file":…}` — but as an
  **announcement, not a menu request**. The app must NOT answer with a `menu`
  (new firmware ignores the reply while the module is open; the announce
  exists so the app can suppress its own handling of the `btn` edges streamed
  while the six keys are the module's slot selectors — same double-execution
  rule as the OBS Center). Everything the module does is plain HID performed
  by the device itself; it works identically with no app attached.
- **A device-local view now emits `menu_ev ev:"close"`** when it closes
  (BACK, or a transfer taking the screen), so the app can drop its edge
  suppression.
- **HID: relative pointer report (id 5)** on the mouse interface — buttons +
  dX/dY (int8), used by the Dial's mouse-drag slots to nudge the cursor from
  wherever the user has it (the id-2 pointer is absolute and would teleport).
  Report id 2 (absolute pointer) and id 4 (wheel/pan) are unchanged.

The Dial's on-device payload (`enc_module.slots`) is documented in
[macro-format.md](macro-format.md).

v14 (firmware 0.27.0) is the **meta sidecar** release. One new on-device
file, `/macros/meta.json`, managed by `mkyada/meta.py` — no new commands,
everything rides the existing `fs_*` ops:

```json
{"format": "mkyada-meta", "version": 1,
 "entries": {"key3": {"s": 25, "c": 3735928559, "z": 812340}}}
```

- **Per-stem override fields** — `s` (speed, integer tenths: 25 = 2.5×),
  `i` (icon name or `px:` picture), `n` (name). They shadow the macro
  header's `settings.speed` / `icon` / `name`. A device-side speed edit now
  writes this small file and never rewrites the macro body — the old
  whole-file rewrite could out-run the 8 s hardware watchdog on a long
  recording and corrupt the FAT mid-write (the field incident that
  reformatted a board). The app applies the same overlay when it reads
  macros, and uses the sidecar itself for header-only edits on big files
  (a recorded macro's speed/icon/name), so a 300 KB body never re-uploads
  for a one-field change. Per-profile speed keys on the profile's stem
  (`p_<id>_key3`) — the copy-on-write of the whole macro file is gone.
- **CRC manifest** — `c` (CRC32/IEEE of the macro file's bytes) and `z`
  (size), maintained by the firmware on every `fs_write` eof (it already
  accumulates the CRC for transfer verification), every `fs_delete`, and
  every wheel-menu reassign. This is what lets the app skip re-reading
  unchanged files at connect (per-UID cache diff). A file written by the
  rescue console has a stale/absent entry and is simply re-read — the
  manifest is advisory, never trusted over a mismatch.
- **Clear-on-write** — a serial write of a macro body drops that stem's
  override fields: the writer baked current values into the header, so a
  stale override must never shadow them. This single rule is also the
  old-app compatibility story: an old app's whole-file speed edit lands in
  the header and works, because the override it doesn't know about is
  cleared by its own write.
- `macro_changed reason:"speed"` is unchanged on the wire, but on proto ≥ 14
  the app answers it by re-reading the small sidecar, not the macro body.
- **`set_cfg`** — the one new command: live patches for display-level config
  fields (layer names, band toggles, timeout, lang) with no reload — see the
  Host → Device table.

Old firmware never creates the sidecar (the app then uses full writes, as
before); old apps never read it (clear-on-write keeps them correct).

v13 (firmware 0.26.0) is the **OBS Center** release. Three additions, all on
the existing `mtype:"obs"` shape and all additive:

- **`obsview:"center"`** — a third OBS view: the live dashboard a key of kind
  `obs_center` opens. Optional new fields on the same `menu` message: `mute`
  (bool — inverts the MIC label), `cpu` / `fps` / `drop` (ints — the health
  row), `klabels` (list of ≤6 short strings — the quick-key row along the
  bottom), and `focus` (`"mic"`|`"scene"` — which control row the wheel
  drives, drawn as a frame around that row's label). **A field the app never
  sends is a widget the device never draws**, and the enabled ones reflow
  vertically — that is how the app's per-key widget toggles reach the glass
  without a schema. On the center view a **held** CONFIRM sends
  `menu_ev ev:"mode"` (a tap still sends `fire`); the app answers by cycling
  `focus` — the device never owns the cycle.
- **Sticky re-renders** — while an `mtype:"obs"` menu is open, a re-send
  merges only the fields present in the message into the open menu (old
  behavior rebuilt the whole state). The app can push a 40-byte delta
  (`{"t":"menu","mtype":"obs","mic":42}`) between full re-asserts; the
  device's copy keeps everything else. Full pushes every ~5 s heal any delta
  lost during a repaint.
- **Key swallowing** — while the center view is open the six keys do NOT play
  their local macros. Their edges still stream as `btn` (as always), and the
  app runs them as the dashboard's quick actions. BACK closes the view (the
  usual `menu_ev ev:"close"`), and a transfer starting mid-session sends the
  same `close` so the app tears the session down.

Old apps never send `obsview:"center"` so old-vs-new pairings keep the exact
v12 behavior.

v12 (firmware 0.25.0) adds two things, both additive:

- **Hand-drawn icons** — the macro `icon` field may be the picture instead of a
  name: `"icon":"px:183c7effc3c30000"` is 16 hex digits, one byte per row,
  bit 7 = leftmost pixel — the same packing `icons/src/icons.txt` compiles to.
  `icons.get()` decodes it rather than looking it up, so a drawing needs no
  second file, no index, and travels inside the macro it belongs to (a backup
  carries it; a delete takes it with them). A malformed one reads as "no icon"
  and falls back to the kind's default. Firmware < 0.25.0 simply doesn't
  recognise the name and draws that default, so the app only offers the
  drawing grid above it.
- **`wheel_layers` in `hello`** — the Vision 6 wheel-paging mode (config.json
  `"wheel_layers"`, already editable in the device's own SETTINGS menu) is now
  reported, so the app can render the switch for it. Absent = firmware that
  predates the field, which is how the app knows to say so.

v11 (firmware 0.23.0) is the **new menu** release. Two additions:

- **Macro `icon`** — a macro file may carry a top-level `"icon":"<name>"` naming
  one of the 270 icons in `icons/src/icons.txt`. The Vision 6 grid draws it
  above the key's name. Absent means "the action kind's default"
  (`KIND_ICON` in `firmware/mkyada/ui.py`), which is what every existing file
  gets. Icons are addressed **by name, never by index**, so extending or
  reordering the family cannot repoint an existing macro at a different
  picture; an unknown name falls back to the default rather than blanking the
  cell. Old firmware ignores the field entirely. Since v12 the field may also
  carry the eight rows inline (`px:` above) instead of a name, and the reserved
  name `"none"` means *draw nothing* — distinct from an absent field, which
  means "use the kind's default".
- **`mtype:"obs"`** — a fourth wheel-menu shape (see `menu` below): a live OBS
  status screen rather than a chooser.

Both are **additive**. An old app never sends either and a new device behaves
exactly as v10; a new app talking to old firmware gets the unknown `mtype`
drawn as a card and the unknown `icon` field skipped.

v10 (firmware 0.20.0) removed `font` from `hello` and from `config.json`: one
font ships with the firmware and the device no longer takes a choice.

v9 (firmware 0.18.0) adds the **context-aware wheel menu** on the Vision 6.
Pressing the wheel (CONFIRM) on a selected key no longer always opens the speed
editor — it opens a menu that fits the key's action. Local kinds (keystroke
turbo, media, scroll, the speed editor) run entirely on the device. Host kinds
(OBS, webhook, command, launch, sound, mic, system volume) ask the app for a
menu over new messages:
- `{"t":"hostinfo","menus":1}` (host→device) — the app advertises wheel-menu
  support. Sent on every `hello`. Without it (an old app), host-kind keys keep
  showing the "app required" toast; the flag clears on disconnect.
- `{"t":"ctx",...}` (device→host) — a host-kind key was pressed; the app should
  answer with a `menu`.
- `{"t":"menu",...}` (host→device) — render/update the on-screen menu (a
  scrollable `list`, a `slider`, or a status `card`). Re-send to live-update
  (REC timer, external volume). 
- `{"t":"menu_ev",...}` (device→host) — the user turned/pressed/closed the menu.
- `{"t":"menu_result",...}` (host→device) — close the menu, optionally toast and
  invalidate a rewritten macro's cached label.

All are **additive**: old firmware ignores the unknown `menu`/`hostinfo`/
`menu_result` types and never sends `ctx`/`menu_ev`; a new device paired with an
old app simply never sees `hostinfo` and keeps the local behavior.

v8 (firmware 0.15.0) added `{"t":"profile","id":"p_<id>"}` (host→device): the
app activates a per-app profile natively — macro paths redirect to the
profile's files so the on-device grid, wheel and speed editor run it without
host mode. `{"id":null}` clears it. Replies `ok`.

v7 (firmware 0.11.0) is the update-safety release:
- **Locked update mode** — `{"t":"update_begin","bytes":N}` suspends keys,
  menus and playback, shows a progress screen on the Vision 6, and accepts
  only transfer traffic (`fs_*`, `update_*`, `get_config`, `reset`,
  `bootloader`) until `{"t":"update_end"}` (ok + hard reset) or
  `{"t":"update_abort"}` (unlock, back to normal). Anything else is refused
  with `{"t":"err","code":"updating"}`. If the app goes silent for 30 s
  mid-update (or disconnects), the device unlocks itself.
- **CRC-verified transfers** — the final `fs_write` chunk may carry
  `"crc": <CRC32 of the whole file>`; the device verifies before the atomic
  rename and answers `{"t":"err","code":"crc"}` on mismatch (the `.part` is
  discarded — a corrupted transfer can never replace a good file). The eof
  `ok` and the final `fs_chunk` of `fs_read` always carry the device-computed
  `"crc"` so either side can verify.
- **`{"t":"bootloader"}`** — reboots into the UF2 bootloader
  (`microcontroller.RunMode.UF2`), so CircuitPython itself can be reflashed
  on a sealed unit without the physical BOOT button.
- **Rescue console** — if the main firmware fails to import or construct,
  `code.py` answers `identify` itself with
  `{"t":"hello","mode":"rescue","err":"<repr of the failure>",...}` and
  serves `fs_*` / `reset` / `bootloader` using builtins only, so the app can
  always rewrite the firmware and reboot the board. LED blinks red.
- Firmware-side hardening (no wire changes): auto-reload is disabled (file
  copies onto the visible drive no longer reboot the board per file — the
  app ends updates with an explicit `reset`), a hardware watchdog hard-resets
  a hung firmware (config `"watchdog": false` opts out for bench debugging),
  serial keeps draining during tap/double/hold gesture resolution, and
  `usb_cdc` writes carry a timeout so a stalled host can never wedge the
  keypad.

v6 (firmware 0.10.0) adds:
- `{"t":"scroll"}` — direct wheel ticks with optional modifiers. The app
  drives profile wheel slots through this instead of per-detent `play`
  round-trips, and applies its own acceleration (Settings → Keypad → Wheel
  acceleration), so a spin feels like a real mouse wheel.
- `label.keys` — the profile's six key names; the Vision 6 host-mode screen
  shows them as a grid instead of the bare "Connected to app" text.
- The mouse HID interface is split into two reports (pointer id 2: buttons +
  absolute X/Y; scroll id 4: wheel + pan). Scrolling no longer re-asserts
  the last absolute position, which used to teleport the cursor to screen
  center. Needs a power-cycle after a firmware update (boot.py re-runs).

v5 adds `hold: true` on `play`: for a plain single-key macro the device
presses the HID key and **keeps it down until `stop`** (or until the app goes
silent) — the host OS's typematic repeat then types like a held letter key.
This is how host mode gives profile single keys the real-keyboard hold that
standalone keys get natively (see macro-format.md `settings.hold_repeat`).

v4 (firmware 0.5.0) is a **capability signal only** — no new messages. A
device announcing `proto >= 4` in `hello` understands the v4 **stream macro
layout** (JSONL, see macro-format.md): the app then writes full-fidelity
recordings instead of thinned ones. Classic whole-file macros keep playing.

Firmware 0.7.0 adds **additive** messages/fields (still proto 4 — old hosts
ignore them, old firmware never receives them): `hello.model` + `hello.pins`,
the `macro_changed` / `enc` / `pin` announcements, the `pin_detect` command,
and the `btn.slot` variant for the Vision 6 module buttons. See
[Two models](#two-models-firmware-070) below.

Firmware 0.9.0 adds the additive `label` command (the app pushes its active
profile name for the Vision 6 grid band) plus the config fields
`show_layer` / `show_profile` and their mirrors in `hello` — the band over
the macro grid that names the active layer and/or the app's active profile
(issue #18). Old firmware ignores `label`; old hosts never see the fields.

v3 adds the `fs_*` file management commands (hidden-drive mode).
v2 (firmware 0.3.0) adds: `btn` streaming in standalone mode, the `key_action`
announcement for key-logic variants, and the `led` feedback override. v1 hosts
keep working — all v1 messages are unchanged.

Transport: **JSON-lines over the second USB CDC channel** (`usb_cdc.data`).
One JSON object per `\n`-terminated line, both directions. The `t` field is the
message type. Commands are tiny by design — **bulk data (configs, macros) never
travels over serial**; the host writes files to the CIRCUITPY drive, flushes,
then sends `reload` or `play`.

Device discovery: scan serial ports for USB product string **"MKYADA Keypad"**,
open the *data* interface, send `identify`, expect `hello`. Match the serial
port to its CIRCUITPY volume via the `UID:` line in `boot_out.txt` vs `hello.uid`.

## Layer announcements

Whenever the active layer changes (layer key pressed, `set_layer`, `reload`)
the device emits:

```json
{ "t": "layer", "layer": "b" }
```

The app uses it for the live layer indicator in the sidebar.

## Modes

```
STANDALONE ──(host_enter)──► HOST ──(host_leave | CDC disconnect | 5 s without any message)──► STANDALONE
```

- **Standalone:** keys play their macro files locally; serial commands still
  work. Since proto v2, key edges are **also streamed as `btn`** while an app
  is connected (the device still acts on them itself) — this powers
  computer-side key actions and the live keypad view without host mode.
- **Host:** keys do **not** act locally; every edge is streamed as `btn` and the
  device only acts on host commands. The app must send `ping` every ~2 s.

## Host → Device

| Message | Effect |
|---|---|
| `{"t":"identify"}` | Reply with `hello` |
| `{"t":"ping"}` | Reply `pong`; refreshes the host-mode watchdog |
| `{"t":"host_enter"}` / `{"t":"host_leave"}` | Switch mode; reply `ok` |
| `{"t":"play","file":"macros/key1.json","speed":1.5,"repeat":2}` | Play a file from the drive. `speed`/`repeat` optional (default: the macro's own `settings`; `repeat: 0` = loop). v5: optional `"hold": true` — a plain single-key macro is pressed and **held until `stop`** (real-keyboard hold; the sender must send `stop` on the key's up edge) |
| `{"t":"stop"}` | Abort current playback. v17: replies `{"t":"ok","re":"stop","was_playing":bool}` |
| `{"t":"press","key":3,"layer":"a","gesture":"tap"}` | v17. Remote key press — see the v17 notes at the top |
| `{"t":"keys","mods":["CTRL","SHIFT"],"key":"s"}` | Tap a combo directly (no file) |
| `{"t":"get_config"}` | Reply with `config` |
| `{"t":"set_cfg","patch":{"layer_names":["Oyun"],"show_layer":true}}` | v14. Patch display-level config fields LIVE — applied, persisted into config.json and repainted with **no reload** (issue: a layer rename used to cold-restart the board and re-read every macro). Whitelist: `layer_names`, `show_layer`, `show_profile`, `wheel_layers`, `timeout`, `lang`. Values are validated/normalized like `load_config` does. Replies `ok` + a fresh `config` announcement; unknown fields → `err bad_field`, bad values → `err bad_value`. Structural fields (key_count, layers, pins, model, usb_drive, enc_swap) stay on the config-write + `reload` path on purpose |
| `{"t":"reload"}` | Re-read `config.json` (send after writing files); resets layer to A; replies `ok` + fresh `hello` |
| `{"t":"set_layer","layer":"b"}` | Force the active layer |
| `{"t":"led","mode":"solid","rgb":[255,0,0]}` | v2. Override the status LED with a feedback color (`mode`: `solid` \| `blink` \| `off`). Playback blinks still win; the override auto-clears when the app disconnects, so the standalone LED grammar is untouched. |
| `{"t":"fs_list","path":"macros"}` | v3. Reply with `fs_list` (directory entries) |
| `{"t":"fs_read","path":"macros/key1.json"}` | v3. Stream the file back as `fs_chunk` messages; the host must answer each non-final chunk with `{"t":"fs_ack"}` (one chunk in flight) |
| `{"t":"fs_write","path":"macros/key1.json","seq":0,"data":"<base64>","eof":false}` | v3. Chunked upload (≤3 KB raw per chunk); every chunk is acknowledged with `ok`. Written to `<path>.part`, renamed into place on `eof` — a dropped transfer never corrupts the target. Needs a writable filesystem, i.e. `usb_drive: false` (otherwise `err readonly`) |
| `{"t":"fs_delete","path":"macros/key1.json"}` | v3. Delete a file; replies `ok` |
| `{"t":"label","text":"Photoshop","keys":["Zoom in","Zoom out","Undo","","",""]}` | fw 0.9.0, Vision 6. Name of the app's active profile (≤24 chars) for the grid band shown when config `show_profile` is on. Since v6 the optional `keys` (6 strings, ≤24 chars each) are the profile's key names — the host-mode screen draws them as a grid. Empty text / absent keys clear; the device also drops both on app disconnect. Replies `ok` |
| `{"t":"scroll","dy":4,"dx":0,"mods":["ctrl_l"]}` | v6. Direct wheel ticks: `dy` vertical, `dx` horizontal (sign = direction, ≤20 per burst), optional `mods` held around the burst (Ctrl+wheel = zoom). No file, no `play_start`/`play_done` — the profile-wheel fast path. Replies `ok`, or `err hid` if the USB stack rejects the report |
| `{"t":"pin_detect","on":true}` | fw 0.7.0. Key-wiring wizard: normal key handling is suspended, every non-reserved edge GPIO is watched and edges stream back as `pin` messages. Auto-disarms after 120 s, on app disconnect, or on `reload`. `{"on":false}` restores the keys |
| `{"t":"hostinfo","menus":1}` | v9, Vision 6. The app advertises wheel-menu support. Send once per `hello`. Enables the context-aware wheel menu for host-kind keys; without it they show the "app required" toast. No reply. Cleared on disconnect |
| `{"t":"sysvol","percent":40}` | v9, Vision 6. The live system output volume (0–100); the device can't read it, so the app pushes it (on change) while connected. Volume-kind grid cells show the `%`. No reply. Cleared on disconnect |
| `{"t":"menu","mtype":"list","key":3,"layer":"a","title":"SCENE","items":[["Intro","Intro",1],["Game","Game",0]],"sel":0,"action":"Pick"}` | v9, Vision 6. Render/update the open wheel menu. `mtype`: `card` (title + `big` hero line + optional `l1`/`l2` status + `hint` action), `slider` (`value`/`min`/`max`/`step`/`unit` + `action`), `list` (`items` = `[id,label,mark]`, `sel` cursor, `action`). Re-send to live-update; the device keeps the cursor and idle timer. Ignored unless a menu is open for `key` |
| `{"t":"menu","mtype":"obs","key":2,"obsview":"rec","rec":true,"live":false,"mic":60,"time":"00:12","scene":"Intro","hint":"stop"}` | v11, Vision 6. A live OBS status screen instead of a chooser. `obsview`: `rec` (recorder card — one large timer) or `main` (full status: state chip, timer, scene pill, mic segments). `rec`/`live` drive the state chip, `mic` is 0–100, `time` is the elapsed string, `scene` the active scene. Push it as often as you like — there is no cursor to lose, so a re-render is pure data. The **blinking record dot is the device's own**, on a 0.6 s clock, so it keeps its rhythm when a push is late. CONFIRM sends `menu_ev ev:"fire"`, a wheel step sends `ev:"value"` with `v: ±1` |
| `{"t":"menu","mtype":"obs","key":4,"layer":"a","obsview":"center","rec":true,"live":false,"time":"00:42:10","scene":"Gameplay","mic":64,"mute":false,"cpu":8,"fps":60,"drop":0,"focus":"mic","klabels":["MUTE","CAM","CLIP","","","REC"]}` | v13, Vision 6. The OBS Center dashboard (kind `obs_center`). Every field beyond `obsview` is optional: **an absent field is a widget the device never draws**, and the enabled ones reflow (the timer renders 2× unless everything is on at once). `mute` inverts the MIC label; `cpu`/`fps`/`drop` fill the health row; `klabels` (≤6 strings, ≤6 chars, drawn fitted to ~5) is the quick-key row; `focus` frames the control row the wheel drives (`mic`\|`scene`). **Re-sends merge**: only the fields present in the message change, so `{"t":"menu","mtype":"obs","mic":42}` is a legal 40-byte delta — push a full state every ~5 s to heal lost deltas. While this view is open the six keys don't play their macros (their `btn` edges are the app's quick actions), there is no idle timeout, a **held** CONFIRM sends `menu_ev ev:"mode"` (focus cycle), and BACK closes it |
| `{"t":"menu_result","ok":true,"toast":["SCENE","Saved"],"changed":"/macros/key3-a.json"}` | v9, Vision 6. Close the open menu. `toast` (optional `[title,line]`) shows briefly; `changed` (optional path) invalidates that macro's cached label so the grid updates without a `reload`. `ok:false` shows the toast as an error |

## Device → Host

| Message | When |
|---|---|
| `{"t":"hello","fw":"0.1.4","proto":1,"format":"mkyada","uid":"e66...","key_count":6,"layer_key":null,"layer_count":2,"layer_mode":"toggle","key_map":[1,2,3,4,5,6],"layer":"a","mode":"standalone"}` | Reply to `identify`, and after `reload`. Since fw 0.7.0 also `"model":"core6"\|"vision6"` (absent = core6) and `"pins":["GP0",...]` (the GPIO names actually driving keys 1..n) |
| `{"t":"macro_changed","file":"/macros/key3-b.json","reason":"speed"}` | fw 0.7.0, Vision 6. The user edited that macro's `settings.speed` on the device (persisted into the file). The app should re-read the file / refresh its cache |
| `{"t":"enc","d":1,"n":3}` | fw 0.7.0, Vision 6, host mode. Encoder detents (`d` = direction, `n` = count batched per poll) — lets the app run computer-side wheel actions |
| `{"t":"btn","slot":"back","down":true}` | fw 0.7.0, Vision 6, host mode. Module buttons (`psh` \| `back` \| `confirm`) — the slot variant of `btn`, distinct from key events |
| `{"t":"ctx","key":3,"layer":"a","kind":"obs","sub":"setScene","file":"/macros/key3-a.json"}` | v9, Vision 6. The wheel was pressed on a host-kind key (`kind` = `obs`/`obs_center` (v13)/`webhook`/`command`/`launch`/`sound`/`mic`/`volume`; `sub` = the action detail, e.g. the OBS action or media usage; `file` = the exact macro path, profile-aware). The app answers with a `menu`. Only sent after `hostinfo`. For `obs_center` a bare key press opens the menu too (like `volume`/`mic_level`). v15: `kind:"enc_module"` is an **announcement only** — the Dial is device-local, the app must not answer with a `menu` (it only mutes its own `btn` handling until `menu_ev ev:"close"`) |
| `{"t":"menu_ev","ev":"pick","id":"Intro"}` | v9, Vision 6. The user acted on the open menu: `pick` (a **tap** on a list item — use it live), `assign` (a **hold** on a list item — reassign the key to it), `fire` (a card's CONFIRM), `value` (`v` = a slider's new value, or ±1 on a card), `close` (BACK / idle / disconnect). The app performs it and usually replies `menu`/`menu_result` |
| `{"t":"pin","pin":"GP13","down":true}` | fw 0.7.0. While `pin_detect` is armed: a watched GPIO changed — the wiring wizard assigns it to the key being probed |
| `{"t":"btn","key":2,"phys":4,"layer":"a","edge":"down"}` | Every press/release. `key` = logical (after `key_map`), `phys` = GPIO number. Host mode: always; standalone: since v2, while an app is connected |
| `{"t":"key_action","file":"/macros/key2.json","key":2,"layer":"a","variant":"double"}` | v2. A key with key-logic `variants` resolved its gesture (`tap` \| `double` \| `hold`) in standalone mode. The app uses it to run host-side variants (launch/command/sound). Since fw 0.9.0 a Vision 6 module slot resolving its own gesture announces the same message with `"key": null` and the slot's file path |
| `{"t":"play_start","file":"/macros/key1.json","key":1,"layer":"a","loop":false,"src":"key"}` | Playback began. `key`/`layer`/`loop`/`src` since v17 |
| `{"t":"play_done","file":"/macros/key1.json","stopped":false,"reason":"done"}` | Playback ended (`stopped: true` = aborted). `reason` since v17 |
| `{"t":"config", ...config.json fields...}` | Reply to `get_config` |
| `{"t":"ok","re":"reload"}` | Command acknowledged |
| `{"t":"err","re":"play","code":"not_found","msg":"/macros/key9.json"}` | Codes: `not_found`, `bad_json`, `bad_format`, `oom`, `io`, `hid` (USB stack rejected a report — boot.py descriptor older than engine.py after a partial update; power-cycle to heal) |
| `{"t":"pong"}` | Reply to `ping` |
| `{"t":"fs_list","path":"/macros","entries":[{"name":"key1.json","size":123,"dir":false}]}` | v3. Reply to `fs_list` |
| `{"t":"fs_chunk","path":"/macros/key1.json","seq":0,"data":"<base64>","eof":true}` | v3. `fs_read` stream; the last chunk carries `eof: true` |
| `{"t":"ok","re":"fs_write","seq":3,"eof":true}` | v3. Chunk acknowledged (final ack carries `eof`) |
| `{"t":"err","re":"fs_write","code":"readonly"}` | v3. fs codes: `bad_path`, `bad_seq`, `not_found`, `readonly` (drive visible → host owns the filesystem), `io`, `busy` (mid-playback) |

## Playback interaction rules

- During playback the device still answers `ping`/`identify` and honors `stop`
  and (v17) `press`.
- **Panic stop:** pressing the key that started the macro (standalone), or any
  key (host-commanded playback), aborts it and releases all pressed inputs.
- `fs_*` commands during playback are answered with `err busy` (so the app
  never waits on a reply that will not come); everything else is ignored.

## Hidden-drive mode (v3)

The CIRCUITPY drive is **hidden by default** (finished-product mode) — it is
shown to the host only when `config.json` sets `"usb_drive": true`. When
hidden, boot.py remounts the filesystem writable for the firmware, which is
what makes `fs_write`/`fs_delete` possible. The app manages every file over
the `fs_*` commands and passes a `serial:<uid>` sentinel instead of a mount
path internally. `hello` reports the state as `usb_drive` (absent on firmware
< 0.4.0). An absent/unreadable config keeps the drive hidden — the same
default a fresh firmware install gets. Recovery without the
app: hold key 1 while plugging the keypad in — GP0 on Core 6, GP29 (macro
key 1) on Vision 6, whose GP0 belongs to the OLED. The drive comes back for
that session.

## USB MIDI (v16)

`config.json "midi": true` makes the board present a USB MIDI port alongside
the keyboard, so a `midi` key can drive a DAW with nothing running on the
computer. Off by default. Like `usb_drive` this is decided in boot.py, so
`set_cfg` refuses the field — write config.json and `{"t":"reset"}`; a
`reload` will not re-run boot.py. `hello` reports it as `midi` (absent on
firmware < 0.29.0).

The port is named after the product string. Two host quirks worth knowing:
Windows will not enumerate a device whose audio-control interface name is over
31 characters (both product strings are well under), and macOS caches MIDI
port names in Audio MIDI Setup, so a renamed port needs that cache cleared
before the new name shows up.

MIDI is skipped while the CIRCUITPY drive is visible. The RP2040 has 7 USB
endpoint pairs; the firmware already spends 5, or 6 with the drive, and MIDI
wants one more — rather than sit exactly on the ceiling, the drive wins,
because the drive is the recovery path.

## Two models (firmware 0.7.0)

One firmware serves both devices; `config.json "model"` picks the variant
(`"core6"` default; a config-less board auto-probes I2C 0x3C once):

- **core6** — unchanged behavior, plus the additive hello fields.
- **vision6** — SH1106 OLED + EC11 encoder + BACK/CONFIRM buttons.
  `layer_key` is always `null` (all six keys are macro keys); the layer is
  chosen on the device screen, `layer_count` may be 1..8 (a single layer
  shows just A + SETTINGS on the home screen). USB product string is
  "MKYADA Vision 6". Discovery matches the "MKYADA" prefix either way.

`config.json` additions (both models): `"model"`, and `"pins"` — an explicit
per-key GPIO-name list (e.g. `["GP29","GP28","GP27","GP26","GP15","GP13"]`)
for keys soldered off the model's default order; `null` = default. Reserved
pins are refused (core6: GP16; vision6: GP0-GP6 + GP16).

### Grid band (firmware 0.9.0, vision6)

`config.json` `"show_layer"` / `"show_profile"` (booleans, default false)
draw an inverted strip over the macro grid; the six cells squeeze under it.
`show_layer` names the active layer ("Layer A") — fully device-side.
`show_profile` shows the last `label` text the app pushed (its active
per-app profile); with both on the band reads "A: Photoshop". Both toggles
are editable in the app (Settings → Keypad, config write + `reload`) and on
the device (SETTINGS menu, which rewrites config.json like the language
setting — needs the hidden-drive mode, else the filesystem is host-owned
and the device shows the read-only notice). `hello` mirrors both fields so
the app can render the switches without reading the file.

`config.json` `"wheel_layers"` (boolean, default false) is the third screen
toggle and rides the same path: past the sixth tile the wheel wraps into the
next layer's first key instead of stopping, and the grid grows a page
counter. Off by default — it changes what the wheel does, and an existing
keypad must not have that move under it on an update. `hello` reports it
since v12 (firmware 0.25.0); before that the app can't read the state and
says so instead of guessing.

### Encoder / module-button custom slots (vision6)

The app may assign macros to four virtual slots, stored exactly like key
macros: `macros/enc-cw.json`, `macros/enc-ccw.json`, `macros/btn-back.json`,
`macros/btn-confirm.json` (+ `-<layer>` suffix; a layer without its own file
falls back to the unsuffixed one). When any slot is assigned on the active
layer, the resting grid plays those macros on rotate/press instead of menu
navigation; the encoder push (PSH) always stays a menu key (it toggles a
temporary select mode with default navigation). Empty slots = built-in menu
behavior. On-device speed edits rewrite the target file's `settings.speed`
and announce `macro_changed`; a visible (read-only) drive degrades the edit
to an explanatory screen.

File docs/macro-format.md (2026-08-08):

# mkyada-macro JSON format (v2 / v3 / v4 stream)

A macro is a single JSON file. **Everything a key can do is a macro file** — a
plain Ctrl+A binding, a typed text snippet, a media key, or a full recorded
mouse+keyboard sequence. Copy the file to another board and it behaves
identically.

## Top level

```json
{
  "format": "mkyada-macro",
  "version": 2,
  "name": "Select All",
  "created": "2026-07-04T12:00:00Z",
  "kind": "combo",
  "combo": { "mods": ["CTRL"], "key": "A" },
  "screen": { "width": 1920, "height": 1080 },
  "settings": { "speed": 1.0, "repeat": 1 },
  "events": [ ... ]
}
```

| Field | Required | Meaning |
|---|---|---|
| `format` | yes | `"mkyada-macro"`. Legacy `"asil-macro"` (v1) files are also accepted. |
| `version` | yes | `2`, or `3` when the file carries key-logic `variants` |
| `name` | no | Display name |
| `created` | no | ISO 8601 timestamp |
| `kind` | no | UI metadata: `"combo"` \| `"keystroke"` \| `"text"` \| `"media"` \| `"volume"` \| `"mic_level"` \| `"scroll"` \| `"recorded"` \| `"launch"` \| `"command"` \| `"sound"` \| `"mic"` \| `"webhook"` \| `"obs"` \| `"obs_center"` \| `"enc_module"` \| `"midi"` \| `"sequence"`. The app uses it to show and re-edit the assignment. Since firmware 0.18.0 the Vision 6 also reads `kind` to pick the [wheel menu](actions.md#wheel-menu-vision-6): `"volume"` (system-volume slider; press plays the `mute` consumer event so it still works standalone) and `"mic_level"` (mic input-gain slider, host-only, empty events) open on a bare key press; `"media"` becomes a browser (turn to pick a usage, hold to reassign — the device rewrites this file). |
| `combo` / `text` / `seq` … | no | UI metadata matching `kind` |
| `sounds` / `targets` / `commands` / `webhooks` | no | Multi-value host keys (app ≥ 0.38.0): the key's full sound/target/command list (`sound`/`target`/`command` stays the default the press uses and is a member), or the webhook's **alternative** requests (the default stays in `webhook`). `sounds` entries are `{label?, sound}` and `commands` entries `{label?, command}` — the wheel shows the label when given, else the file name / command line; `targets` are plain strings (the file name is the label). The Vision 6 wheel lists them — tap uses one now, hold makes it the default (the app rewrites this file). Old firmware/app versions ignore the extra fields and just use the default. |
| `screen` | for mouse macros | Capture resolution; absolute coordinates are rescaled from it (`x * 32767 / (width-1)`). |
| `settings.speed` | no | Playback speed multiplier (default `1.0`; `2` = half the run time). The wheel offers it for recorded, text and sequence keys; sequences scale their step delays with it, host-side too. **Since proto v14 (fw ≥ 0.27.0) this field is only the fallback**: a speed set on the device (or a speed-only edit on a big file in the app) lands in the [`meta.json` sidecar](#meta-sidecar--macrosmetajson-proto-v14) and shadows it — the macro body is never rewritten for a speed change. Older firmware keeps rewriting this field in place (`macro_changed`, fw ≥ 0.7.0). |
| `settings.repeat` | no | Repeat count. **`0` = loop until the key is pressed again.** Default `1`. |
| `settings.on_repress` | no | What pressing the macro's own key does while it plays: `"stop"` (default) or `"restart"` (play again from the top). |
| `settings.hold_repeat` | no | Holding the physical key repeats the macro, like holding a letter key. **Default `true` for plain single-key macros** (one key down + its up, `kind` absent or `"keystroke"`) — the firmware then simply keeps the HID key down and the host OS's typematic repeat produces the stream at the user's own keyboard rate. Default `false` for everything else (those replay the file per pass). `false` opts a single key back into play-once. Ignored when `variants` exist. |
| `settings.hold_ms` | no | Key logic: press-and-hold threshold in ms (default `400`). |
| `settings.double_ms` | no | Key logic: double-press window in ms (default `250`). |
| `events` | yes | Ordered event list (the **tap** action when `variants` exist) |
| `variants` | no | Key logic (v3), see below |

## Key logic — `variants` (v3, firmware ≥ 0.3.0)

One key can do three things: tap, double press, and long press. The top-level
`events` are the **tap**; `variants.double` / `variants.hold` each carry their
own `events` (and optional `settings`):

```json
{
  "format": "mkyada-macro",
  "version": 3,
  "events": [ ...tap events... ],
  "settings": { "hold_ms": 400, "double_ms": 250 },
  "variants": {
    "double": { "kind": "combo", "combo": {...}, "events": [ ... ] },
    "hold":   { "kind": "launch", "target": "https://…", "events": [] }
  }
}
```

- The firmware resolves the gesture itself in standalone mode and announces
  the choice to a connected app as `{"t":"key_action", ...}` (see
  serial-protocol.md) so host-side variants (launch/command/sound) still work.
- A `double` variant necessarily delays the tap by up to `double_ms`; without
  one the tap fires with **zero added latency**.
- **Graceful degradation:** firmware older than 0.3.0 ignores `variants` and
  simply plays the tap.
- **Vision 6 module slots** (`btn-back` / `btn-confirm` / `btn-psh` files,
  fw ≥ 0.9.0) carry the same `variants`; the menu module resolves the
  gesture from its own buttons. A variant may itself be a `menu` action —
  it then drives the built-in navigation (`key_action` is announced with
  `"key": null`). Encoder rotation files have no gestures to resolve.

## Multi actions — `kind: "sequence"`

A sequence chains several actions on one press. If every step is HID-expressible
(keystroke/combo/text/media/recorded), the steps are compiled **into the single
`events` list** (with `wait` events in between) — fully standalone. If a step
needs the computer (launch/command/sound), `events` stays empty, the editable
step list lives in `seq`, and the desktop app orchestrates: HID steps are
pre-compiled into sibling part files (`key3.s0.json`, `key3.s2.json`, …) it
plays over serial — still hardware HID — while host steps run on the computer.
Part files are inert on the device (the firmware only plays exact key-file names).

## Events

Every event has `delay` — milliseconds to wait **before** executing it.

```json
{ "delay": 0,   "type": "key",      "action": "down", "key": "a", "vk": 65 }
{ "delay": 30,  "type": "key",      "action": "up",   "key": "a", "vk": 65 }
{ "delay": 120, "type": "move",     "x": 960, "y": 540 }
{ "delay": 8,   "type": "button",   "action": "down", "button": "left", "x": 960, "y": 540 }
{ "delay": 60,  "type": "button",   "action": "up",   "button": "left", "x": 960, "y": 540 }
{ "delay": 10,  "type": "scroll",   "dy": -1 }
{ "delay": 10,  "type": "scroll",   "dy": 0, "dx": 2 }
{ "delay": 15,  "type": "consumer", "usage": "volume_up" }
{ "delay": 0,   "type": "midi",     "m": "note_on", "ch": 0, "d1": 60, "d2": 100 }
{ "delay": 0,   "type": "midi",     "m": "note_off", "ch": 0, "d1": 60 }
{ "delay": 0,   "type": "midi",     "m": "cc",  "ch": 0, "d1": 74, "d2": 64 }
{ "delay": 0,   "type": "midi",     "m": "pc",  "ch": 3, "d1": 5 }
{ "delay": 500, "type": "wait" }
```

- `key`: `key` is a pynput-style label (`"a"`, `"ctrl_l"`, `"f5"`, `"enter"`, …); `vk` is the optional Windows virtual-key code. Resolution order: modifier tables → `vk` → name → character (see `firmware/mkyada/hidmap.py`).
- **Labels are positional (US physical keys)**, because HID keycodes are positional too — the OS renders them through the active keyboard layout. Recording the "." key on a Turkish-Q keyboard stores `"/"` (its US position) and still types "." on playback. The app *displays* labels through your real layout, so you never see the raw US name.
- `button`: `left` | `right` | `middle`. Optional `x`/`y` moves the pointer first.
- `scroll`: `dy` is vertical wheel ticks (+up / −down); `dx` is horizontal pan
  ticks (+right / −left, via the AC Pan channel added to the mouse descriptor
  in firmware ≥ 0.8.0). Each unit is one detent-sized report.
- `consumer` usages: `play_pause`, `next_track`, `prev_track`, `stop`, `mute`, `volume_up`, `volume_down`, `brightness_up`, `brightness_down`.
- `midi` (fw ≥ 0.29.0, proto v16): `m` is `note_on` | `note_off` | `cc` |
  `pc`; `ch` is the channel 0-15 (DAWs show it 1-16); `d1`/`d2` are the two
  MIDI data bytes — note+velocity, controller+value, or program (`pc` has no
  `d2`). All four values are masked to their wire width on the device. Sent
  only when the board's `midi` config key is on, which is decided at boot;
  with MIDI off the event is a silent no-op. Firmware older than 0.29.0
  skips the whole event type, so a `midi` macro degrades instead of failing.
- `wait`: pure delay, no action.

**`kind: "enc_module"`** — the Dial (fw ≥ 0.28.0, proto v15, screen models).
A device-native encoder toolset: pressing the key opens a full-screen module,
the six keys select one of up to six *slots*, and turning the encoder runs the
selected slot as plain HID — no app needed. The payload is `enc_module`:

```json
"enc_module": { "slots": [
  { "l": "JOG",  "t": "keys", "cw": {"mods": [], "key": "right"},
    "ccw": {"mods": [], "key": "left"}, "m": 1,
    "b": {"t": "combo", "mods": [], "key": "space"} },
  { "l": "ZOOM", "t": "scroll", "axis": "v", "mods": ["cmd"], "inv": false, "m": 1 },
  { "l": "WHEEL", "t": "move", "axis": "y", "step": 4, "drag": true, "m": 1,
    "b": {"t": "click"} },
  { "l": "VOL", "t": "consumer", "cw": "volume_up", "ccw": "volume_down", "m": 1,
    "b": {"t": "consumer", "u": "play_pause"} },
  { "l": "CUT", "t": "midi_cc", "cc": 74, "ch": 0, "mode": "rel_2c", "m": 1 },
  null ] }
```

- `slots`: exactly 6 entries; `null` = empty slot (that key is dead while the
  module is open).
- `l`: OLED tile label, ≤ 6 chars (clamped again on the device).
- `t` picks the turn action: `"keys"` (`cw`/`ccw` are full modifier combos,
  one tap per detent), `"scroll"` (`axis` `"v"`|`"h"`, optional `mods` held
  around the ticks — Cmd+scroll zoom), `"move"` (relative cursor nudge on
  `axis` `"x"`|`"y"`, `step` px per detent 1–30; `drag: true` holds the left
  button through the turn gesture — for controls with no shortcut, e.g.
  DaVinci color wheels; optional `mods` are held through the gesture too,
  pressed before the button and released after it — Ctrl+Opt+drag is
  Photoshop's brush-size scrub, fw ≥ 0.28.1), `"consumer"` (`cw`/`ccw` are
  consumer usages), `"midi_cc"` (MIDI control change, fw ≥ 0.29.0 — see below).
- `midi_cc` slots carry `cc` (controller 0–127), `ch` (channel 0–15) and
  `mode`. `mode` defaults to `"rel_2c"` and decides what a detent sends:
  `"rel_2c"` two's complement (1–63 up, 127–65 down — Reaper's Relative 1),
  `"rel_bin"` binary offset (64 = no change — Relative 2), `"rel_sm"` sign
  magnitude (sign in bit 6 — Relative 3), `"rel_mackie"` (Mackie V-Pot, the
  same encoding as sign magnitude), or `"abs"`. The relative modes send a
  **delta**, so the DAW's own value is the only one and the parameter can
  never jump; `"abs"` counts the value on the device and *will* jump when the
  two disagree. The absolute value lives only while the module is open — the
  slot dict is never written back to. Unlike the other slot types a CC has no
  per-turn cap: it is one 3-byte message with no sleep. Firmware older than
  0.29.0 treats an unknown `t` as a dead slot, so this degrades quietly.
- `m`: sensitivity 1–10 (units per detent, multiplied by the wheel's own
  velocity acceleration). `inv` flips the direction.
- `b`: the encoder button while this slot is selected — absent = nothing,
  `{"t":"combo",…}`, `{"t":"click"}` (left click via the relative pointer) or
  `{"t":"consumer","u":…}`.
- `events` stays `[]` — the file is a carrier; the firmware parses the payload
  in full when the module opens and drops it again on close. BACK closes; the
  module has no idle timeout. Mouse-drag slots ride the relative pointer
  report (id 5) added to the HID descriptor in the same release.

**`kind: "midi"`** (fw ≥ 0.29.0, proto v16) — MIDI out, hardware like a
keystroke. The keypad is its own USB MIDI device, so the key drives a DAW with
no app in the middle. The payload mirrors the events:

```json
"midi": { "msg": "note", "ch": 0, "d1": 60, "d2": 100, "mode": "momentary" }
"midi": { "msg": "cc", "ch": 0, "d1": 74, "d2": 64 }
"midi": { "msg": "pc", "ch": 3, "d1": 5 }
```

- `msg`: `"note"` (compiles to a note-on/note-off pair), `"cc"`, `"pc"`.
- `ch` 0–15, `d1`/`d2` 0–127. `pc` has no `d2`.
- `mode` applies to notes only. **`"momentary"` (the default) is the important
  one**: the firmware holds the note down for exactly as long as the physical
  key is held and sends note-off on release, which is what Ableton's Looper
  and drum-rack pads require — a note that only ever sends "on" reads as a
  stuck key to them. `"tap"` plays the pair straight through for one-shot
  samples. Both modes emit the same two events; `mode` is what tells the
  firmware which way to run them, so it must survive in the payload.
- The board only sends anything when its `midi` config key is on (boot-time —
  see [serial protocol](serial-protocol.md)). A macro stopped mid-note is
  silenced: the engine tracks sounding notes and sends note-off on release.

**`kind: "menu"`** (screen models) has no HID events. `"menu"` is one of
`left` / `right` / `confirm` / `back`, and the firmware feeds it to the
on-screen menu so a normal key acts like the encoder / CONFIRM / BACK —
including any custom slot assignments, so a key can fully stand in for a
broken wheel. Direct-jump actions (fw ≥ 0.12.0): `"home"` opens the layer
screen, `"settings"` the on-device settings menu, `"grid"` the key grid;
`"layer_next"` / `"layer_prev"` switch the active layer immediately — all
from any key or control.
`"default"` (fw ≥ 0.9.0, module-slot files only) means "this
control's built-in action" — the carrier for slot files whose tap stays
stock while `variants` customize double/long press; on a normal key it is
a no-op. `"none"` (fw ≥ 0.10.0) is the app's "Do nothing" choice: the
firmware swallows the input entirely — on a module slot this overrides
even the built-in navigation, turning the control off.

## Stream layout — v4 (firmware ≥ 0.5.0, proto ≥ 4)

The same macro can be written in a **line-oriented stream layout** so the
firmware plays it straight from flash without loading the whole file into
RAM — this is what removes the old event-count ceiling and lets recordings
play back at full fidelity (no thinning):

```
{"format":"mkyada-macro","version":4,"stream":true,"name":"…","screen":{…},"settings":{…}}
{"delay":15,"type":"move","x":960,"y":540}
{"delay":16,"type":"move","x":964,"y":541}
{"delay":8,"type":"button","action":"down","button":"left"}
```

- **Line 1** is the header: every top-level field except `events`, plus
  `"stream": true` and `version: 4`.
- **Every following line** is one event object (same schema as below), in
  order. Blank lines are skipped; a corrupt line is skipped, not fatal.
- Detection: the firmware reads the first line — if it parses and has
  `"stream": true`, the rest of the file is streamed. A single-line classic
  JSON file, or a pretty-printed multi-line one, falls back to the whole-file
  parser. Same `.json` filenames everywhere.
- `repeat` / loop replays seek back to the first event line — no extra RAM.
- **Limitation:** stream files don't carry `variants` (the app never writes
  that combination). A stray `variants` in a stream header is ignored and the
  file plays as a plain tap.
- **Graceful degradation:** the desktop app only writes the stream layout to
  keypads that announce `proto >= 4` in `hello`; older firmware keeps
  receiving classic (thinned) whole-file JSON.

## File naming on the device

```
CIRCUITPY/
├── config.json          model, key count, pins, layers, busy_other (see firmware/config.example.json)
└── macros/
    ├── key1.json        key 1, layer A
    ├── key1-b.json      key 1, layer B
    ├── key1-c.json      key 1, layer C
    ├── key2.json ...
    ├── enc-cw.json      Vision 6: encoder clockwise, layer A (fw ≥ 0.7.0)
    ├── enc-ccw-b.json   Vision 6: encoder counter-clockwise, layer B
    ├── btn-back.json    Vision 6: BACK button on the resting grid
    └── btn-confirm.json Vision 6: CONFIRM button on the resting grid
```

No app needed: drop a file with the right name onto the drive and press the key.
Vision 6 slot files follow the same layer-suffix rule; a layer without its own
slot file falls back to the layer-A one. The `name` field is what the Vision 6
grid shows for each key (two lines, split at a word gap).

## Meta sidecar — `macros/meta.json` (proto v14)

One small file next to the macros carries per-stem overrides and a
firmware-maintained manifest (fw ≥ 0.27.0, `mkyada/meta.py`):

```json
{"format": "mkyada-meta", "version": 1,
 "entries": {
   "key3":        {"s": 25, "c": 3735928559, "z": 812340},
   "key1-b":      {"i": "px:183c7effc3c30000", "n": "Boss key"},
   "p_ab12_key3": {"s": 15}
 }}
```

The key is the macro file's stem (`key3` → `macros/key3.json`). Fields, all
optional: `s` speed in integer tenths (25 = 2.5×), `i` icon, `n` name — these
**shadow the macro header** on both the device and in the app; `c` (CRC32 of
the file's bytes) and `z` (size) are the manifest the firmware keeps current
on every write/delete so the app can skip re-reading unchanged files.

Why: a speed or icon edit used to rewrite the whole macro on flash. On a long
recording that write could exceed the 8 s hardware watchdog — a reset
mid-write corrupts the FAT and CircuitPython reformats the drive (total data
loss, seen in the field). Small edits now touch only this small file. Rules:

- Override wins over header; a missing entry means "header is the truth".
- A serial write of a macro body clears that stem's overrides (the writer
  baked current values in) — this also keeps older apps correct.
- The app writes overrides only for **big** files (≥ 32 KB serialized);
  small files still get their header edited directly, keeping the sidecar
  and the firmware's resident override dict tiny.
- Deleting `meta.json` is always safe: speeds/icons fall back to the
  headers, and the app re-reads everything once to rebuild the manifest.

## Size guidance

- **v4 stream files** (firmware ≥ 0.5.0): RAM use is constant per event —
  macro length is bounded only by flash space. No thinning needed.
- **Classic whole-file JSON** (older firmware): the RP2040 has 264 KB of RAM;
  keep macros under roughly **2,000 events / 120 KB**. The desktop app thins
  dense mouse-move streams automatically for these devices. If a file is too
  big the firmware blinks red and reports `{"code": "oom"}` over serial
  instead of crashing.

## v1 (`asil-macro`) compatibility

v1 files have `format: "asil-macro", version: 1` and the same event fields.
Firmware and app both play them as-is; the app rewrites them as v2 on save.

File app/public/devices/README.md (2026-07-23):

# Product photos

Drop the keypad product photos here — the app references them by these exact
names (see `MODEL_META` in `src/lib/types.ts`):

- `core6.png` — MKYADA Core 6
- `vision6.png` — MKYADA Vision 6

Square-ish PNGs with a transparent background look best; they are shown at
small sizes (device cards, setup wizard). Until a photo exists, the
`ProductImage` component falls back to the MKYADA logo + model label, so
missing files are harmless.

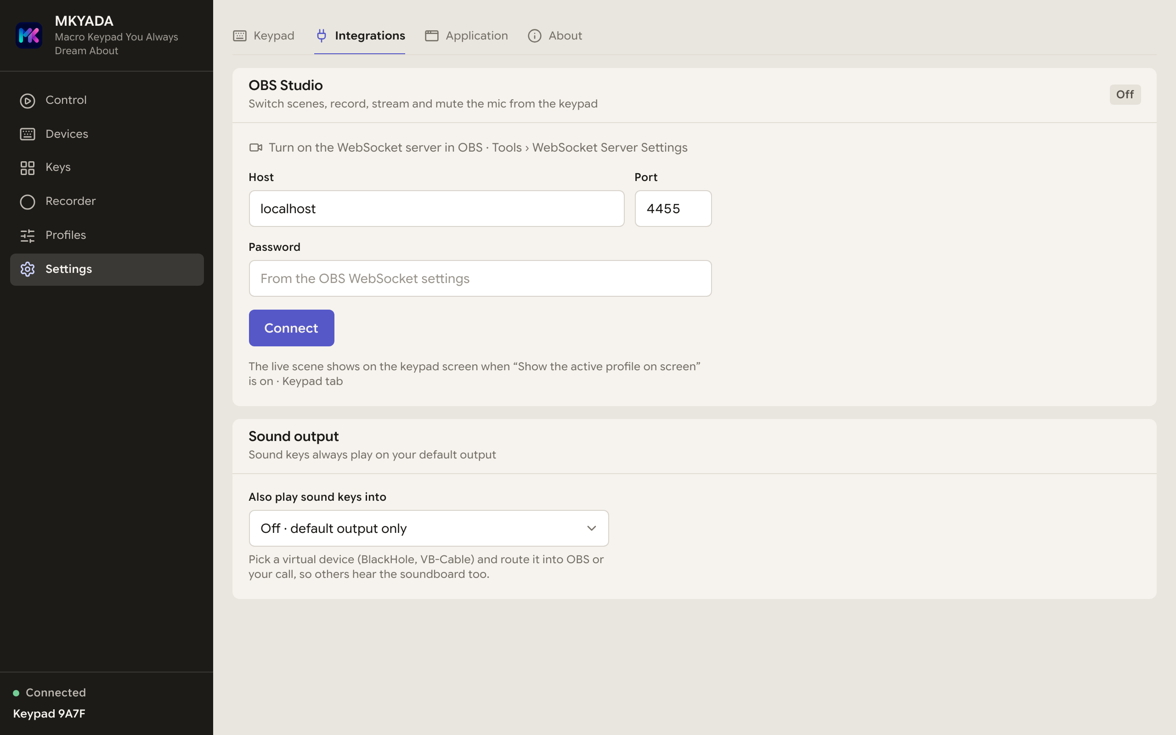
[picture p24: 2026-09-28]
docs/images/screens/vision6-settings-integrations.png

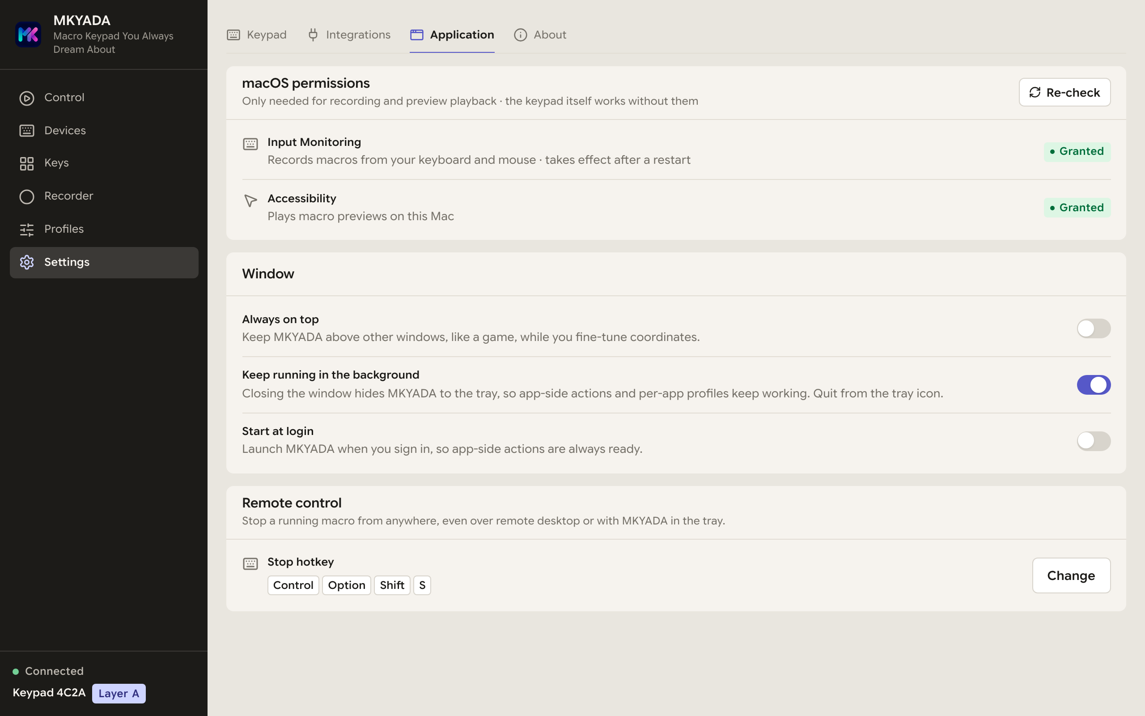
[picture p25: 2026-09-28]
docs/images/screens/core6-settings-app.png

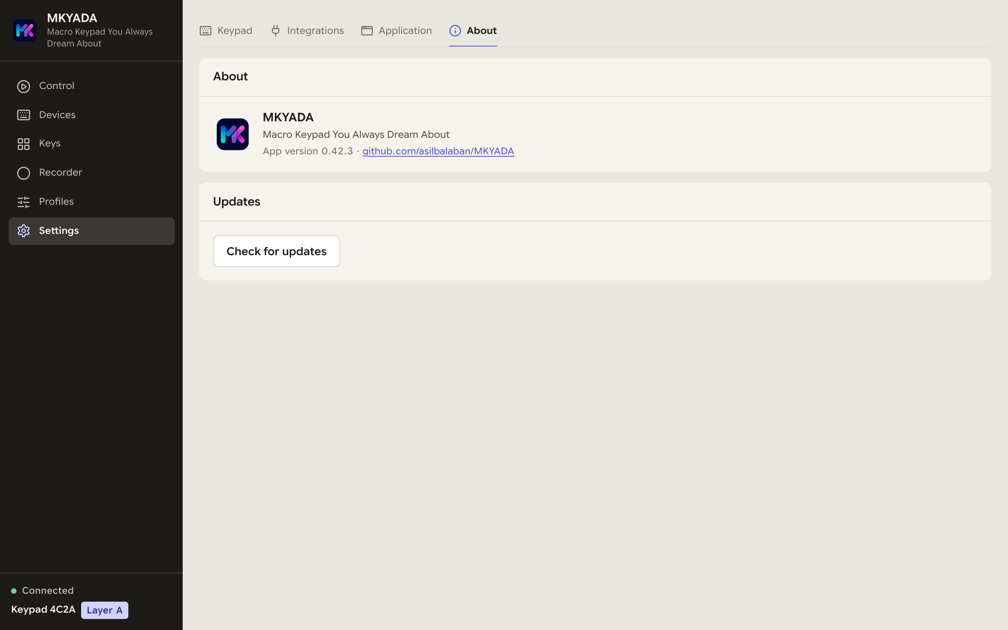
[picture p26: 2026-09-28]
docs/images/screens/core6-settings-about.png

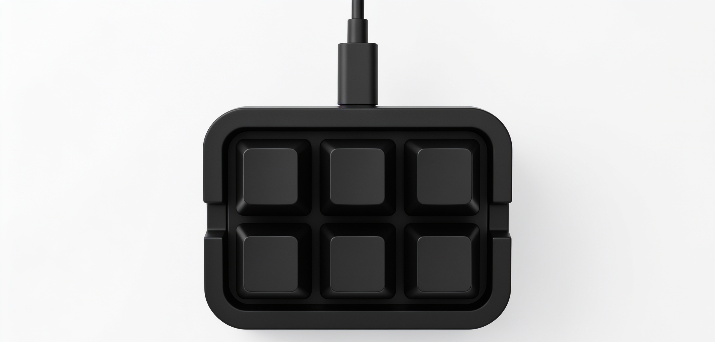
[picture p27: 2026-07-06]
docs/images/2-3x2-wide.png

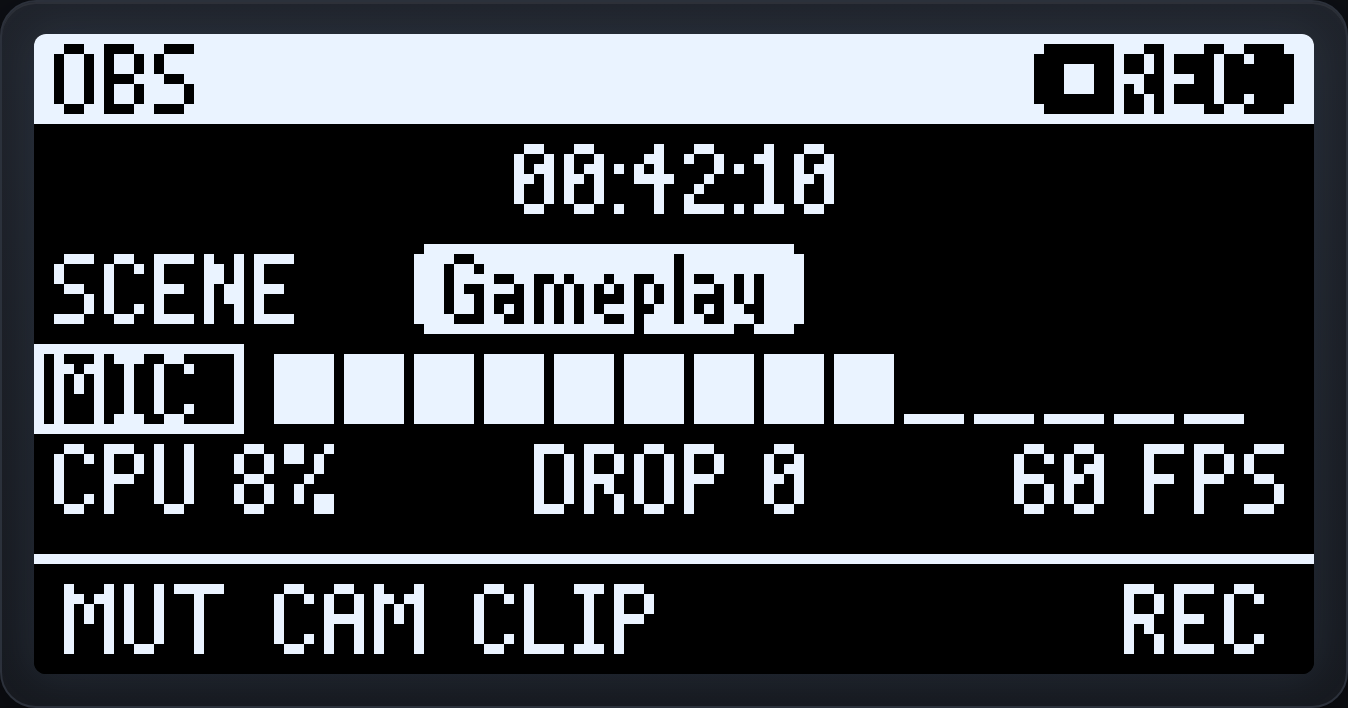
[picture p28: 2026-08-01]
docs/images/oled/obs-center.png

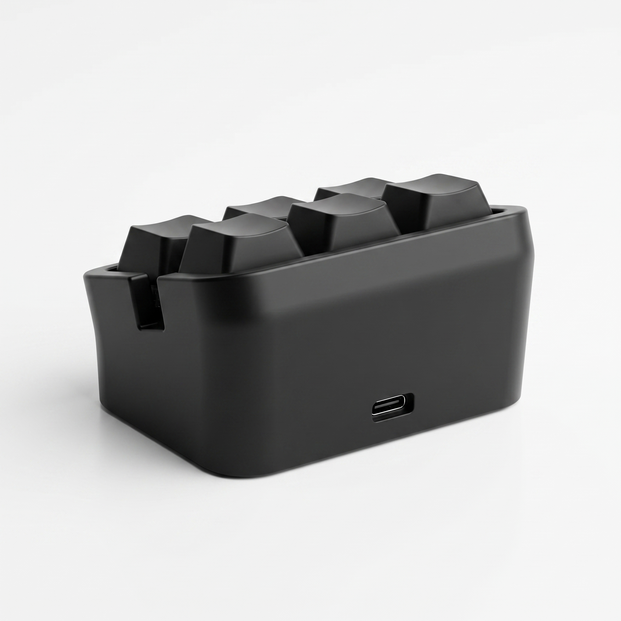
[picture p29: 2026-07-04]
docs/mkyada-backview.png

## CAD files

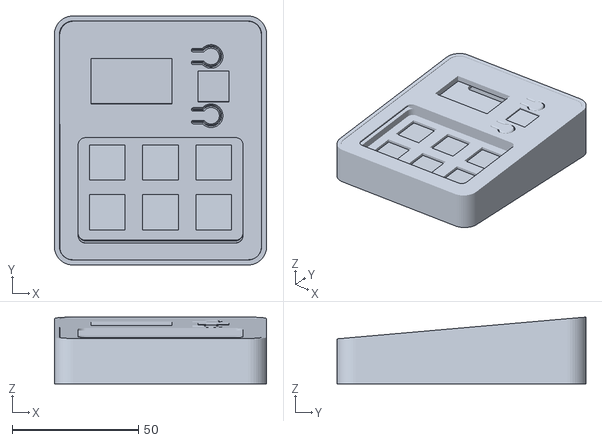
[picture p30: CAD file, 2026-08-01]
docs/models/case.stl
84.3 x 98.8 x 26.5

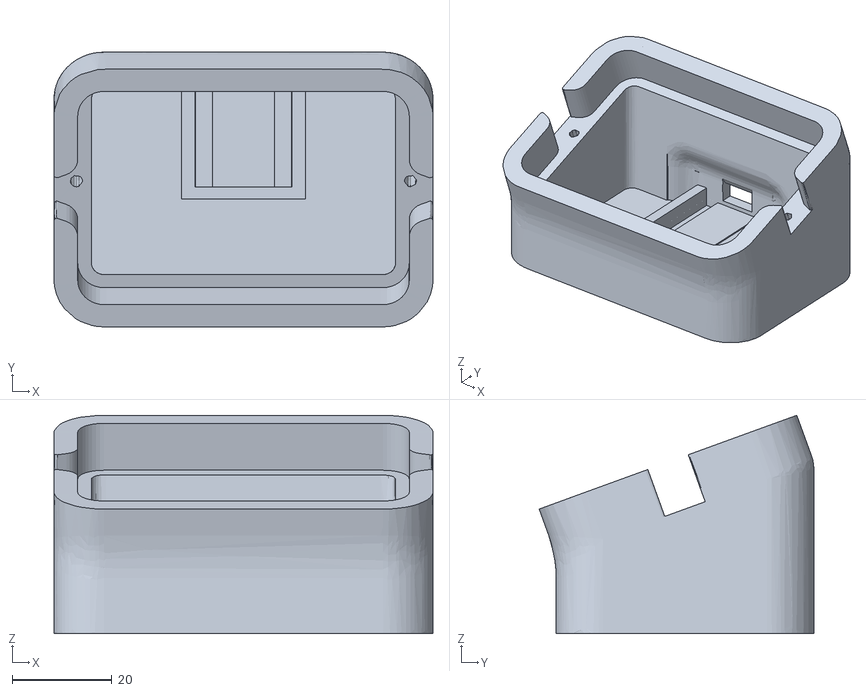
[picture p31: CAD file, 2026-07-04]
hardware/case/Stream Cheap RP2040.stl
76.0 x 55.1 x 43.8

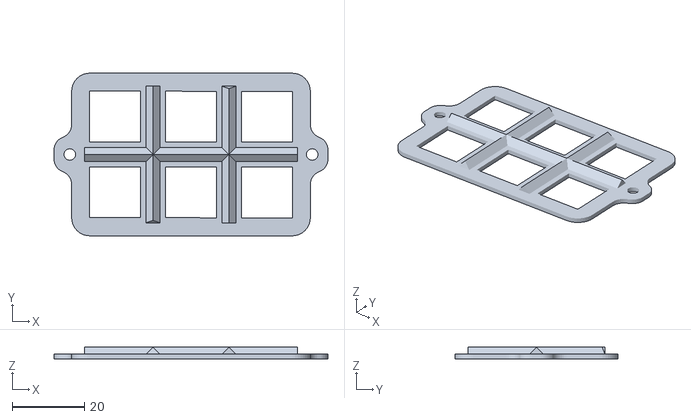
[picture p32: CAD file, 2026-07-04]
hardware/case/FacePlate_3x2.stl
75.8 x 45.0 x 3.18

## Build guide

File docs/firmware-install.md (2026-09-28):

# Firmware installation (RP2040-Zero)

> **Easiest path:** the desktop app can do all of this. Plug a blank board in
> with **BOOT** held and use **Set up a new board** — the app flashes
> CircuitPython, installs the firmware and writes the config for either
> model (Core 6 or Vision 6).

## 1. Flash CircuitPython

1. Download the CircuitPython UF2 for the *Waveshare RP2040-Zero*:
   https://circuitpython.org/board/waveshare_rp2040_zero/
   — **10.2.x recommended** for new installs (required tier for the Vision 6
   display stack; Core 6 also keeps working on 9.x).
2. Hold the **BOOT** button while plugging the board in (or hold BOOT and tap
   RESET). A drive named `RPI-RP2` appears.
3. Copy the `.uf2` file onto `RPI-RP2`. The board reboots and a `CIRCUITPY`
   drive appears.

## 2. Install MKYADA firmware

Download `mkyada-firmware-<version>.zip` from the
[latest release](https://github.com/asilbalaban/MKYADA/releases/latest) and copy
its contents to the root of `CIRCUITPY`:

```
CIRCUITPY/
├── boot.py
├── code.py
├── VERSION
├── config.json          # copy config.example.json and adjust
├── mkyada/              # firmware modules (precompiled .mpy in release zips)
├── lib/                 # neopixel + display libs (in the zip, .mpy)
├── fonts/               # OLED grid fonts (Vision 6; harmless on Core 6)
└── macros/              # your macro JSON files
```

Release zips ship the modules **precompiled to `.mpy`** — the RP2040 then
imports them with a fraction of the RAM an on-device compile needs (compiling
the big modules from source can `MemoryError` on the Vision 6). If you are
installing from the repo instead of a release zip, build the same tree with
`node scripts/build-firmware-dist.mjs` and copy `firmware-dist/` over — or
copy the plain `.py` sources, which work but are less robust. When replacing
`.py` files with `.mpy` (or the other way around) delete the old twin — two
copies of the same module confuse the import path.

**Unplug and replug the board** after the first copy — `boot.py` (USB device
setup) only runs at power-on, and until it has run there is no serial channel
for the app to find the keypad on. (The app's new-board wizard, **Devices → Other keypads → Set up a new board**, does this for
you: it restarts the board over the CircuitPython REPL as its last step.)

## 3. Configure

Edit `config.json` (see `config.example.json`):

| Field | Meaning |
|---|---|
| `model` | `"core6"` (screenless, default) or `"vision6"` (OLED + encoder). A config-less board auto-detects the OLED once at boot |
| `key_count` | How many keys you soldered (1–6, GP0…GP5) |
| `pins` | Explicit per-key GPIO names when a key is soldered off the default order, e.g. `["GP29","GP28","GP27","GP26","GP15","GP13"]`. `null` = model default. Easiest set via the app: **Devices → Fix wiring → Choose pins** |
| `layer_key` | Key number that switches layers, or `null`. Always `null` on Vision 6 (layers are picked with the wheel) |
| `layer_count` | Number of layers — Core 6: 2–8 when `layer_key` is set; Vision 6: 1–8 |
| `layer_mode` | `"toggle"` (press cycles A→B→…) or `"hold"` (hold = layer B) |
| `key_map` | Fixes a mismatched solder order: logical key number per GPIO, e.g. `[3, 1, 2]` = GP0 acts as key 3. `null` = GP0 is key 1. Easiest set via the app: **Devices → Fix wiring → Fix order** |
| `screen` | Default target resolution for mouse macros |

Then drop macro files into `macros/` (`key1.json`, `key1-b.json`, …) — see
[macro-format.md](macro-format.md) — or let the desktop app do all of this.

## 4. LED states

| Color | Meaning |
|---|---|
| Green / blue / purple (dim) | Idle, layer A / B / C |
| Amber solid | Macro playing |
| Amber blinking | Looping macro (press the key again to stop) |
| Breathing tint | Host mode (desktop app connected) |
| Red triple-blink | Config or macro file error |

## Wiring

Core 6: six switches between **GP0…GP5** and **GND** (common ground). Internal
pull-ups are used; no resistors needed. See
[hardware/wiring.md](../hardware/wiring.md).

Vision 6 (OLED + encoder): see [vision6.md](vision6.md).

## If something goes wrong (recovery)

The firmware is layered so that no software failure leaves a dead keypad —
important for sealed/soldered builds where the BOOT button is unreachable:

1. **A hung firmware** trips the hardware **watchdog** (8 s) and the board
   hard-resets itself clean (`config.json "watchdog": false` disables it for
   bench debugging).
2. **A crashed firmware** (broken file after an interrupted update, missing
   library) drops into the **rescue console**: the LED blinks red, the board
   still answers `identify` over serial (`mode:"rescue"`), and the desktop
   app shows a one-click **Repair firmware** that rewrites every firmware
   file and reboots. Macros and config are untouched.
3. **Hidden drive, no app?** Hold **key 1** while plugging in — the CIRCUITPY
   drive comes back for that session and you can copy files by hand (**GP0**
   on Core 6, **GP29** — macro key 1 — on Vision 6).
4. **Reflashing CircuitPython itself** no longer needs the BOOT button: the
   app (or any serial terminal) can send `{"t":"bootloader"}` and the board
   reboots as the `RPI-RP2` UF2 drive.

During app-driven updates the keypad locks itself (keys and menus off, a
progress bar on the Vision 6 screen), every file is CRC-verified after
landing, and `VERSION` is written last — an interrupted update simply shows
the update banner again and can be re-run.

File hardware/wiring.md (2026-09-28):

# Wiring & soldering guide

How to solder a MKYADA keypad: **every switch shares one common GND**, and the
switches connect to **GP0, GP1, GP2… in key order**. That's the whole circuit —
no diodes, no resistors, no matrix. The reference build is 6 keys, but the
firmware supports **any count up to 20** — one key per castellated GPIO on the
board's edge.

> This walkthrough is for the **Core 6** (screenless). Building the **Vision 6**
> (OLED + encoder)? The screen and wheel take GP0–GP6, so the macro keys move to
> the left edge — jump to [Vision 6 (screen model)](#vision-6-screen-model) below.

## Parts

- 1 × Waveshare **RP2040-Zero** (USB-C)
- 1–20 × mechanical switches (Cherry MX or compatible) — 6 is the reference build
- Thin stranded wire (~24–28 AWG), solder, flux
- USB-C **data** cable (some charge-only cables won't enumerate)
- 3D-printed case — STLs and print notes in [case/](case/) (a Stream Cheap
  remix; credits in [case/README.md](case/README.md))

## Know your board

<p align="center">
  Waveshare RP2040-Zero pinout — GP0–GP8 down the right edge, GND on the upper left
</p>

Hold the board **USB-C connector up, component side facing you**:

```
              ┌───[ USB-C ]───┐
        5V ──│●              ●│── GP0   ← Key 1
       GND ──│●              ●│── GP1   ← Key 2   ★ common ground
       3V3 ──│●              ●│── GP2   ← Key 3
      GP29 ──│●              ●│── GP3   ← Key 4
      GP28 ──│●   RP2040-    ●│── GP4   ← Key 5
      GP27 ──│●     Zero     ●│── GP5   ← Key 6
      GP26 ──│●              ●│── GP6
      GP15 ──│●              ●│── GP7
             │●● ● ● ● ● ● ●●│
              GP14 … GP9   GP8
```

- Key pins follow the board's perimeter: **GP0…GP8 down the right edge**,
  GP9…GP14 along the bottom, then GP15 and GP26…GP29 up the left — 20 usable
  key pins in total. A 6-key build uses just the top six on the right
  (GP0…GP5).
- **GND is the second pad from the top on the left edge** (between 5V and 3V3).
- The onboard WS2812 RGB LED (GP16) is the status light — nothing to wire.
- BOOT/RESET buttons are on the face; you'll use BOOT once when flashing
  CircuitPython ([docs/firmware-install.md](../docs/firmware-install.md)).

## Wiring plan

Each switch has two legs. Which leg goes where doesn't matter — a switch is
just a contact:

```
 Key 1 ──── GP0 ┐
 Key 2 ──── GP1 │
 Key 3 ──── GP2 │        RP2040-Zero
 Key 4 ──── GP3 │
 Key 5 ──── GP4 │
 Key 6 ──── GP5 ┘
 All keys ─ GND (one shared wire)
```

- Key numbering follows the GPIO order: **GP0 = key 1, GP1 = key 2, …**
  Decide now which physical position is "key 1" (top-left is the convention).
- No pull-ups or diodes: the firmware enables internal pull-ups, so a pressed
  key simply shorts its GPIO to GND.
- Any key count from 1 to 20 works: solder GP0…GP(n-1) — keys 7+ continue past
  GP5 onto GP6, GP7, GP8 and around the board — then set the count in the
  app (**Devices → Setup → Change setup**). (GP16 is skipped: it drives the onboard LED.)

## Soldering, step by step

1. **Plan the layout.** Seat the switches in the case/plate first and decide
   the key order. Cut wires to length with a little slack.
2. **Daisy-chain the ground.** Take one leg of every switch and connect them
   all in a chain with a single wire (strip small gaps in one wire, or bridge
   leg-to-leg). Run the end of the chain to the board's **GND** pad
   (left edge, 2nd from top).
3. **Wire the signals.** The remaining leg of each switch gets its own wire to
   its GPIO: key 1 → GP0, key 2 → GP1, … key 6 → GP5. Tin the pad and the wire
   first; the pads are small, so a fine tip and flux help.
4. **Check for bridges.** The right-edge pads sit close together — inspect
   GP0…GP5 for solder bridges between neighbours. A multimeter in continuity
   mode: every switch should beep between its GPIO and GND **only while
   pressed**, and never beep between two GPIOs.
5. **Strain relief.** A dab of hot glue over the pads saves the joints when a
   wire gets tugged.

## Verify — no multimeter needed

Flash the firmware ([docs/firmware-install.md](../docs/firmware-install.md)),
open the MKYADA app and go to **Devices → Test keys**: the **live key test** lights up every
key as you press it. If a key doesn't react, reflow its GPIO joint and the
ground chain.

**Soldered the keys in the wrong order?** Don't reach for the iron — the app
fixes it in software: **Devices → Fix wiring → Fix order**, press the keys in the
order they *should* be numbered, done. The remap is stored on the keypad, so
standalone mode uses it too.

---

## Vision 6 (screen model)

The Vision 6 adds an **SH1106 128×64 OLED** and an **EC11 rotary encoder** with
**BACK/CONFIRM** buttons. Same board, same "everything shares one GND, internal
pull-ups, no diodes/resistors" rule as the Core 6 — but the screen and wheel
occupy **GP0–GP6**, so the six macro keys move to **GP29, GP28, GP27, GP26,
GP15, GP14** (down the left edge, then the bottom-left).

> ⚠️ The OLED is **3.3 V only** — wire its VCC to **3V3**, never 5V.

```
              ┌───[ USB-C ]───┐
        5V ──│●              ●│── GP0   ← OLED SDA
       GND ──│●              ●│── GP1   ← OLED SCL     ★ common ground
       3V3 ──│●              ●│── GP2   ← Encoder A (TRA)
      GP29 ──│●              ●│── GP3   ← Encoder B (TRB)
   Key 1    │●   RP2040-    ●│── GP4   ← Encoder push (PSH)
      GP28 ──│●     Zero     ●│── GP5   ← BACK
   Key 2    │●              ●│── GP6   ← CONFIRM
      GP27 ──│●              ●│── GP7
   Key 3    │●● ● ● ● ● ● ●●│
              GP14 … GP9   GP8
      (GP16 = onboard RGB LED)
```

| RP2040-Zero pin | Connects to | Notes |
|---|---|---|
| **GP0** | OLED **SDA** | I²C 0x3C @ 400 kHz |
| **GP1** | OLED **SCL** | |
| OLED **VCC** | **3V3** | ⚠️ 3.3 V only, never 5V |
| OLED **GND** | **GND** | shared ground |
| **GP2** | Encoder **A** (TRA) | |
| **GP3** | Encoder **B** (TRB) | encoder common leg → GND |
| **GP4** | Encoder **push** (PSH) | switch → GND |
| **GP5** | **BACK** button | switch → GND |
| **GP6** | **CONFIRM** button | switch → GND |
| **GP29** | Macro **key 1** | also the **recovery key** — hold while plugging in to un-hide the USB drive |
| **GP28** | Macro **key 2** | |
| **GP27** | Macro **key 3** | |
| **GP26** | Macro **key 4** | |
| **GP15** | Macro **key 5** | |
| **GP14** | Macro **key 6** | |
| GP16 | onboard WS2812 RGB LED | nothing to wire |

Everything with a `→ GND` leg (the six keys, the encoder push, BACK, CONFIRM
and the encoder's common pin) joins the **same daisy-chained ground** as on the
Core 6. Solder order: ground chain first, then the OLED (VCC→3V3, SDA→GP0,
SCL→GP1), then the encoder/buttons, then the six keys. A key soldered to a
different GPIO is fine — remap it in **Devices → Fix wiring → Choose pins**.

Full pinout, the on-device screens, and the bring-up reference:
[docs/vision6.md](../docs/vision6.md) ·
[oled-bringup/SCHEMATIC.md](oled-bringup/SCHEMATIC.md).

---

## Türkçe özet

Devre çok basit: **her tuşun bir bacağı ortak GND'ye** (tek zincir hâlinde),
**diğer bacağı sırasıyla GP0, GP1, GP2…'ye** lehimlenir. 6 tuş referans tasarım;
firmware kartın kenarındaki 20 GPIO'ya kadar her sayıyı destekler (GP16 hariç —
o LED'in). GND pad'i USB üstteyken sol
kenarda üstten ikinci; GP0–GP5 sağ kenarda üstten ilk altı pad. Direnç/diyot
gerekmez (firmware dahili pull-up kullanır). Lehim sonrası uygulamadaki
**Devices → Test keys** (canlı tuş testi) ile her tuşu doğrula; tuşları yanlış sırayla
lehimlediysen **Devices → Fix wiring → Fix order** ile yazılımdan düzelt — yeniden
lehim gerekmez.

**Ekranlı model (Vision 6):** OLED (SH1106) + EC11 encoder + BACK/CONFIRM
eklenir; ekran ve tekerlek **GP0–GP6**'yı kullandığından altı makro tuşu
**GP29, GP28, GP27, GP26, GP15, GP14**'e kayar. ⚠️ OLED **yalnızca 3.3V** — VCC'yi
`3V3`'e bağla, `5V`'a asla. Ortak GND, dahili pull-up, diyot/direnç yok kuralı
aynı. Ayrıntılı pinout ve şema: yukarıdaki
[Vision 6 (screen model)](#vision-6-screen-model) bölümü ·
[docs/vision6.md](../docs/vision6.md) ·
[oled-bringup/SCHEMATIC.md](oled-bringup/SCHEMATIC.md).

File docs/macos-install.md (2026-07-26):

# macOS installation

## Install

1. Download `MKYADA_<version>_universal.dmg` from the
   [latest release](https://github.com/asilbalaban/MKYADA/releases/latest)
   (one build for both Intel and Apple Silicon).
2. Open the DMG and drag **MKYADA** into **Applications**.

## First launch (unsigned app)

The app is not notarized with Apple (no paid developer certificate), so on
first launch macOS shows *"Apple could not verify MKYADA is free of malware"*
with only **Move to Trash / Done** buttons. Don't move it to trash — pick one
of these instead:

- Click **Done**, then open **System Settings → Privacy & Security**, scroll
  down to *"MKYADA was blocked…"* and click **Open Anyway** (recent macOS
  versions removed the old right-click → Open shortcut), **or**
- clear the quarantine flag once in Terminal:

  ```sh
  xattr -cr /Applications/MKYADA.app
  ```

## Permissions

The app guides you through this on first launch (a banner appears until
everything is set; full status lives in **Settings → Application → macOS permissions** with
one-click buttons into System Settings):

| Permission | Needed for | Where |
|---|---|---|
| **Input Monitoring** | Recording macros (global keyboard/mouse capture) | System Settings → Privacy & Security → Input Monitoring |
| **Accessibility** | Local preview playback on this Mac | System Settings → Privacy & Security → Accessibility |
| Removable volume access | Writing configs/macros to the CIRCUITPY drive — macOS asks by itself on first write; click **Allow** | (automatic prompt) |

Notes:

- **No permissions are needed** to configure the keypad or to play macros
  through the device — hardware HID playback comes from the board itself.
- After flipping a toggle in System Settings, quit and reopen MKYADA if the
  status doesn't turn green by itself.

### Permission shows "on" but the app still says DENIED

Builds before **v0.4.2** weren't properly ad-hoc signed at the `.app` bundle
level — CI shipped whatever ad-hoc signature the Rust linker slapped on the
raw executable, which carries a different, unstable identifier on every
single build and never binds `Info.plist`. macOS ties Accessibility/Input
Monitoring grants to that identifier, so it could never survive an update —
toggling the permission on did nothing. From v0.4.2 onward the release build
explicitly signs the whole bundle (`signingIdentity: "-"` in
`tauri.conf.json`), which gives it the stable identifier `com.mkyada.app`
every time, so a grant made once keeps working across updates.

If you're on v0.4.2+ and still see DENIED after granting, reset once and
re-grant, in Terminal:

```sh
tccutil reset Accessibility com.mkyada.app
tccutil reset ListenEvent com.mkyada.app   # this is the Input Monitoring service
```

Then restart MKYADA and grant both permissions again when it asks. If
`tccutil` isn't available or the fix doesn't take, do it by hand instead:

1. System Settings → Privacy & Security → **Input Monitoring** (and
   **Accessibility**),
2. select **MKYADA** in the list and **remove it with the “−” button**
   (toggling off/on is often not enough),
3. restart MKYADA and grant again when it asks.

The app detects this situation and shows the same steps with a red banner.

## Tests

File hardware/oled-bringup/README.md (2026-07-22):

# OLED + Encoder bring-up (RP2040-Zero)

MKYADA'ya menü arayüzü modülü (SH1106 OLED + EC11 encoder + 2 buton) eklemeden önce
donanımı breadboard'da doğrulamak için test araçları.

## Donanım

- **Kart:** Waveshare RP2040-Zero, CircuitPython 10.2.x
- **Modül:** SH1106 1.3" OLED (128x64, I2C 0x3C), EC11 encoder, BACK/CONFIRM butonlar
- **Güç:** modül SADECE 3.3V. RP2040'ın `3V3` pini kullanılır, `5V` **kullanılmaz**.

### Tam bağlantı tablosu — ekranlı model

Bağlantı sırası **kodla birebir** ([device/demo_h.py](device/demo_h.py)). Her buton/tuşun
bir bacağı ilgili GP pinine, diğer bacağı **ortak GND**'ye gider (dahili pull-up,
harici direnç yok). Ayrı bir şema: [SCHEMATIC.md](SCHEMATIC.md).

**OLED (SH1106, I2C 0x3C @ 400 kHz)**

| Modül | RP2040-Zero | Not |
|---|---|-----|
| VCC | 3V3 | ⚠️ SADECE 3.3V, `5V` kullanma |
| GND | GND | |
| SDA | GP0 | I2C data |
| SCL | GP1 | I2C clock |

**Encoder + navigasyon butonları**

| Modül | İşlev | RP2040-Zero | Kod indexi |
|---|---|---|---|
| TRA | Encoder faz A  | GP2 | — |
| TRB | Encoder faz B  | GP3 | — |
| PSH | Encoder butonu | GP4 | `K_PSH` = 0 |
| BAK | BACK | GP5 | `K_BACK` = 1 |
| CON | CONFIRM | GP6 | `K_CONFIRM` = 2 |

**Makro tuşları** — grid gözesi = pin sırası. Yanlış sırada lehimlersen ekrandaki göze
ile fiziksel tuş eşleşmez. `MACRO_PINS` tuple sırası:

| Makro tuş | RP2040-Zero | `key_number` |
|---|---|---|
| Tuş 1 | GP29 | 0 |
| Tuş 2 | GP28 | 1 |
| Tuş 3 | GP27 | 2 |
| Tuş 4 | GP26 | 3 |
| Tuş 5 | GP15 | 4 |
| Tuş 6 | GP14 | 5 |

**RGB LED:** onboard WS2812 (`board.NEOPIXEL`), yoksa GP16 — ayrı kablo gerekmez.

## Kullanım

Kart normal modda (CIRCUITPY diski görünür) takılıyken host'tan:

```bash
python3 hardware/oled-bringup/bringup.py diag     # canli hat teshisi (SDA/SCL OK mu)
python3 hardware/oled-bringup/bringup.py scan     # I2C tarama -> 0x3c bekleniyor
python3 hardware/oled-bringup/bringup.py oled     # ekrana MKYADA + cerceve
python3 hardware/oled-bringup/bringup.py inputs   # encoder + buton + nvm testi
python3 hardware/oled-bringup/bringup.py demo     # tam OLED menu demosu
python3 hardware/oled-bringup/bringup.py monitor  # sadece seri ciktiyi izle
```

Encoder/PSH iç pull-up ile okunur; BACK/CONFIRM modülde 4.7K pull-up'lı (kodda iç
pull-up da açık, paralel — sorun değil). Ayarlar `microcontroller.nvm`'e yazılır,
karta güç gitmese de kalır.

Runner seçtiğin testi `device/*.py` içinden `CIRCUITPY/code.py`'ye kopyalar ve seri
çıktıyı canlı akıtır. Çıkmak için `Ctrl-C`. Ekstra pip paketi gerektirmez (stdlib).

## Kart tarafı kütüphaneler (`oled` testi için)

`CIRCUITPY/lib/` içine (Adafruit CircuitPython Bundle 10.x'ten):

- `adafruit_displayio_sh1106.mpy`
- `adafruit_display_text/`

(`i2cdisplaybus`, `displayio`, `terminalio` CircuitPython 10 çekirdeğinde, ayrı dosya gerekmez.)

`demoh` (yatay demo) grid yazıları için ek olarak küçük (dar) bir bitmap font kullanır:

- `CIRCUITPY/lib/adafruit_bitmap_font/` → repo'daki `lib/adafruit_bitmap_font/` (tüm `.py`'ler; `lvfontbin.py` dahil şart)
- `CIRCUITPY/fonts/spleen-5x8.bdf` → repo'daki `fonts/spleen-5x8.bdf`

Font/lib yoksa demo hata vermez, terminalio (6px) fontuna düşer. `fonts/4x6.bdf` daha da dar bir alternatiftir.

## Sık karşılaşılan hata

`RuntimeError: No pull up found on SDA or SCL` → I2C hattı fiziksel sorun. Önce `diag`
çalıştır: SDA ve SCL ikisi de sabit `OK` olmalı. Bir tanesi `YOK` ya da titriyorsa o
telin teması kötü (jumper'ı değiştir / pad'e tam otur / lehimi kontrol et).

## Aşamalar

1. ✅ CircuitPython kurulumu
2. ✅ I2C tarama (0x3c)
3. ✅ OLED'e görüntü (colstart=2)
4. ✅ Encoder + buton + NVM menü demosu (`demo`)

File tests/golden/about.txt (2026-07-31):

################################################################################################################################
###..##...###..##.##.#.....#####################################################################################################
##.##.#.##.#.##.#.##.###.#######################################################################################################
##.##.#.##.#.##.#.##.###.#######################################################################################################
##....#...##.##.#.##.###.#######################################################################################################
##.##.#.##.#.##.#.##.###.#######################################################################################################
##.##.#.##.#.##.#.##.###.#######################################################################################################
##.##.#...###..###..####.#######################################################################################################
################################################################################################################################
................................................................................................................................
................................................................................................................................
................................................................................................................................
................................................................................................................................
...#...#.......#.....#...................................................................................#.....#..........##....
...##.##.......#.....#...................................................................................................#..#...
...#.#.#..#...##..#..#...............................................................................#.#.#..##.#..#..##..#......
...#.#.#.#.#.#.#.#.#.#...............................................................................#.#.#.#...#.#.#.#.#.###....
...#...#.#.#.#.#.###.#...............................................................................#.#.#..#..#.#.#.#.#.#..#...
...#...#.#.#.#.#.#...#...............................................................................#.#.#...#.#.#.#.#.#.#..#...
...#...#..#...##..##.#................................................................................#..#.##..#..#..#.#..##....
................................................................................................................................
................................................................................................................................
................................................................................................................................
...####.#...............................................................................................##.....##..####....#....
...#...................................................................................................#..#...#..#....#...##....
...#....#.#.#.##.#..#...#.##..#.#..#...................................................................#.##......#...#.....#....
...###..#.##..#.#.#.#...#...#.##..#.#..................................................................##.#.....#...##.....#....
...#....#.#...#.#.#.#.#.#.###.#...###..................................................................#..#....#......#....#....
...#....#.#...#.#.#.##.##.#.#.#...#....................................................................#..#...#....#..#....#....
...#....#.#...#.#.#.#...#..##.#....##...................................................................##..#.####..##..#.###...
................................................................................................................................
................................................................................................................................
................................................................................................................................
...###..........#............###.###...............................####..##..####.####.####..##...##...##..####..##..#....##....
...#..#.......................#..#..#..............................#....#..#....#.#....#....#..#.#..#.#..#....#.#..#.#...#..#...
...#..#..#..#.#.#..##..#......#..#..#..............................###..#.##...#..###..###..#..#.#....#.##...#.....#.##..#..#...
...#..#.#.#.#.#.#.#...#.#.....#..#..#.................................#.##.#..##.....#....#..##..###..##.#...#....#..#.#..###...
...#..#.###.#.#.#.#...###.....#..#..#.................................#.#..#....#....#....#.#..#.#..#.#..#..#....#...#.#....#...
...#..#.#...#.#.#.#...#.......#..#..#..............................#..#.#..#.#..#.#..#.#..#.#..#.#..#.#..#..#...#....#.#.#..#...
...###...##..#..#..##..##....###.###................................##...##...##...##...##...##...##...##...#...####.##...##....
................................................................................................................................
................................................................................................................................
................................................................................................................................
................................................................................................................................
................................................................................................................................
................................................................................................................................
................................................................................................................................
................................................................................................................................
................................................................................................................................
................................................................................................................................
................................................................................................................................
................................................................................................................................
................................................................................................................................
................................................................................................................................
................................................................................................................................
................................................................................................................................
................................................................................................................................
................................................................................................................................
................................................................................................................................
................................................................................................................................
................................................................................................................................
................................................................................................................................
................................................................................................................................
................................................................................................................................

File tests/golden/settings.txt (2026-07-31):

................................................................................................................................
.....##.....###.####.#####.#####.###.#..#..##...###.............................................................................
....##.....#....#......#.....#....#..##.#.#..#.#................................................................................
...##......#....#......#.....#....#..##.#.#....#................................................................................
..##........##..###....#.....#....#..#.##.#.##..##..............................................................................
...##.........#.#......#.....#....#..#.##.#..#....#.............................................................................
....##........#.#......#.....#....#..#..#.#..#....#.............................................................................
.....##....###..####...#.....#...###.#..#..###.###..............................................................................
................................................................................................................................
################################################################################################################################
................................................................................................................................
.............................................................................................................................###
.............................................................................................................................###
.............................................................................................................................###
.............................................................................................................................###
.....##.......#..................#..........................................................................#...##...........###
....#..#......#..................#.........................................................................##..#..#..........###
....#..#.#.#.###..#.....#.#..#..###.#.#.#.#.##..............................................................#..#.##..##......###
....####.#.#..#..#.#....##..#.#..#..#.#.##..#.#.............................................................#..##.#.#........###
....#..#.#.#..#..#.#....#...###..#..#.#.#...#.#.............................................................#..#..#..#.......###
....#..#.#.#..#..#.#....#...#....#..#.#.#...#.#.............................................................#..#..#...#......###
....#..#..##...#..#.....#....##...#..##.#...#.#............................................................###..##..##.......###
.............................................................................................................................###
.............................................................................................................................###
.............................................................................................................................###
############################################################################################################################.###
############################################################################################################################.###
############################################################################################################################.###
####.##########################################################################################....#########.#.#####.#######.###
####.##########################################################################################.############.#######.#######.###
####.####..##..###..#.#.#..###..##.############################################################.####..###..#.#.##..#..######.###
####.######.#.#.#.#.#.#.###.#.#.#.#.###########################################################...##.#.#.#.#.#.#.###.#.#####.###
####.####...#.#.#.#.#.#.#...#.#.#...###########################################################.####.#.#.#.#.#.##.##.#.#####.###
####.####.#.#.#.##..#.#.#.#.##..#.#############################################################.####.#.##..#.#.###.#.#.#####.###
####....##..#.#.###.##..##..###.##..###########################################################....#.#.###.#.#.#..##.#.#####.###
#################..##########..#########################################################################..##################.###
############################################################################################################################.###
..............................................................................................................................#.
................................................................................................................................
..............................................................................................................................#.
........................................................................................................###############.........
....#.......................#.............#............................................................#################......#.
....#.......................#.............#............................................................##########.....##........
....#....##..#.#..#..#.#....##..##..##...##............................................................##########.....##......#.
....#......#.#.#.#.#.##.....#.#...#.#.#.#.#............................................................##########.....##........
....#....###.#.#.###.#......#.#.###.#.#.#.#............................................................##########.....##......#.
....#....#.#..##.#...#......#.#.#.#.#.#.#.#............................................................#################........
....####..##...#..##.#......##...##.#.#..##.............................................................###############.......#.
.............##.................................................................................................................
..............................................................................................................................#.
................................................................................................................................
..............................................................................................................................#.
................................................................................................................................
........................................................................................................###############.......#.
....###............#.#.#........#.............#........................................................#...............#........
....#..#..........#....#........#.............#........................................................#..#####........#......#.
....#..#.#.#..#..###.#.#..#.....##..##..##...##........................................................#..#####........#........
....###..##..#.#..#..#.#.#.#....#.#...#.#.#.#.#........................................................#..#####........#......#.
....#....#...#.#..#..#.#.###....#.#.###.#.#.#.#........................................................#..#####........#........
....#....#...#.#..#..#.#.#......#.#.#.#.#.#.#.#........................................................#...............#......#.
....#....#....#...#..#.#..##....##...##.#.#..##.........................................................###############.........
..............................................................................................................................#.
................................................................................................................................
................................................................................................................................

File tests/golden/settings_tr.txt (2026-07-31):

................................................................................................................................
.....##.....##..#...#..##..###..#.....##..###...................................................................................
....##.....#..#.#...#.#..#.#..#.#....#..#.#..#..................................................................................
...##......#..#..#.#..#..#.#..#.#....#..#.#..#..................................................................................
..##.......####...#...####.###..#....####.###...................................................................................
...##......#..#...#...#..#.#.#..#....#..#.#.#...................................................................................
....##.....#..#...#...#..#.#..#.#....#..#.#..#..................................................................................
.....##....#..#...#...#..#.#..#.####.#..#.#..#..................................................................................
................................................................................................................................
################################################################################################################################
................................................................................................................................
.............................................................................................................................###
############################################################################################################################.###
############################################################################################################################.###
############################################################################################################################.###
#####..###.#################.##.#.######...##.#.#####.#.################################################.###..##############.###
####.##.##.#################.####.######.##.###########################################################..##.##.#############.###
####.##.#...##.##..#.##..##...#.#.#.####.##.##.##..##.#.##..############################################.##.#..##..#..######.###
####.##.##.##.#.#.#.#.###.##.##.#..#####.##.#.#.#.#.#.#.#.##############################################.##..#.#.###.#.#####.###
####.##.##.##.#.#.#.#.#...##.##.#..#####.##.#.#.#.#.#.#.##.#############################################.##.##.##.##.#.#####.###
####.##.##.##.#.#.#.#.#.#.##.##.#.#.####.##.#.#.#.#.#.#.###.############################################.##.##.###.#.#.#####.###
#####..####.##.##.#.#.##..###.#.#.#.####...###.##.#.##..#..############################################...##..##..##.#.#####.###
##########################################################.#################################################################.###
############################################################################################################################.###
.............................................................................................................................###
.............................................................................................................................###
.............................................................................................................................###
.............................................................................................................................###
....###..#.#..................................................................................#####.#.#.....#................###
....#..#...#....................................................................................#...........#................###
....#..#.#.#....................................................................................#...#.#.#.#.#.#..##..#.......###
....#..#.#.#....................................................................................#...#.#.##..##..#...#.#......###
....#..#.#.#....................................................................................#...#.#.#...##..#...###......###
....#..#.#.#....................................................................................#...#.#.#...#.#.#...#........###
....###..#.#....................................................................................#....##.#...#.#..##..##......###
.................................................................................................................#...........###
.............................................................................................................................###
.............................................................................................................................###
.............................................................................................................................###
.............................................................................................................................###
........................................................................................................###############......###
....#..#......#...................#.............#......................................................#################.....###
....#.#.......#...................#.............#......................................................##########.....##.....###
....##...##..###.##.#..##..##.....##..##..##...##.#....................................................##########.....##.....###
....##.....#..#..#.#.#...#.#.#....#.#...#.#.#.#.#.#....................................................##########.....##.....###
....#.#..###..#..#.#.#.###.#.#....#.#.###.#.#.#.#.#....................................................##########.....##.....###
....#..#.#.#..#..#.#.#.#.#.#.#....#.#.#.#.#.#.#.#.#....................................................#################.....###
....#..#..##...#.#.#.#..##.#.#....##...##.#.#..##.#.....................................................###############......###
.............................................................................................................................###
.............................................................................................................................###
.............................................................................................................................###
.............................................................................................................................###
.............................................................................................................................###
........................................................................................................###############......###
....###............#.#.#....#.............#............................................................#...............#.....###
....#..#..........#....#....#.............#............................................................#..#####........#.....###
....#..#.#.#..#..###.#.#....##..##..##...##.#..........................................................#..#####........#.....###
....###..##..#.#..#..#.#....#.#...#.#.#.#.#.#..........................................................#..#####........#.....###
....#....#...#.#..#..#.#....#.#.###.#.#.#.#.#..........................................................#..#####........#.....###
....#....#...#.#..#..#.#....#.#.#.#.#.#.#.#.#..........................................................#...............#.....###
....#....#....#...#..#.#....##...##.#.#..##.#...........................................................###############......###
.............................................................................................................................###
.............................................................................................................................###
................................................................................................................................

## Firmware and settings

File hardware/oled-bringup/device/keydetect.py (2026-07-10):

# MKYADA bring-up - tus pini DEDEKTORU
# Hangi GPIO'ya bagli oldugunu bilmiyoruz: bos pinlerin hepsini tarar,
# basilan tusun pinini (GPxx) OLED'de ve seri portta gosterir.
# (Tuslar ortak GND'ye bagli varsayilir; ic pull-up ile okunur.)

import time
import board
import busio
import displayio
import i2cdisplaybus
import terminalio
import keypad
from adafruit_display_text import label
import adafruit_displayio_sh1106

# OLED (dikey)
displayio.release_displays()
i2c = busio.I2C(scl=board.GP1, sda=board.GP0, frequency=400000)
bus = i2cdisplaybus.I2CDisplayBus(i2c, device_address=0x3C)
disp = adafruit_displayio_sh1106.SH1106(bus, width=128, height=64, colstart=2)
disp.rotation = 90
W = disp.width
H = disp.height
CX = W // 2

# Bos aday pinler (modul GP0-6 ve LED GP16 haric)
CAND = [7, 8, 9, 10, 11, 12, 13, 14, 15, 26, 27, 28, 29]
pins = tuple(getattr(board, "GP%d" % n) for n in CAND)
NAMES = ["GP%d" % n for n in CAND]
keys = keypad.Keys(pins, value_when_pressed=False, pull=True)


def show(big, small=""):
    g = displayio.Group()
    t = label.Label(terminalio.FONT, text=big, scale=2, color=0xFFFFFF)
    t.anchor_point = (0.5, 0.5)
    t.anchored_position = (CX, H // 2 - 8)
    g.append(t)
    if small:
        s = label.Label(terminalio.FONT, text=small, scale=1, color=0xFFFFFF)
        s.anchor_point = (0.5, 0.5)
        s.anchored_position = (CX, H // 2 + 16)
        g.append(s)
    disp.root_group = g


show("bas", "tus pini bul")
print("=== tus dedektoru: her tusa sirayla bas ===")
while True:
    ev = keys.events.get()
    if ev:
        name = NAMES[ev.key_number]
        if ev.pressed:
            show(name, "basildi")
            print("BASILDI:", name)
        else:
            print("birakildi:", name)
    time.sleep(0.005)

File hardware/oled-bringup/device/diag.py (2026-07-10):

# MKYADA OLED bring-up - karta gidecek test: CANLI hat teshisi
# busio KULLANMAZ (patlamaz, LED yanip sonmez). GP0/GP1 hatlarinin
# elektriksel durumunu 0.3sn'de bir okur. Kablo oynatirken izle.

import time
import board
import digitalio

def harici_pullup(pin):
    # Disaridaki (modul) pull-up gorunuyor mu? (ic pull-up KAPALI)
    d = digitalio.DigitalInOut(pin)
    d.direction = digitalio.Direction.INPUT
    d.pull = None
    v = d.value
    d.deinit()
    return v

print("=== CANLI I2C hat teshisi (kabloyu oynat) ===")
onceki = None
while True:
    sda = harici_pullup(board.GP0)
    scl = harici_pullup(board.GP1)
    durum = (sda, scl)
    if durum != onceki:
        print("SDA:", "OK " if sda else "YOK", "| SCL:", "OK " if scl else "YOK",
              "  <-- ikisi de OK olmali")
        onceki = durum
    time.sleep(0.3)

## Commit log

2026-07-04 M1: RP2040-Zero CircuitPython firmware replaces Raspberry Pi stack
    - boot.py: composite USB device — keyboard + absolute mouse (descriptor
    ported from the proven Pi gadget) + consumer control + dual CDC
    - code.py: standalone/host state machine, layer key (toggle & hold),
    loop-until-pressed-again macros, panic stop, 5s host watchdog
    - mkyada/: hidmap tables and playback engine ported from pi/player.py,
    JSON-lines serial protocol, WS2812 status LED
    - docs: macro format v2, serial protocol v1, firmware install, wiring guide
    - verified with a desktop simulation harness (27 checks) stubbing
    CircuitPython modules
    - removes pi/ (Flask webapp, evdev daemon, HID gadget) and test.py
    Co-Auth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
    [boot.py, code.py, engine.py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]
2026-07-04 M2: Tauri v2 desktop app — device management, onboarding, key assignments
    Rust backend: serial discovery by USB product string + identify probe,
    JSON-lines connection streaming device:msg events, CIRCUITPY drive
    discovery matched via boot_out.txt UID, safe file write with fsync,
    GitHub release check (semver).
    React frontend: Devices (scan/connect), Setup wizard (key count, layer
    key toggle/hold, live solder-test pad), Keys page (visual keypad with
    live press highlights, per-layer tabs, assignment editor). Assignments
    — single key, combo, text snippet, media key, imported macro — all
    compile to macro JSON files on the drive ('everything is JSON').
    Firmware fix found on real hardware: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
    [led.py, proto.py]
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2026-07-04 Key remap for mismatched solder order (config.key_map + Setup wizard)
    Firmware: config.json gains key_map — logical key number per GPIO
    (e.g. [3,1,2] when key 1 was soldered to GP2). Applied in on_edge so
    standalone playback, layer key and file naming all use the corrected
    numbers; validated as a permutation, falls back to identity. btn events
    now carry both the logical key and the physical GPIO (phys); hello
    reports the active map. Sim tests cover remap + phys.
    App: Setup's test step gains a 'Key order (remap)' panel — press the
    physical keys in the order they should be numbered and the map is
    written to the device; includes current-map display, reset-to-default,
    and an update hint on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
    [code.py, firmware_sim_test.py]
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2026-07-04 v0.1.6: device nicknames, in-app firmware update, on-screen path overlay, full field editing
    1. Devices can be nicknamed (per-UID, persisted app-side; shown across
    the device UI)
    2. Firmware ships inside the app bundle (tauri resources); Devices page
    compares hello.fw to the bundled version and offers one-click update
    that preserves config/macros, then hard-resets via the new serial
    'reset' command (firmware 0.1.6)
    3. Writing assignments/macros to the device now shows explicit
    success/error dialogs, with a verification read-back on save
    4. Window title shows the app version
    5. Devices page reworked: Connected (pulsing green, rename, fw update) /
    Plugged in (prominent) / Rem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
    [code.py]
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2026-07-04 Playback policies, live layer indicator, multi-select rows, Keypad naming
    User feedback batch (firmware v0.2.2 + app v0.2.4):
    - Removed the broken/unneeded 'hold' layer mode — the layer key always
    cycles A -> B -> ... (config layer_mode kept for compat, ignored)
    - Per-macro settings.on_repress: pressing the macro's key while it plays
    stops it (default) or restarts it; per-macro settings.hold_repeat:
    replay while the key is held (like holding a letter key)
    - config busy_other: another macro key during playback is ignored
    (default) or interrupts and takes over; policies exposed in the Setup
    wizard, AssignmentEditor and MacroEditor; queued via pending_play in
    the firmware main loo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
    [code.py, firmware_sim_test.py]
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2026-07-05 UX batch: playback LED blink, on-device nickname, drive retry, edit-in-recorder
    - fw 0.2.3: status LED blinks amber during any playback (fast; loop = slow)
    - nickname stored on the keypad (devname.json) and synced on connect, so it
    travels between computers; device file wins
    - CIRCUITPY drive is re-scanned every 2s after connect instead of asking for
    an unplug/replug when it mounts late
    - Keys page: "Edit in Recorder" opens a recorded macro in the editor with its
    key/layer preselected in "Put it on a key"
    - Always-on-top moved to Settings > Window and persisted across launches
    - macro playback settings redesigned into an aligned, explained card
    - preview playback: absolute-deadline sch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
    [led.py]
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2026-07-05 v0.3.0: multi actions, tap/double/hold key logic, tray + autostart, live feedback
    Stream Deck parity batch — firmware 0.3.0, serial proto v2, macro format v3.
    - Multi actions (kind "sequence"): chain steps with per-step delays. Pure-HID
    sequences compile into ONE macro file and run fully standalone; mixed
    sequences precompile their HID steps to sibling part files the app plays
    over serial (still hardware HID) while it runs launch/command/sound steps.
    The editor badges honestly which steps need the app.
    - Key logic (format v3): one key does tap / double press / long press.
    Top-level events stay the tap, so old firmware degrades gracefully. The
    firmware resolves the gesture stan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
    [code.py, firmware_sim_test.py, led.py]
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2026-07-06 Full-fidelity device macro playback: drift-free scheduler + v4 stream format
    Recorded mouse paths stuttered on the keypad: playback drifted slower than
    the recording (per-event relative sleeps accumulated engine overhead) and
    every device write was force-thinned to 30 Hz / 3 px RDP to fit the whole
    file in RP2040 RAM.
    Firmware (0.5.0, proto 4):
    - engine.py: absolute-deadline scheduler on supervisor.ticks_ms - per-event
    overhead is absorbed instead of accumulating; should_stop/tick polling is
    throttled to ~20 ms instead of every sleep slice, plus one poll per pass
    so all-zero-delay macros stay stoppable.
    - code.py: v4 stream macro reader - header line + one JSON event per line,
    playe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
    [code.py, engine.py, firmware_sim_test.py]
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2026-07-06 Release v0.9.0 — reliable keypad writes, editor repeat, faster loads
    Serial writes to the keypad collided with macro playback on the
    single-threaded firmware, failing with os error 121 or an 8s timeout.
    Stop playback before every mutating fs op and retry on the transient
    errors a winding-down macro leaves behind; process the whole poll batch
    on stop so a file request isn't dropped alongside it.
    Editor test-play now honors the macro's own Repeat setting instead of a
    separate, easy-to-miss "Times" field that defaulted to 1 and overrode it.
    Keys tab reads every assigned macro over serial; a large recorded macro
    took 15-20s. Quadruple the fs read chunk (2048 -> 8192) to cut ack
    round-trips.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
    [code.py]
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2026-07-11 Add small bitmap font (spleen 5x8) to horizontal demo grid
    Grid cell labels used terminalio (6px), which cut long words. Switch the
    grid to a narrow 5px bitmap font so full labels fit (~8 chars/cell):
    - Load spleen-5x8.bdf via adafruit_bitmap_font, cache used glyphs at boot
    - Fall back to terminalio if the font/lib is missing (no crash)
    - Restore full per-layer labels (upgrade, mikrofon, yapistir, terminal...)
    - Vendor adafruit_bitmap_font lib + fonts/ (spleen-5x8, 4x6 alt) for deploy
    [demo_h.py]
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2026-07-22 firmware: one codebase, two models — Vision 6 (SH1106 + EC11) support
    - mkyada/models.py: model table (core6/vision6), pin orders, reserved pins,
    I2C auto-probe for config-less boards, config "pins" validation for keys
    soldered off the default order, UI_SLOTS virtual slot names
    - mkyada/oled.py: production port of the demo_h.py display layer — branded
    boot screen (no console text, root_group owned from first frame), bounded
    init retries then headless fallback, 3-font grid, generic menu/toast/host/
    error screens, English UI copy
    - mkyada/ui.py: non-blocking menu state machine driven from App.run_loop():
    encoder layer select (1-8 layers; single layer shows just A + SETTINGS),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
    [boot.py, code.py, led.py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]
2026-07-22 app backend + docs + tests for the two-model firmware (0.7.0)
    Rust (Tauri):
    - firmware_update also installs lib/ (recursive), fonts/ and settings.toml,
    with a bytes-capable write path shared by drive and serial-fs transports
    - new provisioning commands: list_bootloader_drives (RPI-RP2 scan via
    INFO_UF2.TXT) and provision_flash_uf2 (bundled CircuitPython 10.2.1 UF2,
    chunked copy tolerant of the reboot mid-write); UF2 shipped as a resource
    Tests: firmware sim coverage for model resolution, pins validation +
    pin_detect, vision6 config coercion (layer_key null, 1-8 layers, key clamp),
    label/speed parsing from stream + legacy files, persist_speed rewrite with
    macro_changed, slot fallback,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
    [firmware_sim_test.py]
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2026-07-22 Device language (en/tr), always-active macro keys, vision6 OOM hardening
    - firmware/mkyada/i18n.py: two-language string table (ASCII-safe Turkish for
    the BDF fonts); config.json "lang" validated in load_config, applied at
    boot before the first screen
    - device Settings menu gains Language; picking one rewrites config.json on
    the device (persist_lang) and announces the fresh config so an open app's
    Setup view follows; the app's Setup gets the same select for vision6 and
    mirrors device-side changes live
    - macro keys now fire on every screen: Keys/Setup no longer hold the keypad
    in host mode — the live-press highlight rides the standalone btn stream
    (proto v2), so the key test sh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
    [code.py, firmware_sim_test.py, i18n.py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]
2026-07-22 Self-heal on fatal errors, survive oversized serial lines, 2KB fs chunks
    - code.py: a fatal exception (e.g. MemoryError under load) now shows the
    branded error screen for 5s and supervisor.reload()s instead of dying —
    no dead keypad, and the CircuitPython console never takes over the OLED
    - proto.py: a serial line that doesn't fit the heap is dropped (sender
    retries) instead of raising MemoryError out of poll()
    - serialfs.rs: fs_write chunks 9216 -> 2048 bytes; the old ~12KB base64
    lines were the exact allocation that MemoryError'd the Vision 6 during
    key-assignment uploads
    [code.py, proto.py]
2026-07-23 Polish round: localized home screen, menu scrolling, name overrides
    Firmware (0.7.2):
    - Home screen SETTINGS label was hardcoded English — now localized (AYARLAR)
    - Settings menu scrolls (3 visible rows + arrows); the 4th item no longer
    overlaps the bottom button bar
    - Home layer letters ~10% smaller (spleen@6 vs terminalio@5) and vertically
    balanced: same air above the letter as between it and the dots
    App (0.12.0):
    - Keys tab: editable "Display name" per assignment — overrides the
    auto-generated macro name shown in the app and on the Vision 6 screen
    - Sidebar chip: "● connected" + device nickname (or "Keypad XXXX") on its
    own line instead of "N-key keypad connected"
    - Remove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
    [firmware_sim_test.py, oled.py]
2026-07-23 Fix Vision 6 memory failures on macro reads + boot straight to grid
    Root cause of the "memory allocation failed" reports: on the screen model
    the app reads macros back over serial in 4 KB chunks, and each chunk's
    transient base64 + JSON buffers need a ~5.5 KB contiguous block the
    display-fragmented RP2040 heap often can't give — so reading a large
    recorded (mouse-path) macro failed. The app then showed that key as
    "not assigned", and the same read backs a speed save's verify step.
    Firmware (0.7.3):
    - fs_read chunk 4096 -> 1024 on display models; gc.collect() between
    chunks and at fs op entry so the heap stays compact through a transfer
    - fs_read catches MemoryError -> reports "oom" inst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
    [code.py, firmware_sim_test.py, ui.py]
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2026-07-24 Fail keys soft when the USB stack rejects a HID report
    A partial firmware update (new engine.py, stale boot.py) leaves the
    enumerated HID descriptor one report layout behind: every macro play
    then dies in release_all() with ValueError("report length must be 6"),
    which play_file did not catch, so each key press hit the fatal handler
    and soft-rebooted the device forever (soft reload never re-runs
    boot.py, so the loop could not heal).
    play_file now catches ValueError and reports {"code":"hid"} to the app
    with an LED error blink instead of taking the device down; a power
    cycle re-runs boot.py and heals the mismatch. Documented the err code
    and added a sim regression test.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
    [code.py, firmware_sim_test.py]
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2026-07-24 Hold single keys like a real keyboard + Vision layer/profile band
    - Plain single-key macros now keep the HID key down while the physical
    key is held: the host's typematic repeat types eeee... at the user's
    own rate. Default on for keystroke assignments (opt-out stored only
    as a deviation); serial play accepts hold:true (proto v5, issue #20).
    - Vision 6: optional status band over the grid showing the active layer
    and/or the profile label the app pushes (t:"label"); toggled from the
    app Settings or on the device, stored as config show_layer /
    show_profile. Cleared automatically when the app disconnects.
    - Firmware 0.9.0; docs, sim tests and fixtures updated.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
    [code.py, firmware_sim_test.py, i18n.py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]
2026-07-24 Open the whole menu system to the user (issue #19)
    Every Vision 6 control is now programmable per context and per gesture,
    and the app shows the default programming so it reads as customizable.
    - New slot: the wheel's own push (btn-psh), assignable like the others —
    standalone and in per-app profiles.
    - Per-context overrides: beyond the resting grid, each slot can be
    reassigned separately on the layer picker (macros/<slot>@home.json)
    and inside settings (macros/<slot>@menu.json); global files, layerless.
    An absent file keeps that context's built-in navigation.
    - Key logic on button slots: double/long press variants resolved by the
    menu module from its own nav events (scenario: w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
    [code.py, firmware_sim_test.py, models.py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]
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2026-07-24 Fix wheel cursor teleport, add wheel acceleration + host-mode profile grid
    Three profile-wheel complaints from the field (Photoshop profile, wheel =
    scroll/zoom):
    - Scrolling teleported the cursor to screen center. The mouse HID device
    was a single absolute report, so every scroll tick (and release_all at
    every macro start/end — even keyboard-only ones) re-asserted the last
    known X/Y, which after boot is dead center. The interface is now two
    reports (pointer id 2: buttons + abs X/Y; scroll id 4: wheel + pan):
    scroll and keyboard macros never touch the cursor. Needs a power-cycle
    after the firmware update (boot.py re-runs the descriptor).
    - The wheel felt sluggish and never ac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
    [boot.py, code.py, engine.py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]
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2026-07-24 Unbrickable updates: rescue console, .mpy firmware, locked update mode (proto v7)
    A Vision 6 bricked in the field: a firmware update over the visible
    CIRCUITPY drive triggered one auto-reload per copied file (running
    half-updated trees until one crashed), and the next boot died compiling
    ui.py from source — a MemoryError the ImportError-only guard never caught.
    The dead code.py stopped draining usb_cdc.data, so the host's writes
    backed up into "semaphore timeout" errors and the app could no longer see
    the keypad at all. This release makes that whole class of failure
    impossible to hit and recoverable even when it somehow is.
    Firmware (0.11.0, proto v7):
    - code.py is now a tiny builtins-onl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
    [app.py, boot.py, code.py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]
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2026-07-24 Fix Vision 6 loading-screen freeze + finished-product install defaults
    Issue #22: a Vision 6 could boot straight into an endless "loading"
    screen. Root cause: a partial/interrupted update left source mkyada
    modules on the device; CircuitPython imports the leftover ui.py over
    ui.mpy, and compiling the 38KB source on the display-fragmented heap
    MemoryErrors, so Ui stays None and the menu never draws while keys and
    serial keep working.
    Firmware:
    - run_loop now shows a clear headless status screen (menu_fail /
    "reinstall from app") instead of leaving the boot splash frozen when
    the menu module fails to load — the keypad reads as working, and the
    app can reinstall the .mpy tree. (oled.sh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
    [app.py, i18n.py, models.py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]
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2026-07-24 Default USB drive to hidden on fresh firmware install
    A from-scratch install (no config.json, or a config without an explicit
    usb_drive key) used to come up with the CIRCUITPY drive visible — the
    documented "config-less = visible" safe default. That contradicts the
    finished-product intent: a freshly-flashed board should start in
    hidden-drive mode with the app managing files over serial.
    Flip the default so the drive is shown ONLY when config.json sets
    "usb_drive": true. Absent/unreadable config now keeps it hidden.
    - boot.py: usb_drive_wanted() `is not False` -> `is True`; the hold-key-1
    recovery escape hatch is unchanged (forces the drive back for a session).
    - app.py: DEFAULT_CONFIG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
    [app.py, boot.py]
2026-07-24 Vision 6 device settings + Setup test/wiring, spinner fix (#21 #24 #25 #27)
    #21 Firmware-update overlay spun a counter-clockwise glyph (RotateCcw) under a
    clockwise animation, reading as backwards — swapped to RotateCw.
    #27 A config rewrite from Setup dropped the Vision 6 band toggles because
    defaultConfig() omitted show_layer/show_profile, so the firmware fell back to
    both-off ("settings disappeared"). defaultConfig now carries them (profile band
    on) and Setup preloads the device's live values, so a rewrite never clobbers
    what the on-device menu / Settings set.
    #25 Font size + auto-return were NVM-only, invisible to the app. Firmware now
    mirrors them into config.json (persist_cfg) and r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
    [app.py, firmware_sim_test.py, i18n.py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]
2026-07-24 Profiles run natively on the device as a full config copy (issue #23)
    A per-app profile is now an independent config the keypad runs itself instead
    of the app holding host mode: on match the app sends {t:"profile", id} and the
    firmware redirects its macro paths to that profile's files (proto v8, firmware
    0.16.0). So the on-device grid, wheel and speed editor all keep working under a
    profile, and speed edits copy-on-write into the profile's own file — a macro
    that's 2x globally can be 3x for one app.
    A profile is a FULL, independent config: a new one is seeded as a copy of the
    keypad's own key setup, and a key cleared to "Not assigned" does nothing for
    that app — no fallback to the globa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
    [app.py, firmware_sim_test.py]
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2026-07-25 Show Turkish on the OLED only on the font that renders it (v0.21.1, fw 0.17.3)
    App-entered Turkish names (macro names, profile labels, OBS scene names)
    must display readably on the device. Font reality (verified from the BDF
    files): only the 4x6 (Small) font has real Turkish glyphs; spleen (Medium)
    carries BLANK bitmaps for ç ö ü Ç Ö Ü and lacks ğ ı İ ş Ğ Ş entirely; the
    built-in Large font is ASCII. A runtime get_glyph probe is unreliable —
    it returns a non-None blank/notdef glyph for those, so the letter renders
    as a dropped/missing character.
    So oled.py decides per font deterministically: FULL_TURKISH_FONTS lists
    the fonts that ship real glyphs (just 4x6), tracked as self.g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
    [oled.py]
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2026-07-25 Add an About screen to the on-device settings menu (issue #32, v0.21.3, fw 0.17.4)
    The device Settings menu gains an "About" entry (before Restart) that
    shows the model, firmware version and a short device id — the same info
    the app reads over the serial hello, now visible without a computer.
    - new SET_ABOUT settings item + S_ABOUT state, an info screen that any
    key press (or the idle timeout) dismisses back to the menu;
    - Oled.show_about() renders left-aligned "label: value" rows;
    - App caches its board UID as self.uid so the screen can show it;
    - i18n: about/about_title/model/firmware/device_id in en + tr.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
    [app.py, i18n.py, oled.py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]
2026-07-25 Keys tab never fires macros on any model + focus-aware (issue #33, v0.21.4, fw 0.17.5)
    Opening the Keys tab is a key *test* — pressing a physical key there used
    to fire its macro on core6 (test mode was gated on the presence of an OLED,
    so only Vision 6 suppressed playback). Now the app puts the device in test
    mode from the Keys tab too, and firmware suppresses macro playback on EVERY
    model.
    - app.py: {t:"test_enter"} now sets test_mode unconditionally (not bool(OLED))
    and carries a "ui" hint ("wiring" for Setup, "keys" for the Keys tab).
    core6 stays quiet (ui_call is a no-op without a screen).
    - ui.py: on_test_enter/on_test_key show a "Macros paused — use another tab"
    warning on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
    [app.py, i18n.py, ui.py]
2026-07-25 Optional per-layer nicknames on the device layer band (issue #34, v0.21.5, fw 0.17.6)
    A layer can be given a nickname that only changes how the keypad's screen
    labels it: the band shows "(A) YAYIN KISAYOLLARI" instead of "Layer A".
    The app (and the software everywhere else) keeps calling layers A/B/C/D —
    the nickname is display-only on the device.
    - config: new "layer_names" (list aligned to layers, index 0 = A). Parsed and
    clamped in load_config (<= layer_count entries, blanks -> null, 20 chars
    max), echoed in hello, default null.
    - ui.py _band(): a set nickname wins, rendered "(A) NAME"; otherwise the plain
    "Layer A" as before.
    - app: DeviceConfig/Hello gain layer_names; Settings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
    [app.py, ui.py]
2026-07-25 Assignable "Go to layer X" device action, works on core6 too (issue #30, v0.21.6, fw 0.17.7)
    Alongside the relative Next/Previous layer actions, a key (or Vision 6
    module control) can now jump straight to a specific layer. The app offers
    one "Go to layer A..X" row per layer that actually exists.
    - types/MenuAction: new layer_a..layer_h; MENU_LABEL + MENU_ICON entries
    (reusing the layer-screen glyph). compile/parse already pass menu actions
    through unchanged.
    - AssignmentEditor/Panel: a layerCount prop generates exactly the existing
    layers' rows; threaded through the variant editors too. KeysPage passes the
    raw layer_count (a jump key is itself how you reach layers without a
    dedica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
    [app.py, ui.py]
2026-07-25 Fix firmware update crashing at the spleen font (open-file overwrite) (v0.21.7, fw 0.17.8)
    Serial firmware updates on Vision 6 died at fonts/spleen-5x8.bdf: the app's
    transfer failed there and the update never completed. Root cause is an open
    file handle — adafruit_bitmap_font keeps /fonts/*.bdf open for the device's
    whole runtime (glyphs rasterize lazily off disk), and spleen is the always-
    loaded UI font. The device's fs_write does os.remove + rename on eof, but FAT
    can't remove/rename a file that's still open, so writing the in-use font
    returned an io error and aborted the transfer. (4x6 wrote fine because the
    default grid font is the built-in one, so 4x6.bdf isn't held open.)
    Two-side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
    [app.py, oled.py]
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
